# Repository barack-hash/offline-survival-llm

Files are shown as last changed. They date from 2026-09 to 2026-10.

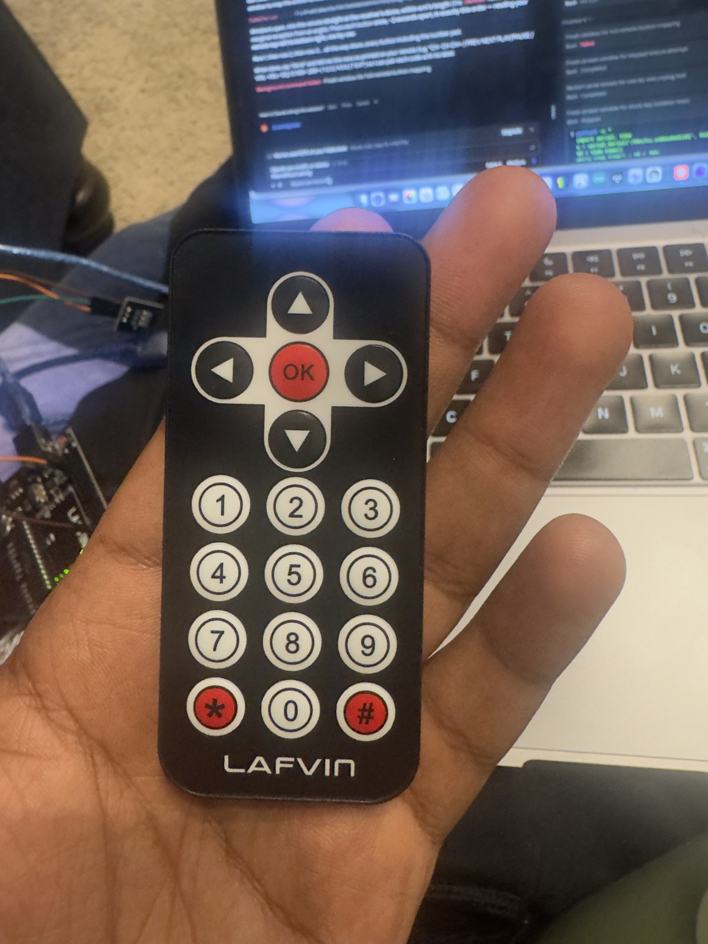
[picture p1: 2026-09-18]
docs/wiring/2026-09-18-ir-remote.jpg

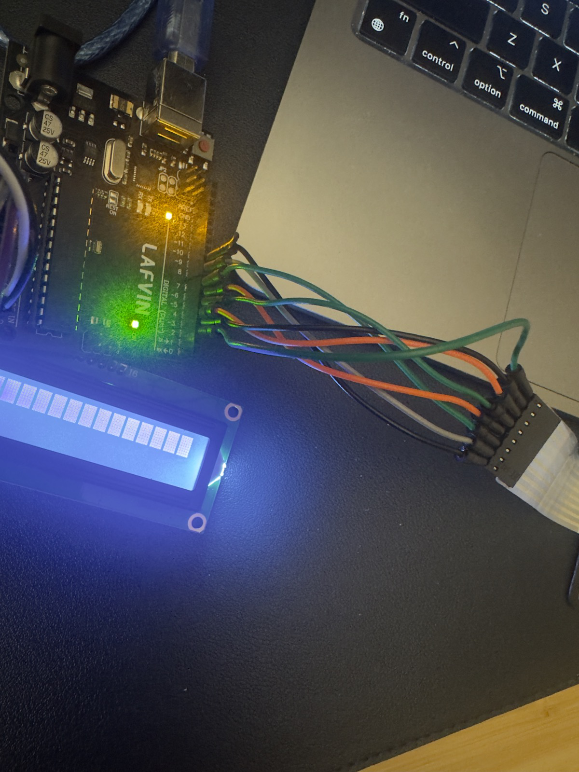
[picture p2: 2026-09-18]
docs/wiring/2026-09-18-uno-lcd-keypad-wiring.jpg

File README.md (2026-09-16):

# Offline Survival LLM Device

A portable, fully offline reference device: Raspberry Pi 5 running a
local LLM (Qwen2.5-3B-Instruct via llama.cpp) grounded in a curated library of
public-domain survival and rebuilding manuals via RAG. Physical keypad
input (Arduino), e-ink display, battery + solar power. Built for use
during outages and disasters — no internet required after setup.

**This device is a reference aid, not a sole authority.** For anything
safety-critical (medical dosing, structural loads, electrical work), it
shows verbatim source text and warns when only one source backs a claim —
and you should still cross-check against a second source before acting.

## Project documents
- `IMPLEMENTATION_PLAN.md` — phase-by-phase build plan with acceptance criteria
- `CLAUDE.md` — operating + logging rules for Claude Code
- `BUILD_PLAN.md` — original architecture and design decisions
- `CORPUS_CHECKLIST.md` — the knowledge library gathering checklist
- `docs/BUILD_LOG.md` — dated journal of every session: mistakes, fixes, decisions
- `docs/HARDWARE.md` — every tool and component used
- `docs/CORPUS_SOURCES.md` — provenance of every reference text

## Status
Phases 0-5a in progress (software brain + keypad input). Awaiting
hardware for: e-ink display (5b), UPS battery (6), enclosure (7).

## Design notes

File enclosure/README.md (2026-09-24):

# Enclosure (Phase 7) — DRAFT v0.6, not print-ready

Parametric OpenSCAD model of a handheld enclosure: 4.2" e-ink screen on top,
CardKB keyboard below, Pi 5 + Geekworm X1202 UPS + 4× 18650 stacked behind
the screen only. Outer size ≈ 109 × 170 mm; **61 mm deep behind the screen,
11.4 mm at the keyboard** (+4 mm standoff feet), joined by a sloped step.

**Airflow:** the Pi faces the back wall so its cooler fan breathes through a
porthole grille; the battery pack sits between the Pi and the e-paper panel
as a heat shield. Cool air in: porthole + low side vents. Hot air out: upper
side louvers + top-edge vents. Feet keep the porthole clear when lying flat.
Toggle **Airflow** in the viewer to see the paths.

**Plumbing is functional:** the copper pipes are cable conduits (3/8" tube).
Left = data line (USB port, AUX I2C accessory port, status-light gauge);
right = power line (6-18 V solar/car input, valve-wheel power button). Both
end at the junction box under the step. The top loops double as corner roll
bars. Wiring plan: `docs/wiring/plumbing-conduits.md`.
Overall with plumbing ≈ 135 × 189 × 67 mm (incl. lanyard tab and feet).

Confirmed from manufacturer specs: e-ink board 103.0 × 78.5, display area
84.8 × 63.6, panel 90.1 × 77.0 × 1.18 (Waveshare manual); CardKB v1.1
88.0 × 54.0 × 5.0 (M5Stack store); X1202 PCB 97.4 × 85 (Geekworm wiki).

**Do not send these STLs to a print service yet.** Several component sizes
come from datasheets and listings rather than the actual parts; each one is
marked `VERIFY` in `enclosure.scad`. When the parts arrive, measure them
with calipers, update the numbers, and re-render.

## Files
- `enclosure.scad` — the model; every dimension is a named parameter
- `render.sh` — re-renders every part and the viewer's `stl/layout.json`
- `stl/` — rendered parts: `tub`, `bezel`, `retainer`, `trim`, `pipes`, `fittings`,
  `manifold`, `manifold_lid`, `gauge_face`, `valve_cap` (printed) and
  `ghost_*` (stand-ins for the electronics, for the viewer only)
- `viewer.html` — 3D viewer (orbit, explode, show/hide parts)

## Re-render
```bash
./render.sh
```
View: `python3 -m http.server 8765` in this folder, then open
http://localhost:8765/viewer.html (the STLs can't load from `file://`).

## Hardware for assembly
- 4× M3 heat-set inserts + 4× M3 button-head screws (bezel to tub)
- 6× M2 self-tapping screws (retainer to bezel posts)
- Optional: rubber caps on the four printed feet
- `trim` (porthole gear ring) and `pipes` (both side pipe runs) print best in brass / copper filament, flat back down; glue on

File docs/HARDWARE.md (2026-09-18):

# Hardware & Tools Register

| Item | Model/Details | Source | Cost | Used for | First used |
|---|---|---|---|---|---|
| Raspberry Pi 5 | Model B Rev 1.1, 8GB RAM, 128GB microSD (117G usable), Debian 13 trixie, kernel 6.18.50+rpt-rpi-2712 | (fill in) | (fill in) | Main compute | 2026-09-15 |
| Active cooler (fan+heatsink) | 4-pin FAN header, ~1150 RPM idle / ~3600 RPM load | (fill in) | (fill in) | Pi 5 cooling — required to avoid thermal throttling during inference | 2026-09-15 |
| Arduino starter kit | LAFVIN Super Starter Kit for UNO R3 | (fill in) | (fill in) | Physical input + interim display | 2026-09-16 (identified from kit box photo) |
| Arduino UNO R3 (from kit) | LAFVIN clone, ATmega328P | kit | — | Input controller: IR decode, multi-tap, LCD driving, serial link to Pi | 2026-09-18 |
| LCD1602 w/ I2C backpack (from kit) | 16x2 chars, I2C addr 0x27, contrast trim on backpack | kit | — | Interim answer display until e-ink (5b) | 2026-09-18 |
| IR remote + receiver (from kit) | NEC protocol, 17 buttons (arrows/OK/0-9/*/#); receiver module pins G/R/Y | kit | — | Text input via multi-tap — replaced the defective keypad | 2026-09-18 |
| 4x4 membrane keypad (from kit) | **DEFECTIVE** — internal shorts, ribbon lines 1-8 and 4-6 permanently closed (stuck 'A'/'0') | kit | — | Unusable; kept as spare parts. Replacement optional (issue #6) | 2026-09-18 |

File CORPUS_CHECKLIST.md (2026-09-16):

# Offline Knowledge Library — Document Checklist

How to use this: for each item, mark it gathered once the actual text file
(.txt or .pdf) is sitting in your `corpus/` folder. "PD" = public domain,
safe to download directly. "OWN" = copyrighted; buy a physical/legal digital
copy and OCR/scan it yourself for personal use — don't download pirated
copies. "FREE" = freely distributed by the publisher for personal/humanitarian
use, but not public domain (check the license before wide redistribution).

---

## 1. Fire & Energy
- [x] U.S. Army Survival Manual, FM 21-76 — fire-starting methods (PD) — in corpus since Phase 3
- [x] Basic solar/wind power primer (any out-of-copyright physics/engineering text, PD) — Powell, Windmills and Wind Motors 1910
- [ ] Notes on your own generator/dynamo build once you've tested it (your own writing)

## 2. Water & Sanitation
- [x] FM 21-76 — water procurement and purification sections (PD) — in corpus since Phase 3
- [x] Where There Is No Doctor (Hesperian) — sanitation chapters (FREE) — full book in corpus (owner-supplied PDF)
- [ ] Basic water filtration / distillation reference (PD engineering text)

## 3. Food & Agriculture
- [x] FM 21-76 — edible/poisonous plants, trapping, fishing (PD) — in corpus since Phase 3
- [x] Old public-domain farming/gardening manuals (pre-1929, archive.org) (PD) — Goodrich, First Book of Farming 1905
- [x] Basic food preservation reference — canning, smoking, drying (PD or FREE) — Gray, Every Step in Canning 1920

## 4. Shelter & Construction
- [x] FM 21-76 — shelter building section (PD) — in corpus since Phase 3
- [x] Basic carpentry/masonry primer, public domain edition (PD) — Fairham, Woodwork Joints 1921 (carpentry; masonry still open)
- [ ] Your own notes once you test any shelter/heating builds (your own writing)

## 5. Medicine & First Aid
- [x] Where There Is No Doctor (Hesperian) (FREE) — owner-supplied PDF, 2026-09-15
- [x] Where There Is No Dentist (Hesperian) (FREE) — owner-supplied PDF, 2026-09-15
- [x] U.S. military first-aid field manual (PD) — FM 21-11 First Aid for Soldiers 1943
- [ ] Basic public-domain herbal medicine reference — flag clearly as unverified/folk knowledge, not medical advice

## 6. Tools & Metalworking
- [x] Public-domain blacksmithing/metalworking texts (pre-1929, archive.org) (PD) — Practical Blacksmithing 1889 + Woodworth 1903
- [ ] Basic mechanics/machining primer (PD)
- [ ] *The Knowledge* by Lewis Dartnell — metallurgy chapters (OWN)

## 7. Chemistry & Materials
- [x] Public-domain basic chemistry textbook (soap-making, basic acids/bases, PD) — McPherson & Henderson 1906
- [ ] *The Knowledge* — chemistry/materials chapters (OWN)

## 8. Electronics & Communication
- [x] Basic electricity/electronics primer, public-domain edition (PD) — Morgan, The Boy Electrician 1913
- [ ] Your own build notes on the generator/battery-charging project (your own writing)
- [x] Basic radio theory reference, if you want this covered eventually (PD) — Collins, Radio Amateur's Hand Book 1922

## 9. Navigation & Orientation
- [x] FM 21-76 — land navigation section (PD) — in corpus since Phase 3
- [x] Basic celestial navigation primer, public domain (PD) — Draper, *Lectures in Navigation* 1917

## 10. Knots, Cordage & Textiles
- [x] Public-domain knot-tying reference (PD) — Verrill, *Knots, Splices and Rope Work* 1912
- [ ] Basic fiber/rope-making and weaving primer (PD)

## 11. Foundational / Cross-Cutting References
- [ ] *The Knowledge: How to Rebuild Civilization in the Aftermath of a Cataclysm* — Lewis Dartnell (OWN) — the single broadest reference; worth prioritizing
- [x] Full FM 21-76 U.S. Army Survival Manual, in case you only grab it in pieces above (PD) — full manual in corpus

---

## Non-corpus documents worth keeping alongside the project
These aren't for the device's library, but you'll want them as you build:

- [ ] **Bill of Materials (BOM)** — running list of every part bought, cost, and source link
- [ ] **Wiring diagrams** — keypad pinout, display connections, power HAT connections (hand-drawn is fine)
- [ ] **Build log** — dated notes on what you tried, what worked, what didn't (this becomes genuinely valuable once you're troubleshooting months from now)
- [ ] **verify.py test question list** — growing over time, as discussed earlier
- [ ] **Corpus source log** — which document came from where, what edition/date, so you can judge reliability later

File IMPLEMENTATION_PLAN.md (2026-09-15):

# IMPLEMENTATION PLAN — Offline Survival LLM Device
Target: Raspberry Pi 5 (8GB / 128GB), currently connected to internet + monitor.
GitHub: github.com/barack-hash/offline-survival-llm
Executor: Claude Code (see CLAUDE.md for logging rules that apply to EVERY phase).

Scope of this plan: everything achievable with hardware on hand today
(Pi 5 + Arduino starter kit). Phases blocked on unpurchased hardware
(e-ink module, UPS HAT, enclosure) are included as stubs at the end so
the repo structure anticipates them.

---

## PHASE 0 — Repository + logging scaffolding
Goal: a clean git repo with logging infrastructure BEFORE any build work,
so nothing goes unlogged from the first command onward.

Steps:
1. Create project directory `~/offline-survival-llm` and `git init`.
2. Create this structure:
   ```
   offline-survival-llm/
   ├── README.md
   ├── CLAUDE.md
   ├── IMPLEMENTATION_PLAN.md   (this file)
   ├── BUILD_PLAN.md
   ├── CORPUS_CHECKLIST.md
   ├── docs/
   │   ├── BUILD_LOG.md         (dated session log — template provided)
   │   ├── HARDWARE.md          (every tool & part used — template provided)
   │   └── wiring/              (photos + diagrams, added as hardware phases run)
   ├── corpus/                  (reference texts; see .gitignore rules)
   ├── models/                  (GGUF files; gitignored, too large)
   ├── scripts/
   │   ├── setup.sh
   │   ├── rag_build.py
   │   ├── main.py
   │   ├── verify.py
   │   └── keypad_serial.ino
   └── .gitignore
   ```
3. Write .gitignore (provided) — CRITICAL rules:
   - `models/` — multi-GB files, never committed.
   - `index.faiss`, `chunks.pkl` — regenerated artifacts.
   - `corpus/own/` — any scanned COPYRIGHTED material (e.g. The Knowledge)
     lives only in this subfolder and is NEVER pushed to a public repo.
     Public-domain texts go in `corpus/pd/` and MAY be committed.
   - `venv/`, `__pycache__/`
4. First commit: scaffolding only. Then create the GitHub repo under
   barack-hash and push. (If `gh` CLI is available: `gh repo create
   barack-hash/offline-survival-llm --public --source=. --push`.
   Otherwise create on github.com and add the remote manually.)
5. Log Phase 0 completion in docs/BUILD_LOG.md per CLAUDE.md rules.

Acceptance criteria:
- [ ] Repo exists on GitHub with scaffolding pushed.
- [ ] BUILD_LOG.md has its first dated entry.
- [ ] .gitignore verified by `git status` showing models/ and corpus/own/ untracked.

---

## PHASE 1 — System verification & prep
Goal: confirm the Pi is healthy and configured before heavy installs.

Steps:
1. Record in docs/HARDWARE.md: Pi model, RAM, storage, OS version
   (`cat /etc/os-release`, `uname -a`, `free -h`, `df -h`, `vcgencmd measure_temp`).
2. `sudo apt update && sudo apt full-upgrade -y`.
3. Enable SPI via `sudo raspi-config nonint do_spi 0` (needed for e-ink later).
4. Confirm active cooling works: run `stress` or a build for 2 minutes,
   log idle vs load temperature in BUILD_LOG.md.
5. Commit any config notes; log the session.

Acceptance criteria:
- [ ] OS fully updated; reboot clean.
- [ ] SPI enabled.
- [ ] Idle + load temperatures logged (expect roughly 45-55°C idle, under
      75°C load with the official cooler; log whatever is observed).

---

## PHASE 2 — LLM engine
Goal: llama.cpp built from source, model downloaded, benchmarked, working.

Steps:
1. Run `scripts/setup.sh` (builds llama.cpp, downloads Phi-3 Mini Q4 GGUF
   ~2.3GB, creates Python venv with dependencies).
2. If the model URL 404s (Hugging Face paths change): search Hugging Face
   for "Phi-3-mini-4k-instruct-gguf" Q4 quantization, update the URL in
   setup.sh, and LOG THE CHANGE as a challenge+fix in BUILD_LOG.md.
3. Benchmark: run llama-cli with a fixed test prompt, record tokens/sec
   for prompt processing and generation. Log exact numbers.
4. Log RAM usage during inference (`free -h` in a second terminal).
5. Commit setup.sh if modified; log the session including benchmark table.

Acceptance criteria:
- [ ] Model answers a test question from the command line.
- [ ] Benchmark logged (expect roughly 5-10 tok/s generation; log actuals).
- [ ] RAM headroom confirmed (expect >3GB free during inference).

---

## PHASE 3 — Knowledge corpus + RAG index
Goal: real public-domain reference texts indexed and searchable.

Steps:
1. Create `corpus/pd/` and `corpus/own/` folders.
2. Download public-domain sources per CORPUS_CHECKLIST.md, starting with:
   - U.S. Army Survival Manual FM 21-76 (public domain; archive.org hosts it)
   - At least one more PD text (old farming/blacksmithing manual from archive.org)
   Log EVERY source in docs/BUILD_LOG.md AND a new docs/CORPUS_SOURCES.md:
   filename, origin URL, edition/date, license status (PD/FREE/OWN).
3. Run `scripts/rag_build.py`. Log chunk counts per source and total
   index build time.
4. Spot-check retrieval: query 3 known topics (fire, water purification,
   shelter) and confirm relevant chunks return. Log results.
5. Commit corpus/pd files + CORPUS_SOURCES.md; log the session.

Acceptance criteria:
- [ ] At least 2 PD sources indexed.
- [ ] index.faiss + chunks.pkl generated (untracked by git).
- [ ] 3 spot-check retrievals logged with pass/fail judgment.

---

## PHASE 4 — Main application + verification loop
Goal: full ask→retrieve→answer pipeline working in the terminal, with a
growing test suite.

Steps:
1. Run `scripts/main.py` in keyboard mode. Ask 10 varied questions
   spanning: normal survival topics, a safety-critical topic (to confirm
   strict mode triggers + shows verbatim sources), and a topic NOT in the
   corpus (to confirm it says "not in sources" rather than hallucinating).
2. Log every question + answer + verdict (good / vague / wrong / hallucinated)
   in BUILD_LOG.md. This is the single most valuable log content in the
   whole project.
3. For each failure found, make ONE tuning change at a time (prompt wording,
   TOP_K, chunk size, keyword list), re-test, and log change→effect.
4. Add the best test questions into scripts/verify.py's test_cases list.
5. Commit tuning changes with descriptive messages; log the session.

Acceptance criteria:
- [ ] 10-question evaluation logged with verdicts.
- [ ] Critical mode confirmed triggering and showing raw sources.
- [ ] Out-of-corpus question correctly declined, not hallucinated.
- [ ] verify.py contains at least 5 real test cases and runs clean.

---

## PHASE 5a — Physical input (Arduino keypad)
Goal: questions typed on real hardware buttons instead of a keyboard.

Steps:
1. Wire the starter-kit 4x4 matrix keypad to the Arduino per the pin map
   in scripts/keypad_serial.ino. PHOTOGRAPH the wiring; save to docs/wiring/.
2. Flash keypad_serial.ino via Arduino IDE. Log IDE version, board type,
   any library installs (Keypad library), and any upload problems + fixes.
3. Connect Arduino→Pi via USB. Identify the port (`ls /dev/ttyACM*`).
4. Set INPUT_MODE = "serial" in main.py, run, and type a question on the
   keypad. Log the first successful hardware-typed question verbatim —
   that's a milestone worth recording.
5. Known limitation to log honestly: digits + A-D only until multi-tap
   letter entry is implemented. Create a GitHub issue for multi-tap as
   the next input improvement.
6. Update docs/HARDWARE.md (Arduino board, keypad, cables). Commit; log.

Acceptance criteria:
- [ ] Wiring photo in docs/wiring/.
- [ ] A question asked entirely via keypad receives an answer.
- [ ] Multi-tap letter entry filed as a tracked issue.

---

## PHASE 5b — E-ink display integration  [STUB — awaiting hardware]
When the ELECROW ESP32-S3 2.13" e-paper module arrives:
- Firmware sketch for the ESP32-S3 (serial listener → render text).
- main.py output routed to second serial port.
- Wiring/pairing notes + photos to docs/wiring/.

## PHASE 6 — Power system  [STUB — awaiting hardware]
When the Pi 5 UPS HAT + 18650 cells arrive:
- Runtime measurement vs the theoretical ~5hr estimate; log actuals.
- Wi-Fi/BT disable script + CPU governor for battery mode.
- Safe-shutdown-on-low-battery configuration.

## PHASE 7 — Enclosure  [STUB — awaiting materials]
- Dimension sketch once display size is physically confirmed.
- Steampunk build log with photos at every assembly step.

---

## Definition of "done" for the current hardware scope
Phases 0-5a complete, every acceptance criterion checked, every session
logged, repo pushed, and stub issues created on GitHub for 5b/6/7 so the
project board reflects reality.

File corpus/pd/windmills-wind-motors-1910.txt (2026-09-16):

Google 

This is a digital copy of a book that was preserved for generations on library shelves before it was carefully scanned by Google as part of a project 

to make the world's books discoverable online. 

It has survived long enough for the copyright to expire and the book to enter the public domain. A public domain book is one that was never subject 

to copyright or whose legal copyright term has expired. Whether a book is in the public domain may vary country to country. Public domain books 

are our gateways to the past, representing a wealth of history, culture and knowledge that's often difficult to discover. 

Marks, notations and other maiginalia present in the original volume will appear in this file - a reminder of this book's long journey from the 

publisher to a library and finally to you. 

Usage guidelines 

Google is proud to partner with libraries to digitize public domain materials and make them widely accessible. Public domain books belong to the 
public and we are merely their custodians. Nevertheless, this work is expensive, so in order to keep providing tliis resource, we liave taken steps to 
prevent abuse by commercial parties, including placing technical restrictions on automated querying. 
We also ask that you: 

+ Make non-commercial use of the files We designed Google Book Search for use by individuals, and we request that you use these files for 
personal, non-commercial purposes. 

+ Refrain fivm automated querying Do not send automated queries of any sort to Google's system: If you are conducting research on machine 
translation, optical character recognition or other areas where access to a large amount of text is helpful, please contact us. We encourage the 
use of public domain materials for these purposes and may be able to help. 

+ Maintain attributionTht GoogXt "watermark" you see on each file is essential for in forming people about this project and helping them find 
additional materials through Google Book Search. Please do not remove it. 

+ Keep it legal Whatever your use, remember that you are responsible for ensuring that what you are doing is legal. Do not assume that just 
because we believe a book is in the public domain for users in the United States, that the work is also in the public domain for users in other 
countries. Whether a book is still in copyright varies from country to country, and we can't offer guidance on whether any specific use of 
any specific book is allowed. Please do not assume that a book's appearance in Google Book Search means it can be used in any manner 
anywhere in the world. Copyright infringement liabili^ can be quite severe. 

About Google Book Search 

Google's mission is to organize the world's information and to make it universally accessible and useful. Google Book Search helps readers 
discover the world's books while helping authors and publishers reach new audiences. You can search through the full text of this book on the web 

at |http: //books .google .com/I 

> 

WINDMILLS 

AND 

WIND MOTORS 

HOW TO 

BUILD AND RUN THEM 

BY 

F. E. POWELL 

Folly Illustrated with Detail Drawimo* 

NEW YORK 

SPON & CHAMBERLAIN 

123-125 LIBERTY STREET 

1910 

(N<x 36.) 

• Copyright, 1910 

By SPON & CHAMBERLAIN 

GAMELOT PRESS. 444-46 Pearl Street, New York 

PREFACE 

I have endeavoured in the following pages not 
only to interest the practical amateur in a branch 
of mechanics unfortunately much neglected, but 
also to present a series of practical original de- 
signs that should prove useful to every reader 
from the youngest to the most advanced. This 
is admittedly a large undertaking, and would be 
of doubtful wisdom, but for the sparseness of the 
literature of the subject. There is, however, 
no other book in the language, large or small, 
dealing with the matter in the way here pre- 
sented, and indeed only one other, as far as I 
know, having the subject of windmills for its 
sole topic. I venture to hope therefore that this 
little book will help to arouse something of the 
interest the subject deserves but has not hitherto 
received. 

That I am right in claiming for the wind 
motor a more serious recognition I am con- 
vinced, and particularly is this the case in re- 
"•^rd to the model engineer. At present there 
every prejudice against wind-power on ac- 
count of its uncertainty, against which even its 

inexpensiveness has not been able to contend. 

... 
Ill 

IV PREFACE 

If it can once be realised, however, that the un- 
certainty can be reduced to little or no import- 
ance, so much that even a petrol-engine might 
seem unreliable and troublesome beside it, the 
claim put forward for the windmill is fully sub- 
stantiated. Not less than this is one of the aims 
of this little book, and it is one which I confi- 
dently expect will be upheld. 

In a book like this, trenching upon new ground, 
where every design has been the outcome of 
careful consideration unaided by the experience 
of others, it is not unlikely that errors or am- 
biguities may have crept in. The reader who 
finds any such, or who meets with difficulties of 
any sort, will confer a kindness by communicat- 
ing them to the author through the publishers. 

R E. POWELL. 

CONTENTS 

PAGE 

Preface iii 

CHAPTER I 

WINDMILL EVOLUTION 

Ancient post-mill. Tower mill. Tower mill 
with regulating or wind-wheel. Modern 
type of windmill. Anemometer. Jumbo or 
horizontal windmill. Wind-motor with ver- 
tical axle. The pantanemone i 

CHAPTER H 

A MODEL WORKING WINDMILL 

Tower mill type. Fixed sails without tail 
regulator. Diameter across sails, two feet. 
Full detailed drawings 1 1 

CHAPTER HI 

A SMALL AMERICAN TYPE WINDMILL 

This type has fixed metal sails three feet in 
diameter, with tail regulator. Develops 
about Yso H.P. Full detailed drawings 22 

VI CONTENTS 

CHAPTER IV 

A SMALL WORKING WINDMILL 

PAGE 

Automatically reversing sail type. Diameter 
across sails, six feet. Develops about Ko 
H.P. Suitable for pumping water or for 
running a lathe. Full detailed drawings. . . 37 

CHAPTER V 

A PRACTICAL WORKING WINDMILL 

A simple and compact wind-power motor with 
adjustable sails and tail regulator. Diam- 
eter across sails ten feet. Will develop 
from one-quarter to one-half horse-power, 
according to the velocity of the wind. Suit- 
able for pumping water, driving a dynamo 
or light farm machinery. Full detailed 
drawings 48 

CHAPTER VI 

PRODUCTION OF ELECTRICITY BY WIND-POWER 

Diagram of connections for a wind-driven 
electrical installation. Driving belt ar- 
rangement for wind electrical plant. Table 
of wind pressures and velocities 65 

CHAPTER I 
Windmill Evolution 

It is not a little strange that amateur engi- 
neers should have so neglected the windmill, 
either as a subject for model-making and experi- 
ment, or even for the more practical purpose 
of power production. Wind-power is free, and 
while it is admittedly erratic it must surely ap- 
peal to the mechanical, mind as a labour saver 
of some value. The probability is that the lack 
of simple published designs is the main reason 
for this state of things, and the aim of this little 
book is to remedy it. 

Few mechanical appliances have a simpler his- 
torical record than the windmill. Until com- 
paratively recent years only two main types of 
mill were ^9mmonly in use, known respectively 
^|nd the Tower mills, vhe former, 
is the earlier machine, was distinguished 
by the fact that the whole building, carrying 
sails, house, cap, and all machinery, was pivoted 
on a huge timber post, so that the whole struc- 
ture had to be removed when it was necessary 
to adjust the mill to face the windJ The Tower 
mill, called also the " Smock " and sometimes 
the " Frock " mill, was an improvement on the 

2 WISDMILLS- AXD WISD MOTORS 

Other in having the cap only to revolve, carrjing 
with it the sails and (later) the automatic regu- 
lating mechanism for bringing the sails round 

" into the wind." Illustrations of these two 
types of mills are given in figs, i and. 2. 
/ As hinted above, the automatic method of con- 
I trolling the mill so that the sails should face the 
1 wind was a fairly recent innovation. It dates 
I back to the middle of the eighteenth century, 

WINDMILL EVOLUTION 

when Andre w Meikle introduced the now well- 
ktlown auxiliary 'regulating wheel, which may 
be seen in fig. 3 

Fig. 2.— Tower Milt: at Hillerod, Denmark. 

Another advance in windmill construction was 
made in 1807, when Sir W, Cubitt introduced an 
automatic reefing arrangement for the sails. Be- 

4 WINDMILLS AND WIND MOTORS 

fore that date speed was more or less outside 
the control of the operator, who could only throw 
in or out his machinery as the speed ranged too 

Fig. 3.— Towi 

with Regulating or Wind Wheel. 

high or too low, or by the application of brakes 
could keep it partly within bounds. 

The later history of the development of wind- 
mills must be looked for abroad. The inventor 
of the "American" mill is said to have been 
John Burnham, whose location is sufficiently in- 

WINDMILL EVOLUTION 5 

dicated in the name by which this type is known. 
The date was about the middle of the nineteenth 
century. Everyone knows that the distinction 
between the older types and the modem trans- 
atlantic machines lies in the number and dis- 
position of the sails, which in the latter are nu- 
merous and form a comparatively narrow ring of 
vanes. A modem example of such a mill Is 
illustrated in fig. 4. Since Bumham's day in- 
ventors have not been asleep, and the multitude 
of so-called American mills now on the market 
is evidence of their skill. These machines vary, 
however, only in details of design, regulation, 
and control, not in any essential character. 

The American mill, though not much more 
efficient than its older competitor, has the ad- 
vantages^of. cheapness, a more even turning move- 
inent, and easier starting. The defects, espe- 
cially^ in the matter of economy, of all types of 
windmills led to a very remarkable series of ex- 
periments which were carried out by the Danish 
Government from 1891 until the death of the 
chief investigator, Prof. Poul la Cour, in 1908, 
brought them to an end. The work done by 
this enthusiastic engineer included not only the 
improvement of windmill details,,.but also a prac- 
tiQal inquiry into the possibility of utilising 
W4nd-power in the production of electrical en- 
ergy. Much of the collected data is naturally 
negative in its results, but students of the sub- 
ject must always look with warm admiration on 

e WIin>HILLS AND WIND MOTORS 

the patient work of La Cour and the good sense 
of the State that assisted him 

As far as this book is concerned, the Danish 

Fig 4— Modern Tjpe of W mdmill 

experiments have one special bearing. They 
proved that for maximum f^wcr and speed the 
modern multi-sailed machines could not com- 

WlsnMlLL EVOLUTION 7 

pete with a four- 01 six-armed mill of modified 
design. This type is comparatively easy to con- 
struct in a modified form, and has so many ad- 
vantages that one or two designs in the follow- 
ing pages have been based upon it. 

Besides the standard types of windmills pre- 
iriously mentioned, many other wind motors 

Fig. S- 
Diagram of Anemometer. 

Fig. 6. 
Alternative Cups. 

have been suggested and used at times, and de- 
serve at least brief notice. One of the simplest 
of these is the ordinary anemometer used for 
measurement of wind velocities (see fig. 5). It 
consists of four hemispherical cups carried on 
cross-arms, which are pivoted at their junction 
and moved by the superior resistance offered by 
the concavity of any one of the cups facing the 
wind. It will of course start in a wind of any 
direction whatever in the plane of its revolution, 
but has no pretension to power production. The 

8 WINDMILLS AND WIND MOTORS 

hemispheres may be replaced by small (tin) 
cones (fig. 6), which are more easily made. 

Another windmill of extreme simplicity, which 
has sometimes been made of a large size, illus- 
trated in fig. 7, is called a " Jumbo." The small 
illustration in the corner of fig. 7 is a diagram- 

Fie 7. — "Jumbo," or Horizontal Windmill. 

matic end view of this type of motor. Arrows 
show the direction of wind and of rotation. The 
action is sufficiently indicated in the sketch, and 
it need only be pointed out that the great dis- 
advantage is that it will only work with certain 
winds. It is also necessary to have a large open 
space free from trees or buildings if the best 
results are looked for. 

WINDMILL EVOLUTION 9 

A modified form of the last machine is that 
shown in fig. 8, which has four or more sails 
mounted on a vertical shaft and arranged with a 
semicircular shield which runs on a circular path 
so that the vanes can be acted upon by the wind 
on one side only. Obviously the advantage in 

Fta. 8,— Wind Motor with Vertical Axle. 

this case is that winds of any direction can be 
made to perform work, but the type has never 
been developed to any extent. 

Another wind motor worth illustrating is, 
however, rather more curious than useful. This 
is thcpaiitanemone, shown in fig, 9, It consists 
simply of two semicircular discs whose diam- 
eters are placed at right angles to one another, 
the shaft bejng between them, in the same plane 
as the diameters, but at 45° to each of them. 

to 

WINDMILLS AND WIND MOTORS 

The amater may be interested to make a model 
on these lines, which, while without practical 
value, is interesting for the fact that the machine 
will start in wind of any direction. 

Other wind motors there are, of varying inter- 

Fic 9, — The Pantanenlone. 

est and usefulness, including a quite modern 
development on the lines of a turbine, which has 
not yet seen the light of a manufacturer's work- 
shop. Space, however, is too valuable to be 
given to any but well-tried designs, although 
much interesting experimental work remains to 
be done in this connection on systematic lines. 

CHAPTER II 

A Small Working Model Windmill. Tower 

Mill Type 

Considering the simplicity of a windmill model 
and the fact that it will not easily get out of 
order, it is surprising that more amateurs do 
not turn their hands to its construction. A 
windmill with sails of only 2 feet diameter, such 
as will now be described, will develop in even a 
moderate breeze fully as much power as an aver- 
age steam-engine with cylinder say i inch stroke 
by |-inch diameter, and will therefore be quite 
powerf ul e nough to drive a model workshop, 
work. a_ model crane, or do other similar light 
WQrk±_.An interesting combination suitable for 
outdoors, where of course the windmill must 
work, would be a model railway arranged on an 
incline so that by means of a long cord the mill 
might be made to draw up a train to the top of 
the slope, the descent being made by gravity. 
This is not the place to enter into details, which 
nevertheless would not be very abstruse and 
would form an interesting problem to be carried 
out by the young mechanic. 
• Too much importance should not be attached 
to the idea that wind is unreliable as a motive V 

II 

12 WINDMILLS AND WIND MOTORS 

force^ _ It will be found more reliable than is 
usually supposed, and apart from that the sim- 
plicity of construction, in which no lathe and 
very few tools are required, as well as the ab- 
sence of cost in working, should all go to make 
the model windmill a popular object. 

The design shown in fig. lo is for a model of 
the size already mentioned, namely, with sails 
24 inches across the tips. It will be of course 
quite easy for the reader to make his model 
either larger or smaller, if he so desires, by tak- 
ing care to increase or decrease the dimensions 
of all parts in proportion. In a model like this 
it would only be introducing unnecessary com- 
plication if any attempt were made to provide 
the adjustments usual in large mills, and indeed 
it is quite possible that such regulating gear 
would take all the available power of the machine 
to work it. The design therefore dispenses with 
any such elaborations, but the maker can, if so 
disposed, and without any great difficulty, ar- 
range for the top of the mill to turn automati- 
cally, so that the sails always face the wind. A 
study of the later chapters of this book will show 
how this can be done. <_ 

* Almost all the materials used in the construc- 
tion are cardboard and wood, so that the model 
is not intended to be left permanently out in all 
weathers. If this should be desired, a larger 
use of wood must be made, and tin or sheet-iron 
well painted should also enter into the construe- 

14 WINDMILLS AND WIND MOTORS 

tion. The baseboard in any case should be a 
substantial bit of timber, weighted if necessary, 
or otherwise, well secured to avoid overturning 
in a strong breeze. 

The main part of tower is formed of stout 
cardboard, which should be well varnished after 
erection. It is cut out as shown in fig. 12, and 
slight cuts along the division lines will enable 
the eight sides to be formed up. A strip of 
stout paper glued inside and outside will com- 
plete the joint. Note that the outside strips 
should be cut very neatly and all the same 
widths. They will then take the appearance of 
the finishing boards usually fitted at the corners 
of a wooden building. While still in the flat, 
the various windows, doors, etc., should be pen- 
cilled firmly on the diflferent sides, and particular 
care taken to fix any fitments for crane or other 
details. The whole model can be made very 
realistic if some little time is spent in lining out 
the tower and cap to represent weather-board- 
ing, or, if preferred, in the case of the tower, 
stone or brick. Pencil lines will be best, and 
colour may be put on to enhance the eflfect. 
Some idea of the eflfect to be aimed at is indi- 
cated in the lower part of fig. 11. 

The top and base of tower will be octagonal 
in plan, as shown in sketches, fig. 13. 

Details of the head or cap are given in fig. 14, 
which, together with fig. 11, will give a good idea 
of the manner of construction. Fig. 15 shows 

BACK END 

DETAILS OF HEAD OR CAP 

SCALE a/4"=1 FT. 

Fig. 14 

a ^ 

PLAN 

\.s?./ 

SLrCINO BEARING 

Fig. 12- Diagram for Setting-out Tower. < "o^ to sc*te > 
Fig. 13- Top and Base of Tower. 
Fig 14 - Views of Head or Cap. 
Fig 15 -Shape of Card for Roof of Cap. 
Fig 16 "Sliding Bearing. 

A SMALL WORKING MODEL WINDMILL I^ 

the shape of the two pieces of card to form the 
roof of cap before bending to shape. 

Pieces of cigar-box wood or thin pine form the 
base and ends of cap, and should be joined by 
very thin nails or stout pins, some deal sticks 
about ^-inch square being used as spreaders or 
stiffeners. The ends must be carefully set out 
from centre lines, and holes nicely drilled and 

T" 

«r» 

J, 

1 

(1 
1 

1 

t 

- 

<r Cf^^i" 

.t. 

-V. J/ 1 

4 OFF 

SCALE 3" — 1 

Fig. 17. — Shape of Sail for Model WindmilL 

cut to the dimensions given. Their uses will be 
apparent presently. One side of the roof should 
be made to open with a hinge of calico to enable 
the working parts to be got at. 

Details of the arms and sails are given in figs. 
17, 18, and 19, and readers unfamiliar with the 
" setting " of windmill sails should carefully 
study the drawings before shaping the arms. 
As shown in fig. 18, the sails are not placed cen- 
trally on the arm, which is much nearer one edge 
than the other. This is shown in the sectional 
view of arm and sail in fig. 18. Then also the 
two sails on one arm point opposite ways, which 
is perhaps best seen in the perspective sketch, 

l8 WINDMILLS AND WIND MOTORS 

fig. ID. The amount by which the sail lies out of 
the plane of revolution is called its "angle of 
weather." To obtain this setting, each arm is 
bevelled away, the two ends being bevelled in 
opposite ways. Fig. 19 shows this, and the 
reader has only to imagine each arm brought 
successively into the same position, say the top, 
to realise how the bevel must always be the 
same way with the arm in that position. Fig. 
20 will also be helpful in making this clear. A 
portion of the arm at its middle is left the full 
square section (see figs. 18 and 20, which show 
this). Every care must be taken to make the 
bevelling correctly, or one pair of sails would 
be found bevelled one way and the other in the 
opposite way. This would of course result in 
nullifying the effect of both. The axle, shown 
in various figures, especially 18, 21, and 22, is 
made of a piece of hard wood like oak or hick- 
ory, and is shaped specially to take the two arms 
as indicated in fig. 22. Care must be used not 
only to cut this out true and a good fit, but also 
not to break the thin prongs. The shaft must 
be nicely rounded and sand-papered smooth. At 
the collar portion, which will form the forward 
bearing, a little paraffin wax should be melted 
into the grain to reduce running friction, or, 
better still, a thin brass ferrule fitted, as shown 
in fig. 18. 

The arms, in addition to being glued in place, 
must be further secured by wooden pins, and 

20 WINDMILLS AND WIND MOTORS 

every care must be taken not only to fit them 
correctly according to the bevels, but also to 
get them dead square with the shaft and with 
each other. The use of an ordinary set-square 
will accomplish this. Both arms, as shown in 
fig. 22, are slightly " checked " or " halved " into 
each other, both to lock them more securely and 
to reduce the overhang of shaft. Notice should 
be taken that the cutaway is in the back of front 
arm and front of rear arm. 

The sails should be both glued and pinned to 
the arms for security and a pencil line at the 
t' right place on back of each sail will ensure get- 

ting them correctly placed. Each sail, previous 
to being mounted, should have parallel lines, 
about half an inch apart, drawn across both faces 
to imitate the slats generally used in large' mills 
of this type. After mounting, and when glue is 
firm, the sails and outer ends of shaft should 
have a couple of coats of good thin varnish to 
enable them to stand some weather. 

It may here be remarked that when pins are 
used instead of nails they will be found much 
easier to drive if a quarter of an inch of the sharp 
point is nipped off. If this is not done, they are 
almost sure to bend. 

It will be seen that the tail end of shaft is pro- 
vided with a metal bearing or journal in the form 
of a small headless nail. This must be let in bv 
first very carefully boring an axial hole in shaft, 
preferably with a twist drill, the end of shaft 

A SMALL WORKING MODEL WINDMILL 21 

being bound round to avoid splitting. This jour- 
nal runs in a tin bearing (fig. i6), which is made 
to slide stiffly up and down in the slot in back 
of cap. This allows the owner to put in or out 
of gear the winding shaft by means of which 
the mill is caused to perform useful work. This 
is accomplished through the disc A, fig. ii, fixed 
on the winding shaft, a rubber band in circum- 
ference of disc and thin rubber sleeve on main 
axle being provided to ensure sufficient adhe- 
sion. The winding shaft runs in two metal or 
wood bearings, and has the end of a strong 
thread secured to it for a rope. The other de- 
tails for the working of this part of the apparatus 
are perhaps shown clearly enough in the draw- 
ings. 

If carefully and neatly made, it is wonderful 
how interesting such a model will prove. In a 
stiff breeze the sails will revolve at a great rate, 
and the crane will lift say half a pound at a good 
speed. Weights will of course be in the form of 
small sacks of material, boxes, barrels, etc., and 
the crane should be made capable of slewing so 
that the loads can be deposited where required. 
Even in the light winds it is of interest to see 
the sails moving gently round, and indeed at 
such a time the appearance is rather more real- 
istic, which may partly compensate for the 
lessened utility. 

CHAPTER III 
A Small American Type Windmill 

The design given in this chapter is intended to 
form a link between the model pure and simple 
and the "small power" mill able to perform 
solid work. It has been thought desirable to 
admit a certain amount of pattern-making and 
machining in this case, as a windmill of this size 
ought to be made on " practical " lines, although 
it is as simple as possible in construction, and 
quite within the range of the amateur with a 
small back-geared lathe. The outside diameter 
of the sails is 3 feet. 

As in all the other cases, the present design 
may be modified here and there to suit individ- 
ual fancies, and it may also be reduced to form a 
very pretty model or enlarged to any reasonable 
size. Of course, any such change will involve 
certain alterations in sizes of parts — not neces- 
sarily to scale, as, for example, in the case of a 
mill three times the size, the thicknesses of metal 
would not in all cases need to be three times as 
great. 

A small machine like this may be recom- 
mended particularly for experimental work. The 
horse-power available in the usual 16-mile breeze 

22 

A SMALL AMERICAN TYPE WINDMILL 23 

may be estimated at %o H.P., but this may easily 
be doubled in any stiffish wind, so that for many 
small matters the power is not to be despised. 
With an efficient pump quite a respectable 
amount of water can be lifted, or an old boiler 
may be pumped up with air pressure, which will 
thus be available for running model steam-en- 
gines, or for testing purposes, or even a small 
blow-lamp, etc. There is no reason why a model 
dynamo and accumulator plant should not be 
designed to utilise the power. On an average, a 
breeze of i6 miles per hour or over is available 
for quite six hours a day throughout the year. 
Now a mill of the size here described would run 
a 6-watt dynamo easily, if of good, efficient con- 
struction ; so that the normal output for a week's 
work would be 6 watts X 6 hours X 7 days= 
252 watt-hours, provided the accumulator were 
able to store all it received. Such a result would 
be quite attainable during the majority of weeks 
in a year. 

To get the above result some simple apparatus 
in the way of automatic cut-in and cut-out gear 
would be required, and the cells would probably 
have to be so connected that they could be 
charged in parallel and discharged in series. 
Thus, the stored energy might be utilised at the 
rate of 24 volts, in which case the owner would 
be able to get a return of say 2.5 amperes for 
four hours (24 V. X 2.5 amp. X 4 hours = 240 
watt-hours). Undoubtedly there are many cases 

24 WINDMILLS AND WIND MOTORS 

where such a result would be regarded as of 
great utility in the amateur's workshop. Some 
attention will be paid in the later pages of this 

" American." Windmill : Front View of 
Wheel. 

book to the detailed apparatus necessary to this 
end. 

The American type of mill has been adopted 
in the present instance as much for variety as 
for other reasons. It is not noticeably more 

26 WINDMILLS AND WIND MOTORS 

efficient than some other fonns, but lends itself 
to simplicity of construction. No attempt has 
been made to have the sails self- regulating, but 
a tail has been adopted in order to keep the mill 
automatically head to wind, and this makes it 

easy to regulate the speed by hand or to throw 
the mill out of work entirely when desired. This 
refinement can, however, be dispensed with if 
desired. The size of the wheel is 3 feet in diam- 
eter, and its normal speed in a 16-mile breeze 
should be from 200 to 250 revolutions per minute. 
Front and side views of the complete mill are 
shown in figs. 23 and 24 respectively. The whole 

A SMALL AMERICAN TYPE WINDMILL 27 

of the mill has been designed in metal, as it is 
intended for constant outdoor work in all 
weathers. 

Commencing witli the " tower," this has been 
reduced to the simplest form by making use of 

Fig. 28.— Plan of ihe above- 

a piece of old 2-inch gas-, water-, or steam-pipe 
about 3 feet long.. It is desirable that this should 
have been galvanised, and it must of course be 
quite straight. The tube is carried in a strong 
wooden framework of 11 X i boards and some 
2X2 scantlings, so that it can revolve therein 
without shake or " give," since it will form the 
movable part of the mill and will carry the whole 
of the gearing. This wooden framing appears 
in fig, 24, and is further illustrated in perspective 
and in plan in figs. 27 and 28 respectively. 

The construction of the wheel is indicated in 

so WINDMILLS AND WIND MOTORS 

the vertical section through it in fig. 25 (which 
is twice the scale of the general arrangement, 
fig. 24), and also in the perspective drawing, fig. 

Fig. 29.— Perspective Sketch of Wheel and Sails of Model 
" American " Windmill. 

29. A hub, formed from three pieces of board, 
and turned 6 inches diameter, is secured to the 
shaft by means of an iron strip laid in the saw- 
cuts in end of shaft, as shown in fig, 30. Nails 
or screws make the three pieces of wood practi- 
cally one solid whole. 

A SMALL AMERICAN TYPE WINDMILL 

29 

Referring to fig. 29, it will be seen that the 

Fig. 30. — Method of Securing Hub on End of Shaft. 

wheel is carried by arms or spokes of f-inch X 
346-i"ch galvanised hoop-iron. Six of these 
spokes start from each side of hub, those on the 

Fig. 31.— Wire Rings for Wheel: Upper Diagram, Outer 
Rings; Lower Diagram, Inner Rings. 

front side being made of three full-length strips, 
as seen in figs. 23 and 26. Turning to fig. 25, it 
will be seen how these spokes cross from front 

30 WINDMILLS AND WIND MOTORS 

to back, and vice versa. They are also soldered 
to four rings, clearly shown in fig. 29, wherever 
they cross these latter, and these rings are so 
designed as to carry the sails between them. 
The rings are of No. 6 B. & S. galvanised fenc- 
ing wire, carefully curved to accurate diameters 
— the outer 36 inches, and the inner 18 inches — 
and ends overlapped 2 or 3 inches, bound with 
fine wire and soldered together. The proper 
distances apart of the two sets of rings are ij 
inches and J inch respectively, as shown in fig. 
31, which shows also the angle at which the sails 
will lie between them, namely about 25**. The 
shape of the sails themselves is shown in fig. 
32: they should be of thin sheet-zinc, the four 
corners slightly bent to lie flat against the wire 
rings to give rather more surface for soldering. 

If the mill is to be used for " power " produc- 
tion in the ordinary way, it is very difficult to 
find a better means of transmitting the energy 
than by the usual method of bevel-wheels, as 
shown in fig. 24. The exact ratio of one wheel 
to the other is only determined by the require- 
ments of the case, and as shown in the drawings 
the vertical shaft would make three revolutions 
to two of the axle. The wind-wheel and its axle 
are carried in a light iron-casting, given in de- 
tail in fig. 33, the lower end of which is bored 
out to fit tight on the main 2-inch upright tube. 
The manner of this fitting, and the arrangement 
of bevel-wheels and brass bearings for upper and 

-1^^ 

^- 

■H*r"?^^?rf^-^" 

Fig. 33. Head Casting (Iron). 

Fig. 32 Shape of Sails for Model ■American" 

A SMALL AMERICAN TYPE WINDMILL 

33 

lower ends of vertical spindle, are shown in fig. 
34. There is nothing special in any of these 
parts, which are all simple turned work. 

The machine may be also used to pump water, 

FlC. 36. — Side View of Eccentric for Pumping Gear, 
in which case probably the simplest plan is to 
fit a small eccentric on wind-axle working a con- 
necting-rod with a small pump in lower end of 
2-inch tube. To save the reader trouble in de- 
signing, a simple eccentric, strap, and rod are 
shown in figs. 35 and 36, giving a lift of i^ 
inches, which of course can be varied to suit the 
needs of the maker. Too great a lift must be 
avoided, owing to the speed at which the pump 

34 

WINDMILLS AND WIND MOTORS 

will work. Care must be taken to make the 
casting (fig. 33) higher than shown, if neces- 
sary to enable the eccentric to clear (see fig. 35). 

NO. 28 B. A 8. QAUOE 
OALV. IRON SHEET 

SCREW 
V4"l.0«0 
»/,"OIAM. 

■" CEN8. 

1—1- 

H-^-J 7^ 

SCALE 1V2"- 1 ft. 

z: 

HOLE .,f/ 

FULL Vb" / /" ^^^"^ ^O*-"*" 

TWO 1/4" RIVETS 

quadrant cut from 
Vi6"galv. plate 

GALV'D ANGLE IRON 
Vie" THICK 

r SECTION 

Fig. 37. — Elevation and Plan of Tail Regulator. 

Details are given in the drawings, and are prob- 
ably clearer than written explanations. 

The tail-gear, by which the mill is made to 
face the wind, is detailed in fig. 37, where the 
upper view is a side elevation and the lower a 
plan. The tail, formed of thin galvanised sheet- 
iron, is riveted to a piece of very light galvan- 

A SMALL AMERICAN TYPE WINDMILL 35 

ised angle of the section shown. This is not the 
usual rolled angle, but bent sheet, much lighter 
and more suitable for this work. It can be ob- 
tained from tank-makers or workers in galvan- 
ised sheet-iron. The tail is pivoted where shown 
by a bolt which allows sufficient movement and 
is locked in position by the screw shown, a 
tapped hole being provided in the casting (fig. 
33). To get the full effect of wind, the tail must 
lie square with the wheel, or in line with axle. 
Should the wind be too high, its effect on the 
wheel can be diminished by letting the tail turn 
to an angle of 45 ^^ or less with the wheel, insert- 
ing the screw in one of the radial holes in quad- 
rant, according to the strength of the breeze. 
The last hole (at right angles to tail) is the 
" off " position, as when the screw is in that 
place the tail will He parallel with wheel and the 
effect of wind on same will be nil. The wire stay 
shown in the drawings supporting back end of 
tail, may be found unnecessary, but is easily 
fixed. 

It will be very desirable to fit a brake to the 
mill. This need be only a very simple affair — a 
wooden pulley fitted at any convenient position 
on the driven shaft, with a rod or lever to press 
on rim either by weights or spring when desired. 
This may often be useful when it is required to 
stop the mill or to alter the setting of tail, or 
even in the workshop to regulate speed when 
experimenting. 

36 WINDMILLS AND WIND MOTORS 

All parts of the mill subject to the weather 
should either be galvanised or very well painted 
if of iron, and a cap of galvanised sheet fitted 
over the bevel-wheels and casting will not only 
avoid unsightly rusting, but will save oil and re- 
duce friction. 

CHAPTER IV 
A Small Working Windmill 

The windmill next to claim attention is one 
that should appeal to a large circle of readers. 
It has purposely been designed in a very simple 
form, yet of a size sufficient to develop reason- 
able power, namely, %o horse-power in a moder- 
ately stiff breeze of say i6 miles an hour. Such 
a mill will do real work, such as pumping water, 
running a small grindstone, or even driving a 
30-watt dynamo. The total diameter of the 
wheel is 6 feet. 

In order to simplify the machine as far as 
possible, the mill has been designed with fixed 
head, so that the wind must be in one of two 
opposite directions to give a maximum effect. 
It should therefore be set up with the front 
wheel facing in the direction of the prevailing 
wind. Where the two principal prevailing winds 
are, say, S.W. and N.W., the best direction for 
the axis of the mill would probably be north and 
south. Local conditions should be studied, and 
detailed records of the prevailing winds of the 
locality can generally be obtained without diffi- 
culty. A fixed mill like this is also suitable for 
a town dweller, where long rows of houses con- 

37 

38 WINDMILLS AND WIND MOTORS 

fine the wind to definite directions up and down 
the line of " back gardens." 

The vanes (see figs. 38 and 44) can be either 
fixed or allowed to revolve partially upon the 
arms. If fixed, the mill will run in opposite direc- 
tions with opposite winds, and while this need 
not matter for such operations as pumping, it 
would not be satisfactory in other work. A 
simple device has therefore been adopted, so 
that when the wind blows from what may be 
called the back of the mill the sails will auto- 
matically reverse and so cause the direction of 
rotation to be always one way. The maker who 
prefers to have the sails fixed may ignore this 
arrangement and screw the vanes firmly to the 
arms, which need only to be tapered oflf, and not 
rounded in section. The alternative arms re- 
quired in this case are sketched in fig. 46 (two 
views), and of course require less work on their 
construction. 

The mill, as shown in figs. 38 to 47, has six 
whips or arms mounted upon a triangular hub 
to which they are all bolted. The six whips are 
formed from three hardwood sticks, each mak- 
ing a pair of arms. The sticks will be i^ inches 
square in section, 6 feet long, the central portion 
for a length of 22 inches left square while the 
ends should be turned down taper, from ij 
inches diameter at the root to i inch diameter at 
the tips. Good, sound, straight wood should be 
selected. 

A SMALL WORKING WINDMILL 39 

The hub, shown in detail in fig. 39, should be 
very carefully made, to an equilateral triangle to 
the sizes given, of a piece of very sound hard- 
wood of some non-splitting timber. Beech would 
be suitable. The hole for axle must be truly 
bored and fit well so that the sails will all run 
in true plane and square to the axle. The three 
sticks must be bolted to hub, each with two 
f-inch galvanised bolts, with good-sized washers, 
every care being taken to fix each stick at right 
angles to shaft. For further security, another 
J-inch or f-inch bolt will join each pair of sticks 
at their crossing, it being noticed that in one 
case (see fig. 43) a piece of packing of same 
thickness as the sticks will be required. The 
bolt in this case must also be so much longer. 

The axle, or windshaft, as it was called in older 
days, will consist in this case of a short length 
of stout mild steel tubing. The size is not im- 
portant — it is shown i inch diameter outside, 
and should not be less. This is not so much for 
strength as for better attachment to the hub 
with its far-spreading sails. A piece of f-inch 
gas tubing will make a satisfactory axle if centred 
in lathe and a light skimming taken oflf to obtain 
roundness and to make good, clean journals. 

The hardwood hub should be fixed to axle by 
a couple of J-inch split pins going right through, 
as seen in fig. 39. These can easily be got in 
parallel with two of the sticks, and should fit 
well so as to allow no backlash. 

4^ WINDMILLS AND WIND MOTORS 

The bearings should certainly be of brass, and 
the most simple form they can very well take is 
that shown in fig. 47. This provides, of course, 
no adjustment — a refinement that can be adopted 
with advantage if desired, but which hardly 
needs illustration. These bearings are carried 
in hardwood " pedestals," and secured by hard- 
wood caps bolted down over them. A recess is 
made in cap and blocks are provided on base to 
prevent side movement of brasses. If possible, 
oil cups or other similar lubricators should be 
fitted, but they may be dispensed with if the oil 
can is kept going. A cover of thin sheet-iron, 
galvanised, may be fitted with advantage to the 
working parts. The details of forward bearing 
are sufficiently indicated in the three views, fig. 
47 ; the back end bearing being exactly the same. 
Every c^re should be taken to make all tight 
and avoid any rocking. 

The power of the mill may best be transmitted 
by means of a pair of bevel-wheels, as shown in 
fig. 41. This is the usual method, and of course 
various ratios of speed can be got according to 
the wheels used. As here shown, the wheels 
have a speed ratio of two to one; and a light, 
true-running shaft, say f inch or even ^ inch 
diameter, carries the lower wheel. If this shaft 
must be of any great length, or if much of it 
must be unsupported, a greater diameter is de- 
sirable; here again tubing can be substituted for 
solid rod. For pumping purposes a crank may 

1 

i 

f^ \ 

■ p«iirin^ 

■> '""'"'™ ^ 

i 

\\a o |! 

: O O 1 / 

■,' (^''" """" *'^-"-i-. 

• 

1' ^<.^.woaRin-^ 

i 

1 ^ 

\ h 

i 1 

I 

1 ' -'. 

/ ^ 

'1 

5 

^1 

/ 

M 

S 

;: / Fig 15 III 

> 

i 

y °i, 

•°^L 

- 

\^_^ 

y ^sfx 

lVi"DIA", sl 

' Fig. 44 33^^ 

iJi"Dui«. >.'; 

' :>--rv^'^\ \ 1 

K 

%x^ v3 \k 

w 

1 

ig-46 

Fig. 44 Sail Mounted on Whip, with Stops for 

AHomatic 

Reversing, Fig. 45 End View of one Sail and 

H.nge. 

Fig. 46 Two Views of Arm for Fined Sails. 

44 WINDMILLS AND WIND MOTORS 

be arranged either as an overhung crank on tail 
end of shaft, by an eccentric as described in the 
last chapter, or by cranking the shaft itself, the 
throw being made suitable for the pump to be 
used. A light wooden connecting-rod should be 
used if this plan is adopted. 

The method of carr>'ing the vanes and also 
the device for automatically s\i'inging them to 
suit the wind are shown in figs. 40, 44, and 45. 
The vanes are each formed of one (or, if neces- 
sary, of two) f-inch boards, the edges being 
tapered off as shown in fig. 45. Any timber not 
liable to warp in sun and weather will be suit- 
able, one of the best being Califomian redwood, 
usuallv obtainable in wide sizes. 

The supports or hinges, clearly seen in fig. 44, 
are of }-inch X l-inch gal\*anised hoop-iron 
neatly bent to fit round the arms at the places 
assigned to them. They are attached to the 
vanes by J-inch flat-headed rivets or bolts, gal- 
vanised by preference, with large washers next 
the wood, as shown. A good screw projecting 
from the arm just beyond each bearing prevents 
the vane from slipping ofiF. It should be seen 
that each vane s^vin^rs easilv but without shake. 

Owing to the unbalanced shape of the sails, 
thev will swins: accordins: to the direction of 
the wind, and means are provided to allow them 
to take up a position either way at the best angle 
for general work. This is specially shown in fig. 
40> in which the black lines show how the sails 

Fig.l? -Three Views of Front End BesHng for 6.footWin( 

46 WINDMILLS AND WIND MOTORS 

would set with the wind in the direction given, 
and the direction of rotation for same. The 
dotted lines indicate the condition when the wind 
blows from the opposite quarter. The device 
consists of pairs of short cross-bars screwed to 
backs of arms and bolted, with packing between, 
at their crossing. As the angle each way is im- 
portant, care must be taken, by cutting away the 
cross-bars or providing packing, if either is 
necessary, to secure an angle of about 25°. A 
template cut to the correct angle should be used 
to adjust the vanes in each case. 

The timber framing on which the mill is 
erected needs no description beyond that af- 
forded by the sketches, but it should be remem- 
bered that stiffness is essential not only for 
safety but also to avoid strain on the vertical 
shaft and loss of power. Cross-bars can be 
bolted in at intervals if this shaft is long, and 
bearings fitted upon them. 

A final word is necessary as to painting. For 
such an " outside job " as a windmill careful 
painting is essential, and in particular each piece 
of finished timber in the mill itself must be very 
carefully painted over before being built up. 
Three coats of the best paint will not be too 
much, and the last coat may be advantageously 
mixed with some thoroughly good " outside " 
varnish. The next season after erection, another 
two coats of paint should be applied, but prob- 
ably longer intervals may then elapse between 

A SMALL WORKING WINDMILL 47 

the applications. Attention should always be 
paid to regular oiling, and it will be wise to 
avoid working the mill unnecessarily by fitting 
a brake or locking mechanism in some convenient 
position indoors. Indeed, a brake may be very 
desirable as a means of preventing accident either 
to work or person if the windmill is used for 
driving a lathe or other machine. 

CHAPTER V 
A Practical Working Windmill 

To complete the series of small windmills suit- 
able for amateur workmanship, a really practical 
machine, capable of "power" production on a 
moderate scale, remains to be described. It is 
thought that a mill of lo-feet diameter, while 
probably taxing to the fullest the constructive 
ability of any average reader, might well be at- 
tempted by a serious worker with happy results. 
In this instance, while preserving the general 
principle of simplicity, completeness has been 
aimed at, and castings and forgings are adopted 
throughout without hesitation. This certainly 
involves some pattern-making, which, however, 
should be within the scope of any one able to 
carry out the necessary machining of the cast- 
ings. Some readers may be willing — ^and able — 
to reduce this part of the labour by adopting 
makeshift details, but it should be remembered 
that such a method is hardly more advisable 
than it would be in the case of building any 
other motor — say a steam-engine — for power 
production. 

The rating for a lo-foot windmill would be 
about i H.P., which probably appears small for 

48 

Fig. 4B.-Front Elevation of 10-foot Windi 

50 WINDMILLS AND WIND MOTORS 

the amount of work involved and the material 
employed. It is, however, a conservative esti- 
mate, and is based on the standard i6-mile 
breeze, which holds good for something like 8 
hours per day on two-thirds of the days in the 
-year. Manufacturers probably rate a mill of 
this size much higher, and as long as no wind- 
velocity is stated, they may fairly claim to be 
correct. All practical modern windmills, how- 
ever, are constructed with automatic gear so 
that with any given velocity of wind a maxi- 
mum output is obtained, and any increase in the 
wind is more or less counteracted by the action 
of the automatic gear. It follows therefore that 
if our lo-foot mill is set to produce say ^ H.P., 
it can only do this with a wind of much higher 
velocity than i6 miles per hour, which is also 
much more rare. Nevertheless, it will be quite 
within the maker's power to get as much as this 
and more out of his machine, if he so desires 
and the wind is there. It will be merely a ques- 
tion of altering the controlling weight, but will 
also involve very much heavier stresses on the 
machine. This point must be borne in mind. 

A general elevation is given in fig. 48, to a scale 
of J inch to the foot. The tower is built up of 
four 3 inches X 3 inches vertical members, 12 
feet high, each placed at the corners of a square, 
with 4-inch space between each pair of uprights. 
These uprights are well braced by struts, also 
of 3 X 3 timber, starting below the circle of 

A PRACTICAL WORKING WINDMILL 53 

vanes, one strut on each side, and each bolted 
to two uprights, as shown. The lower ends of 
struts are lodged into two horizontal diagonals, 
which are halved over each other at their cross- 
ing so as to lie level. The lower ends of uprights 
with a little shaping will also fit alongside these 
diagonals and must be securely bolted to them 
with ^-inch bolts. Bolts or straps must also se- 
cure the diagonals to the feet of struts. Four 
J-inch bolts not less than 3 feet long miust be 
carried down at the four ends of the horizontal 
members, into pockets of rough concrete of 2 or 
3 cubic feet each. The holes above the concrete 
must be then very firmly filled in and rammed, 
and if the ground is soft or yielding, a greater 
depth and more concrete must be employed. It 
is perhaps needless to insist on the importance 
of having all this timber, but especially that in 
contact with the ground, thoroughly well tarred, 
or better still, properly creosoted, and all bolts 
should be galvanised. Large thick washers 
under the nuts of the f-inch bolts are required. 
A more detailed side elevation of the head, 
tail, and part of the arms is given in fig. 49, to 
a scale of f inch to the foot. This shows the 
movable head casting A carried on the bearing 
casting B. Both these are detailed still further, 
to a scale of ij inches to the foot in figs. 50 to 
54, and require little explanation. The stem of 
A is of course turned to ride easily in the bored 
hole in B, and is fitted with brass bushes for 

54 WINDMILLS AND WIND MOTORS 

axle and for vertical shaft. The casting B is 
securely bolted to the tops of the 3X3 uprights 
with ^-inch bolts, care being taken to get it 
truly upright and central with the timbers. 
Packing pieces, C, in figs. 49 and 54, are used to 
ensure correct spacing. Note should be taken 
of the sheet of zinc or lead, D, figs. 49 and 50, 
which is first laid on tops of uprights, with suit- 
able hole in middle to allow stem of B to pass, 
and is then dressed down, as shown, to throw 
all water from the timbers. It should hang clear 
of the latter to avoid capillary action. 

The tail, employed to keep the mill up to the 
wind, is also shown in fig. 49 at E. It is car- 
ried by two light angles, ij inches X H inches 
X i inch, F and G, which are bolted respectively 
to the top and bottom of head casting A with 
f-inch bolts. The position of these angles is in- 
dicated (in dotted lines) in figs. 50 and 51 at F. 
A sheet of zinc forms the tail surface and is 
riveted to angles with J-inch rivets about 4J 
inches' pitch. Four stiflfeners of ij inch X i- 
inch hoop-iron run vertically across the surface, 
dividing it into three equal spaces. Both angles 
and stiffening strips should be galvanised. 

The shaping of one of the eight arms for the 
vanes is shown in fig. 55, and the outline of sail 
in fig. 56. The assembling of these parts is in- 
dicated in fig. 49, but it is necessary to turn to 
fig^- 57 to see in greater detail not only the 
method of fixing but also the formidable-looking 

A PRACTICAL WORKING WINDMILL 

55 

array of levers and rods constituting the auto- 
matic gear. Every one of the eight sails has its 
independent set of levers to actuate the central 

»« «/i 

^"x2 

r- 

— 2'3i'- 

■*i^ 

NOT TO SCALE 

Fig. 55. — Shaping of Arm or Whip. 

sliding rod, but while it must be admitted this 
means a rather long list of troublesome details, 
the complication is much more apparent than 
real, and is largely due to the difficulty of ren- 

CN 

ol 

HINGES 

'«// 

B'O 

«A08. 

HINQE 

Fig. 56. — Outline of Sail for lo-foot Windmill. 

dering in a drawing the working of levers that 
do not lie in the same plane. The reader is 
therefore asked to study with some care these 
drawings, which the author for his part believes 
to be presented as simply as possible. All that 
has really to be remembered is that the wind 

56 WINDMILLS AND WIND MOTORS 

impinging on an unbalanced sail attempts to 
turn it on its hinges, as shown in plan in fig. 58. 
Regarding now the short side of sail (the so- 
called "leading sail"), it of course describes an 
arc of rather less than a right angle, until it 
lies flat in the plane of the wind's direction. The 
chord of this arc, or rather of that described by 
a projecting pin J (a piece of %6-inch rod bent 
as shown), forms the path of the lower arm of 
lever K, fully drawn in fig. 64, the other arm of 
which, being at right angles, must move verti- 
cally up and down as compared with the sail 
movement. This actuates the f-inch rod L (de- 
tailed in figs. 59 and 60), which in its turn works 
lever M. As before indicated, the planes of 
movement of the levers K and M are not coinci- 
dent, but while this makes their representation 
on paper less easy, it in no way affects the ob- 
ject, which is to produce on the sliding rod N 
an in-and-out movement according to the amount 
of the wind's pressure. The lever K is supported 
at the special angle required (seen in plan in fig. 
58) by a bracket O (fig. 64) bolted to arm. The 
top arm of lever is made with a return end in 
order to give a long bearing, and bottom end 
slotted to allow the necessary play for the pin 
J, due to the path of the latter being an arc. 

Returning now to the sliding rod N, it will be 
seen that the motion of the eight levers M is 
transmitted to it through the special turned nut 
P, figs. 62 and 63. The various possible posi- 

A PRACTICAL WORKING WINDMILL 57 

tions of the forked end of lever require that the 
section of this " nut " be turned to the curves 
shown. A lock-nut on the outer side enables P 
to be screwed up to the most suitable position, 
and there secured in place by the lock-nut. 

Examination will show that the tendency of 
any wind action on the sail is to force rod L 
nearer the centre of mill, and so to drive rod N 
to the right as looked at in figs. 49 and 57. This 
has to be met at the other end of N by the coun- 
teraction of a weight, R, carried by a cranked 
lever, S, indicated in a diagram in fig. 49, and 
more fully in figs. 67 and 69. The lever, the 
short end of which is doubled or looped (see left- 
hand view in fig. (>y^ in order to pass on both 
sides of the loose pin bearing T, is hung from 
the upper tail-angle F by a ^-inch screw, a se- 
curer bearing being obtained for this by tapping 
into the block U, which is riveted to angle, see 
section, fig. 68. The arrangement of end of rod 
N and pin block T is more clearly shown in fig. 
69. Fig. 65 gives an end view of pin bearing, T. 

The weight, R, should be cast double, one 
piece having a slot or recess cast on one side as 
shown in fig. 66. It is difficult to fix on the exact 
weight that may be required, as this depends 
not only on the views of the maker as to the 
power which he desires the mill to exert at its 
maximum, but also on the friction of the numer- 
ous joints in levers. It is, however, recom- 
mended that a trial be made with a weight of 

6o WINDMILLS AND WIND MOTORS 

about ID lbs., corresponding with the full lines 
in the drawings given. If the mill sails are 
found to open too easily with this weight — which 
is, however, doubtful — it can be shifted further 
along the lever arm, or if even this is found 
insufficient, another disc can be added as shown 
dotted on the left in fig. 66. A light galvanisci 
chain, running over a pulley in top angle 'oC 
tail and hanging with a loop to within 6 fe«l of 
the ground level, is used to lift weight wheik tlie 
owner desires to stop the mill, this actioa, of 
course, opening all the sails so as to present ooij 
their edges to the wind. The other end of chain 
is looped back to a point near outer end of tail 
to avoid entanglement with uprights or running 
shaft. A hook attached to chain in proper posi- 
tion, W, can be hitched under lower angle of 
tail by taking chain sideways a little and so hang 
the weight up for any length of time. 

The automatic action and its details should 
now be fairly clear, and the remaining parts of 
the mill are simple. The large central casting, 
X, appears in several figures, notably in section 
in fig. 57 and in front elevation in fig. 70. It is 
undoubtedly the most serious undertaking in the 
whole construction and must probably be " put 
out" into the hands of professionals. It should 
not, however, be a costly item, and if made as 
indicated will go far to making the mill a prac- 
tical job. This casting carries the eight arms 
and makes secure connection to the axle. It is 

62 WINDMILLS AND WIND MOTORS 

backed up in its support of the arms by the 
smaller annular casting Y, fig. 71, which is bored 
to fit well over turned part of X. Three very 
well-fitted ^-inch screws at 120** secure the boss 
to shaft, a good tight fit between shaft and casting 
being essential. These screws must not project 
inside the shaft far enough to touch the sliding 
rodN. 

The casting X carries also the eight little 
brackets Z for the levers M. These brackets are 
of cast iron and may be " American " in char- 
acter in so far that the pins form part of the 
casting, a file probably being a good enough tool 
to finish them. 

A little further stiffening of the sail-arms is 
obtained by the use of the tension-rods TR, de- 
tailed in fig. J2, These ar^ only J-inch galvan- 
ised rods one end turned over for an inch at 
right angles and the other screwed and lock- 
nutted. The tension put on these must be even 
and not too great; but they, as well as other 
screws and bolts in the machine, will probably 
require tightening up once or twice when the 
weather has had its effect on the timber. 

A word is required in reference to this latter 
item. The arms should certainly be wrought 
from good sound seasoned ash. The sails can 
hardly be formed of better timber than Califor- 
nian redwood (Sequoia semper znrens), which 
can be obtained in wide boards. They will be 
4 inch thick with the edges chamfered oflf both 

A PRACTICAL WORKING WINDMILL 63 

Sides. Three battens, 2 inches X li of sound 
hardwood (ash, bluegum, etc.) must be well 
screwed across, and the hinges, three in number, 
will come opposite these, on the other side of 
sail. These hinges should be of the strongest 
make of T shape, galvanised. They are shown 
in the plan, fig. 58. 

So far the axle has hardly been mentioned. 
It is, however, a very simple matter, being 
nothing but a piece of 2-inch (outside diameter) 
steel steam-pipe, preferably solid drawn, and 
quite J inch thick. It should be true to begin 
with, so that the very lightest skimming in the 
lathe will make it a good journal. It carries the 
usual bevel-wheel, indicated in figs. 49 and 57, 
and gearing with another of the same size on 
the vertical shaft. Both wheels are 4 inches on 
inner diameters, but may be more or less if re- 
quired, the casting A being altered if necessary. 
The vertical spindle would be a piece of f-inch 
cold rolled steel shafting, and should have bear- 
ings also at bottom end and half-way down the 
tower, presuming the spindle is carried down to 
the ground as shown in fig. 48. A pair of bevel- 
wheels is also required to transmit power to a 
horizontal shaft. 

One or two points in conclusion deserve re- 
mark. First, that all possible metal parts should 
be either galvanised or of sheet zinc. The cast- 
ings will most probably be only painted. They 
should be "pickled," freed from rust and espe- 

04 WINDMILLS AND WIND MOTORS 

cially from dirt and grease, and painted with 
good red lead paint well rubbed in. It is better 
still to warm the castings to about loo** Fahr. 
when putting the first coat on. Three coats of 
the red lead paint, thinly put on, and a finishing 
coat of grey or black paint are required to make 
a good job. The woodwork, it has already been 
remarked, should be tarred or creosoted. This 
does not apply to the arms and vanes, all of 
which require the usual painting in most thor- 
ough fashion. The most suitable paint is pure 
white lead with a dash of ochre. 

Steps, formed from any suitable timber, say 
3X2 inches, should be nailed up at least two 
sides of the verticals to enable the owner to 
reach the head of mill for oiling, etc. 

A mill of this power, especially if used to 
drive a lathe or other workshop tools, should 
have a simple cut-out device — such as a sliding 
coupling actuated by a handy cord or chain, so 
as to throw the mill out of gear in case of an 
accident. A brake is not so necessary, as the 
automatic gear is designed as much as possible 
to keep the machine at uniform speed. Under 
normal output this speed should be from 80 to 
100 revs, per minute, varying slightly according 
to the setting of the sails. These, in their flat- 
test position — that is, with a light wind — should 
lie at an angle of about 20° to the plane of 
revolution of the wheel. 

CHAPTER VI 

Production of Electricity by Wind-Pov/er 

To most readers the possibility of applying 
the power from a windmill to the production 
of electrical energy will be an interesting fea- 
ture, and it is fortunate that recent experimental 
work has proved that not only is this feasible 
but even simple, inexpensive, and reliable. By 
" reliability " it is not, of course, meant that the 
fickleness of the wind is completely overcome, 
but only ^that Jhe 3£garatuSj^ whigtu iacludes 
some automatic gear, can be relied upon not to"^ 
go wrong, rt is certainly possible — within rea- 
sonable limits — by employing a large enough 
mill and accumulator, to tide over even exten- 
sive calms, but probably any amateur engineer 
who decides to adopt the method to be de- 
scribed will be willing to accept a few inevitable 
" off-days " in each year, when no current will 
be available, balancing this trouble against the 
very definite advantage of the inexpensiveness 
of the powen ' 

Many experiments have been made at differ- 
ent times and in different places to utilise wind- 
power in the way now under discussion. There 
is, however, no need to deal with more than one, 

65 

65 WINDMILLS AND WIND MOTORS 

which, having proved satisfactory' in practice, is 
in use in a fairly large number of instances in 
North Germany and in Denmark, not only for 
the supply of isolated farm-houses but even for 
village lighting and power production. In prac- 
tically all these cases an oil-engine is jised as a 
standby, yet it*is found that the number of days 
in the year on which this engine is called into 
use are so few that the reader who proposes to 
light a house or provide himself with power on 
a small scale may reasonably consider the extra 
expense unnecessary in his case. 

The following suggestions are based entirely 
on the excellent work recently done and pub- 
lished by Prof. P. la Cour in Denmark on behalf 
of that Government, which has in that partic- 
ular placed itself ahead of other countries — 
considerably to the advantage of many of its 
villages and isolated dwellings. The reader 
must be prepared to experiment a little — not 
indeed in principles but in details of apparatus 
to suit his own case — ^but may rest absolutely 
assured that the method is quite practical and 
satisfactory. 

There are two main difficulties in applying a 
power so variable and intermittent as wind to 
the production and supply of electricity. There 
must, first, be a means of automatically switch- 
ing on the dynamo to a set of accumulat6?s 
whenever the former is in a position to deliver 
current, the same apparatus cutting it out when 

PRODUCTION OF ELECTRICITY BY WIND-POWER 6y 

the power falls away, gecondly, means must be 
adopted whereby an increase of wind-power be- 
yond the normal amount required to just work 
the dynamo shall not affect the output by in- 
ctieasing either voltage or current. Both these 
ends have been attained by La Cour with the 
simplest apparatus imaginable. 

A consideration of the second question raised 
will show why it is necessary to decide on a 
definite wind-velocity as being that at which 
any given windmill shall supply its " normal " 
output. By rating it low, say a wind of 9 miles 
per hour, it is possible to keep a dynamo work- 
ing nearly every day in the year and for twelve 
hours out of the twenty-four. But the power of 
the wind at 9 miles an hour is only a quarter 
of that at 15 miles an hour, and although the 
latter only blows about half the total number 
of days in a year, and then for only about nine 
or ten hours a day, its total output is greater 
than the other. Another point to be considered 
IS that a very small dynamo is much less effi- 
cient, so that a double loss is experienced if too 
much constancy of work is aimed at. Of course, 
in a large installation these points have less 
emphasis, and it becomes desirable to run the 
plant at a lower wind-rating (in other words, 
use a comparatively large mill), the only limit- 
ing factor being the initial cost of the plant. 

In a wind-driven generating plant the follow- 
ing points should be noted. The windmill itself 

68 WINDMILLS AND WIND MOTORS 

should be self-regulating (as, for example, that 
described in Chap. V.), and fitted with tail so as 
to turn to face all possible winds. The dynamo 
should be shunt-wound, so that an increase in 
the external resistance tends to raise the ter- 
minal voltage. If necessary, this tendency may 
be increased by having one or two resistance 
coils in series with the shunt-winding, these 
coils being automatically cut out as the external 
resistance rises and current falls. A low-speed 
machine is certainly preferable, the speed of a 
windmill being rather low itself. The accumu- 
lator is a vital point: it should have a large 
capacity, as on this depends its ability to main- 
tain a supply over a longer period of calm; yet, 
as it is undesirable for anv accumulator to re- 
main long at a low state of charging, care must 
be taken to avoid draining it — especially if a 
spell of calm weather seems likely. 

The whole of the electrical apparatus is 
shown diagrammatically in fig. 73, the only part 
needing much description being the automatic 
switch, further illustrated in three views in fig. 
74. This consists of two electro-magnets, EM, 
each like an ordinary bell-iiiaq:nct, and wound 
with fine wire, but w^ith an extra winding of a 
few turns of thick wire, exactly like a compound- 
wound dynamo field magnet. A horse-shoe per- 
manent magnet, PM, is suspended so that its 
poles lie opposite and near to the poles of the 
electro-magnets, and swings by means of the 

70 WINDMILLS AND WIND MOTORS 

pivot screws which work in a brass (or non- 
magnetic) block, B. This block also carries the 
copper rod CR, each end of which turns down- 
ward into the wooden cups i and 2, containing 
mercury, matters being so arranged, however, 
that the end i is always in the mercury which- 
ever way PM is swung, while 2 only touches 
the mercury when that end of CR is drawn 
downwards. 

The switchboards present no special features. 
By following out the connections it will be seen 
that any agreed number of cells can be switched 
on to the dynamo, while any independent num- 
ber can be caused to supply the lamps. This 
latter arrangement is desirable to allow for drop 
of voltage during discharge, also to provide for 
losses in mains and for an extra cell or two in 
case of accident to others. 

The action of the automatic switch is as fol- 
lows: Assuming the dynamo to be still, or 
running at too low a speed to furnish current, 
it will be seen that the battery is energising the 
electro-magnets EM through the fine wire-coils, 
the current passing also through the armature 
of the dynamo. The winding of EM is such 
that the current in this direction attracts the 
poles of PM to the right and so raises the end, 
2, of CR out of the mercury. Only a very 
small current is required, or allowed, to be thus 
wasted. Supposing now the wind to increase 
sufficiently to raise the speed of dynamo so 

72 WIXDMILLS AXO ^IXO MOTORS 

much as to be able to supply cnrrent. the first 
effect will be to reduce the current in EM to 
nil and then to reverse it, altering the polarity 
of the electro-magnets and throwing the lower 
end of magnet PM over to the right. This, by 
dipping the end 2 of CR into the mercury, 
makes connection between the d>Tiamo and ac- 
cumulator, the charging of which at once begins. 
The eflFect of the thick-wire coils on EM is to 
hold the magnet switch more securely during 
charging. The opposite action — that of throw- 
ing out the d>Tiamo when the speed fails — ^is 
obvious on inspection. 

The apparatus required to maintain the dy- 
namo at the right speed when that of the mill 
itself ranges too high is a system of belts and 
pulleys, shown in fig. 75. Here A is an ordinary 
pulley with the usual cur\'ed face; B, a rather 
wide, flat-surfaced pulley; C and D, again, ordi- 
nary pulleys; C and B being fast on one shaft. 
This shaft is carried on the light timber frame 
EF, hinged at E, and canying a weight G at 
the other end. 

It will be seen that this arrangement provides 
for a constant pull on the belt between A and B. 
It may be found that this pull is too great even 
without the weight G, in which case a cord 
(shown dotted) takes its place, and, by means 
of a pulley overhead and another weight, takes 
off some of the load. 

The belt CD has no special feature beyond 

PRODUCTION OF ELECTRICITY BY WIND-POWER 73 

being thin, supple, and even. That between A and 
B, however, must be specially smooth on its run- 
ning surface, and must in addition be thoroughly 
well oiled. On this depends the peculiar result to 
be obtained. It is found that when the weight G 
has been properly adjusted, and other details of 
current supply, etc., decided upon by experiment, no 
matter how much faster than normal A is compelled 
to run by the wind, the speed of B remains con- 
stant or with just sufficient variation to meet 
the slightly varying conditions required by the 
dynamo, the belt slipping on B at the higher 
speeds. The principle, of course, is not new; 
but its application in the present instance, to- 
gether with the automatic switch, is an excellent 
example of mechanical adaptation. 

The details of the whole of the apparatus 
must necessarily be worked out by individual 
requirements: the following suggestions, how- 
ever, are added as an example, the instance 
chosen being the lo-foot windmill described in 
the last chapter. This windmill, working in a 
15- or 16-mile breeze, should have an output of 
about i H.P. Allowing for losses in dynamo, 
gearing, and belts, it may be assumed that a 
dynamo of lOO-watts output would be the right 
machine for the available power. The voltage 
chosen might well be 25, this being its lowest 
rate at normal speed, which may be assumed at 
1500 revs, per minute. 

Under these circumstances, and assuming 

■»i« 

74 

WINDMILLS AND WIND MOTORS 

pulley A (fig. 7s) to run at 200 revs, per min- 
ute (by whatever gearing used), A might be 12 
inches diameter X 2 inches width ; B, 6 inches X 

Fig. 75. — Driving Belt Arrangement for Wind Electrical 

Plant. 

• 

3 ; C, 8 inches X 2 ; and D, the dynamo pulley, 
2 inches X 2 inches. This gives a rather higher 
ratio than is required — an error on the right 
side. The belt between A and B should be i% 
inches X %o inch, the pulleys being about 6 feet 
centres, and belt CD i inch wide X Vh i^^ch thick, 
also with about 6 feet drive. 

PRODUCTION OF ELECTRICITY BY WIND-POWER 75 

There would be twelve accumulator cells, 
each of from 150 to 200 ampere-hour capacity, 
which would be easily capable of dealing with 
the full current for twenty-four hours' continu- 
ous charging. The capacity mentioned is the 
maximum suitable for the given plant, but the 
minimum may be anything down to twelve 
pocket-batteries, if so desired. Within the 
limits given, the greater the capacity the more 
the independence of conditions of wind. 

With regard to the automatic switch, a little 
experimenting and adjusting will be needed to 
ensure its correct working. The electro-magnets 
may be two ordinary bell-magnets, wound with 
No. 36 wire, the bobbins being about ij inches 
long and i inch diameter outside. A resistance 
may be needed in series with this winding, or 
the effect may be tried of connecting up only 
six of the cells to these coils, the six on the left- 
hand side in fig. 73 being, of course, selected. 
All four bobbins will be joined in series. Over 
the fine wire on each bobbin will be wound from 
six to twelve turns (to be determined by experi- 
ment) of No. 16 or 14 gauge cotton-covered 
wire, the winding being in same direction as 
the fine wire in each case, so that the current 
is a reinforcing one when being supplied from 
the dynamo. The balance of the permanent 
magnet can be adjusted by moving the copper 
rod CR either to right or left. 

The output from such an installation may of 

76 WINDMILLS AND WIND MOTORS 

course be anything up to the safe discharge rate 
of the battery employed. Assuming the normal 
conditions of charging to be, say, lOO watts for 
ten hours (equal to looo watt-hours), and that 
this charge is to be used in two evenings, there 
would be available 500 watt-hours per evening, 
less the losses in transforming, or, say, 80 watts 
for five hours. Fortunately at the time of year 
— winter — when longer lighting is necessary 
more wind-power is also available. Of course, 
only metallic-filament lamps should be used, 
when it will be seen that with proper propor- 
tioning of the plant quite a respectable output 
in light is to be obtained. The lamps for the 
above installation would be 16 volt. 

If the loan of an anemometer cannot be ob- 
tained, a simple form of wind-pressure meter 
should be used to determine the right weight 
(R, fig. 49) required to just hold the windmill 
sails at the velocity decided upon. Such an 
apparatus is sketched in fig. 76. It is merely a 
sheet of stout cardboard, 2 feet X i foot, hung 
on one of the narrow edges by a hinge of linen, 
the middle of the lower edge being connected 
as shown to a small spring letter balance capa- 
ble of reading up to at least one pound. A table 
of wind-pressures and velocities is given below, 
by which any pressure registered can be con- 
verted into velocity. The pressure-board must, 
of course, squarely face the wind blowing at the 
time of the experiment. Note that the spring 

PRODUCTION OF ELECTRiaTY BY WIND-POWER yj 

balance is just at zero when no wind is im- 
pressed on the board, or a false reading may 
be obtained. If made to the given sizes, the 

<r--t2-- 

O 
CI 

-LINEN HINQE 

DIRECTION 

■< 

OF WIND 

SPRING BALANCE 

Fig. 'jd. — A Simple Wind-pressure Gauge. 

readings will be direct measurements of the 
pressure per square foot. 

The brake horse-power of a windmill can be 
taken in exactly the same way as that of a 
steam-engine, the only difficulty being the usual 
unsteadiness of the wind. At a time when the 
wind is fairly steady and about right in velocity, 

78 

WINDMILLS AND WIND MOTORS 

such a test should be made, one observer watch- 
ing the pressure-meter and noting the pressure, 
say, every half-minute, another reading the 
spring balance of the brake at similar intervals, 
the test lasting for a quarter of an hour. Aver- 
age results may then be obtained, which may 
be extremely useful for determining the size of 
dynamo required, it being remembered that the 
power of the wind varies (theoretically) directly 
as the cube of its velocity. In practice the vari- 
ation rate lies between this and the square of the 
velocity. 

Table of Wind Pressure and Velocities. 

Miles per 

Feet per 

Feet per 

Force in 

lbs. per 

sq. foot. 

hour. 

minute. 

second. 

1 

88 

1.47 

.005 

2 

176 

2.93 

.020\ 
.044/ 

3 

264 

4.4 

4 

352 

5.87 

.079\ 
.123/ 

5 

440 

7.33 

10 

880 

14.67 

.4921 
1.107/ 

15 

1320 

2? 

20 

1760 

29.3 

1.9681 
3.075/ 

25 

2200 

36.6 

30 

2640 

44 

4.4281 
6.027/ 

35 

3080 

51.3 

40 

3520 

58.6 

7.8721 
9.963/ 

45 

3960 

66 

50 

4400 

73.3 

12.300 

oO 

5280 

88 

17.712\ 
24.108/ 

70 

6160 

102.7 

80 

7040 

117.3 

31.4881 
49.200/ 

100 

8800 

146.6 

Description. 

Hardly perceptible. 
Just perceptible. 

Gentle breeze. 

Pleasant breeze. 

Brisk gale. 

High wind. 

Very high wind. 
Storm. 
Great storm. 

Hurricane. 

5It 

■^ 

LEARN TO DO THINGS 

Model Library Series 

OF COPYRIGHTED BOOKS 

1 . The Study of Electricity for Beginners. 

2. Dry Batteries, How to Make them. 

3. Electrical Circuits and Diagrams, Part 1 . 

4. Electric Bells, Annunciators and Alarms. 

5. Modern Primary Batteries. 

6. Experimenting w^ith Induction Coils. 

7. Electric Gas Igniting Apparatus. 

8. Small Accumulators, How to Make and Use 

9. Model Steam Engine Design. 

10. Practical Electrics. 

1 1 . Inventions, How to Protect and Sell Them. 

12. Woodwork Joints, How to Make and Use. 

1 3. The Fireman's Guide to the Care of Boilers. 

14. The Slide Valve Simply Explained. 

15. The Magneto Telephone. 

16. The Corliss Engine and Its Management. 

17. Making Wireless Outfits. 

18. Wireless Telephone Construction. 

19. The Wimshurst Machine, How to Make It. 

20. Simple Experiments in Static Electricity. 

21. Small Electrical Measuring Instruments. 

22. Electrical Circuits and Diagrams, Part 2. 

23. Induction Coils, How to Make Them. 

24. Model Vaudeville Theatres. 

25. Alternating Currents, Simply Explained. 

26. How to Build a Bi-plane Glider. 

27. A B C of the Steam Engine. 

28. Simple Soldering, Hard and Soft. 

29. Telegraphy for Beginners. 

30 . Low V oitage Lighting with Storage Batteries. 

33. House Wiring for Electric Light. 

34. Magnets and Magnetism.
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

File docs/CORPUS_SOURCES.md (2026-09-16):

# Corpus Source Log

| Filename | Origin URL | Edition/Date | License | Added |
|---|---|---|---|---|
| corpus/pd/fm21-76-survival-manual.txt | https://archive.org/download/Fm21-76SurvivalManual/FM21-76_SurvivalManual_djvu.txt | FM 21-76, June 1992 reprint (233 pp, OCR text) | PD (U.S. Army work) | 2026-09-15 |
| corpus/pd/first-book-of-farming-1905.txt | https://www.gutenberg.org/cache/epub/16900/pg16900.txt | Goodrich, *The First Book of Farming*, 1905 (PG #16900) | PD (pre-1929) | 2026-09-15 |
| corpus/pd/practical-blacksmithing-1889.txt | https://archive.org/download/gri_33125007986850/gri_33125007986850_djvu.txt | Richardson (ed.), *Practical Blacksmithing*, 1889 (OCR text) | PD (pre-1929) | 2026-09-15 |
| corpus/free/where-there-is-no-doctor.pdf | hesperian.org (owner-downloaded, uploaded to project) | Werner, *Where There Is No Doctor* | FREE (Hesperian open license — device use OK, NOT committed to public repo) | 2026-09-15 |
| corpus/free/where-there-is-no-dentist.pdf | hesperian.org (owner-downloaded, uploaded to project) | Dickson, *Where There Is No Dentist* | FREE (Hesperian open license — device use OK, NOT committed to public repo) | 2026-09-15 |
| corpus/pd/hardening-tempering-steel-1903.txt | https://archive.org/download/hardeningtemper00woodgoog/hardeningtemper00woodgoog_djvu.txt | Woodworth, *Hardening, Tempering, Annealing and Forging of Steel*, 1903 (OCR text) | PD (pre-1929) | 2026-09-16 |
| corpus/pd/knots-splices-ropework-1912.txt | https://www.gutenberg.org/cache/epub/13510/pg13510.txt | Verrill, *Knots, Splices and Rope Work*, 1912 (PG #13510) | PD (pre-1929) | 2026-09-16 |
| corpus/pd/lectures-in-navigation-1917.txt | https://www.gutenberg.org/cache/epub/27642/pg27642.txt | Draper, *Lectures in Navigation* (US Navy course), 1917 (PG #27642) | PD (pre-1929) | 2026-09-16 |
| corpus/pd/elementary-chemistry-1906.txt | https://www.gutenberg.org/cache/epub/20848/pg20848.txt | McPherson & Henderson, *An Elementary Study of Chemistry*, 1906 (PG #20848) | PD (pre-1929) | 2026-09-16 |
| corpus/pd/first-aid-fm21-11-1943.txt | https://archive.org/download/Fm21-11/Fm21-11_djvu.txt | War Dept., *FM 21-11 First Aid for Soldiers*, 1943 (OCR text) | PD (U.S. gov work) | 2026-09-16 |
| corpus/pd/every-step-in-canning-1920.txt | https://www.gutenberg.org/cache/epub/13775/pg13775.txt | Gray, *Every Step in Canning: The Cold-Pack Method*, 1920 (PG #13775) | PD (pre-1929) | 2026-09-16 |
| corpus/pd/windmills-wind-motors-1910.txt | https://archive.org/download/windmillsandwin00powegoog/windmillsandwin00powegoog_djvu.txt | Powell, *Windmills and Wind Motors*, 1910 (OCR text) | PD (pre-1929) | 2026-09-16 |
| corpus/pd/woodwork-joints-1921.txt | https://www.gutenberg.org/cache/epub/21531/pg21531.txt | Fairham, *Woodwork Joints*, 1921 (PG #21531) | PD (pre-1929) | 2026-09-16 |
| corpus/pd/boy-electrician-1913.txt | https://archive.org/download/TheBoyElectricianMorgan/The-Boy-Electrician-Morgan_djvu.txt | Morgan, *The Boy Electrician*, © 1913 / pub. 1914 (OCR text, 3rd ed.) | PD (pre-1929) | 2026-09-16 |
| corpus/pd/radio-amateurs-handbook-1922.txt | https://www.gutenberg.org/cache/epub/6934/pg6934.txt | Collins, *The Radio Amateur's Hand Book*, 1922 (PG #6934) | PD (pre-1929) | 2026-09-16 |

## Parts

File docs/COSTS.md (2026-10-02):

# Cost analysis — hardware tiers, models, and enclosure printing

Researched 2026-10-02. Prices move monthly (RAM shortage) — re-check before
any order. **(U)** = seen only in search snippets / listings, not confirmed
on the seller's page. **(E)** = my estimate, not researched.

## 1. Why the build is expensive
Raspberry Pi prices were raised three times (Dec 2025, Feb 2026, Apr 2026)
because of memory costs. The Pi 5 8GB is $175 at PiShop (fetched; launch
price was $80) — about half of the whole bill of materials. Alternatives
(Orange Pi 5, Radxa Rock 5C) are either as expensive, sold out, or can't
ship to the US right now. **The cost lever is a smaller-RAM Pi with a
smaller model, not a different brand of board.**

## 2. Which models fit which board (llama.cpp, Q4, CPU)

| Board (price) | Model | Gen tok/s | RAM | Notes |
|---|---|---|---|---|
| Pi 5 8GB ($175) | Qwen2.5-3B (current) | 5.4 measured | 4.4 GB measured* | what we run today |
| Pi 5 | Gemma 4 E2B | 7.0 | 3.2 GiB peak | [pi5-llm-arena](https://github.com/leemailto2008/pi5-llm-arena) |
| Pi 5 | Gemma 3 4B QAT | ~5 | 2.8 GB | [benchmark](https://www.kunalganglani.com/blog/gemma-3-raspberry-pi-5-benchmark) |
| Pi 5 | Gemma 3n E2B | ~6 | 2.5 GB | same |
| Pi 5 | Qwen2.5-1.5B / Qwen2 1.5B | 11–12 | ~1.8 GB | [Geerling](https://www.jeffgeerling.com/blog/2026/raspberry-pi-ai-hat-2/) |
| Pi 5 | Gemma 3 1B QAT | ~11 | ~0.9 GB | benchmark above |
| Pi 4 4GB ($100) | 1B–3B | ~1–3.4 (U) | — | slower **and** barely cheaper than Pi 5 4GB — skip |
| Pi Zero 2 W ($15) | any | — | 512 MB | doesn't fit — not viable |

\* 4.4 GB is the whole process (LLM + embedding model + FAISS index + OS
share). **TODO:** measure the LLM alone on the device — that decides
whether a 4GB board can keep the 3B model.

**Gemma 4** (released 2026-04-02, Apache 2.0): E2B/E4B accept audio
(≤30 s clips). Audio works in llama.cpp only via `llama-mtmd-cli`, with
open bugs (transcription loops/hallucination; llama-server rejects audio).
**Not yet a dependable speech-to-text replacement.**

**Voice interface (optional):** Moonshine STT (Pi 5 latency ~237 ms for
Tiny Streaming vs ~5.9 s Whisper Tiny, vendor figure) + Piper TTS (~5×
faster than real time on Pi 5). Hardware: INMP441 I2S mic ($1.59–4.95 U),
MAX98357A amp ($5.95), small speaker (~$2) ≈ **$10–13**. Realistically
needs a 4GB board alongside the LLM.

**NPU add-ons:** Hailo-10H / AI HAT+ 2 ($130) is *slower* than the Pi 5 CPU
for LLMs (Geerling: 5.9 vs 11.3 tok/s) — not a cost saver.

## 3. Hardware tiers (single-unit retail, per device)

| Part | Tier 1 — current | Tier 2 — Pi 5 4GB | Tier 3 — lean |
|---|---|---|---|
| Board | Pi 5 8GB **$175** | Pi 5 4GB **$110** | Pi 5 2GB **$65–78** |
| Model | Qwen2.5-3B | 3B if RAM allows, else Gemma 4 E2B / 1.5B | Qwen2.5-1.5B / Gemma 3 1B (faster, weaker) |
| Cooling | Active Cooler $10.95 | $10.95 | passive $5.95 (U) — only if thermal test passes |
| microSD | 64GB endurance ~$22 (U) | ~$22 | 32GB ~$10–15 (E) |
| UPS board | X1202 4-cell $51 | $51 | X1200 2-cell $45 (half the runtime) |
| 18650 cells | 4× Samsung 35E $24 (U) | $24 | 2× $12 (U) |
| Display | Waveshare 4.2" e-paper $28.99 | $28.99 | $28.99 |
| Keyboard | CardKB $7.95 | $7.95 | $7.95 |
| Enclosure (PLA) | ~$10 (library) | ~$10 | ~$10 |
| **Core subtotal** | **≈ $330** | **≈ $265** | **≈ $200–215** |
| Plumbing (real copper + brass fittings, ports, LED, switch, wire) | +$40–50 (E) | +$40–50 (E) | printed pipes +$15–20 (E) |

NCR18650B (the model Geekworm recommends) is sold out at
18650batterystore; Samsung 35E / Molicel P28A are the in-stock
equivalents — check they meet the X1202's "unprotected flat-top,
≤18.5 × 65.3 mm" rule.

**Volume (100 units):** no published Pi bulk price (quote-only via
Farnell/RS/DigiKey/Mouser). Published tiers: Waveshare e-paper $27.63 at
50–99, Adafruit ~−20% at 100+. Expect only modest savings at 100 units.

## 4. Printing the enclosure

Measured from the v0.6 STLs: **155 cm³ total ≈ 190 g PLA** (rear shell
101 cm³ / 126 g, bezel 23 cm³ / 28 g, all small parts ~30 cm³). Without
printed pipes (real copper): 146 cm³ ≈ 181 g.

| Option | Cost for one full set | Shipping | Notes |
|---|---|---|---|
| **Arlington Public Library "The Shop"** | PLA $0.05/g → **≈ $10** | local pickup | staff print; one job at a time; confirm bed fits the 177 mm shell ([APL](https://library.arlingtonva.libguides.com/theshop/3DPrinting)) |
| Home Bambu A1 ($299–399) | filament ≈ **$4–5** (PLA ~$20/kg; silk copper ~$17–20/kg) | — | pays for itself after ~6–10 sets; A1 mini's 180 mm bed is too tight for the 177 mm shell |
| Slant 3D (US print farm) | instant per-part quote, no minimum | domestic, no tariff | best for 10–100+ units without owning printers |
| Makelab (Brooklyn) | median for 150–250 mm parts **$71** — set likely ≈ $90–120 (E) | ships US | finished-quality FDM/SLA |
| Craftcloud | compares many vendors | free over $50 | watch import duty from overseas vendors |
| JLC3DP (resin / MJF) | instant quote, from $0.30/part | DHL/UPS at checkout | **+40% US duty prepaid since 2026-03-17**; budget +$25–40 |
| PCBWay | quote, **$25 minimum** + $5–20 setup | DHL/FedEx | — |

**Injection molding** only pays off past ~500–1,000 units: aluminium
tooling ≈ $6k–12k for a 2-part shell; ~$4.20/part at 1,000/yr.

## 5. Recommendations
1. **Don't print the real enclosure yet** — stack height, connector and
   port positions are still unmeasured. First print only the **bezel**
   as a fit test (28 g ≈ $1.40 at the library).
2. Measure the LLM's own RAM on the device; if Qwen2.5-3B + RAG fits
   under ~3.5 GB, **Tier 2 (Pi 5 4GB) saves $65/unit with no quality
   loss.**
3. Tier 3 (≈ $200–215) is viable for a cheaper model line, but the 1.5B
   models are noticeably weaker — re-run the Phase 4 eval battery and
   eval_retrieval before committing to it. Critical mode's verbatim
   sources still protect safety-critical answers.
4. Voice (Gemma 4 audio) — wait; Moonshine + Piper is the dependable
   route today if voice becomes a requirement.

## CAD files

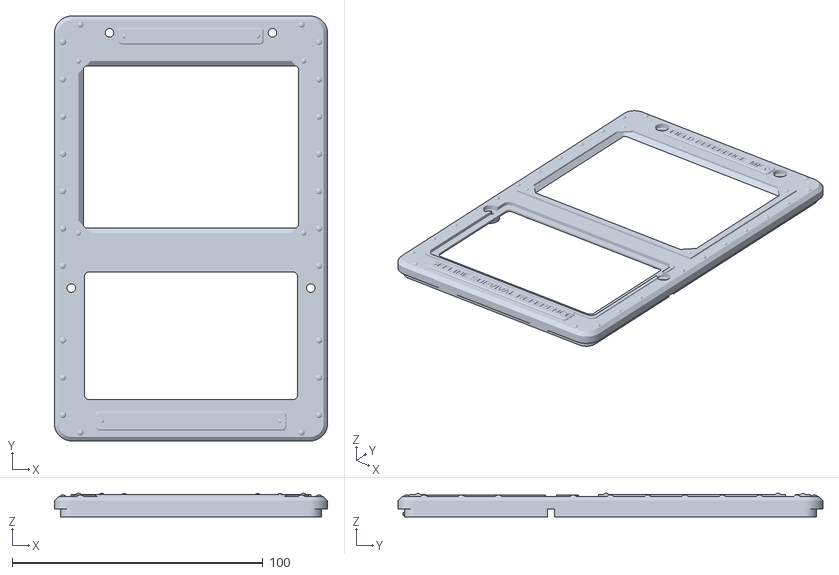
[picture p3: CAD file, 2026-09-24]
enclosure/stl/bezel.stl
109.0 x 169.5 x 9.39

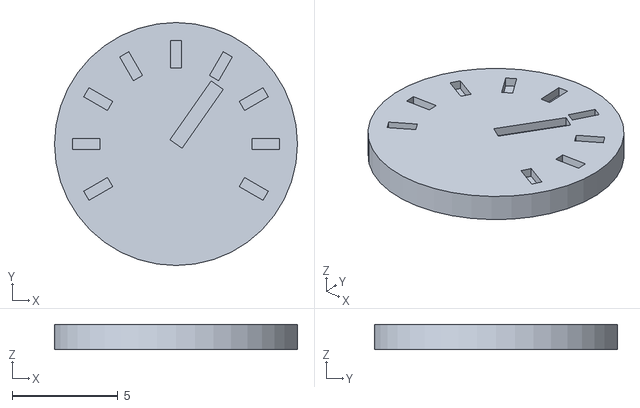
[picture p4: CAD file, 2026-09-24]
enclosure/stl/gauge_face.stl
11.5 x 11.5 x 1.20

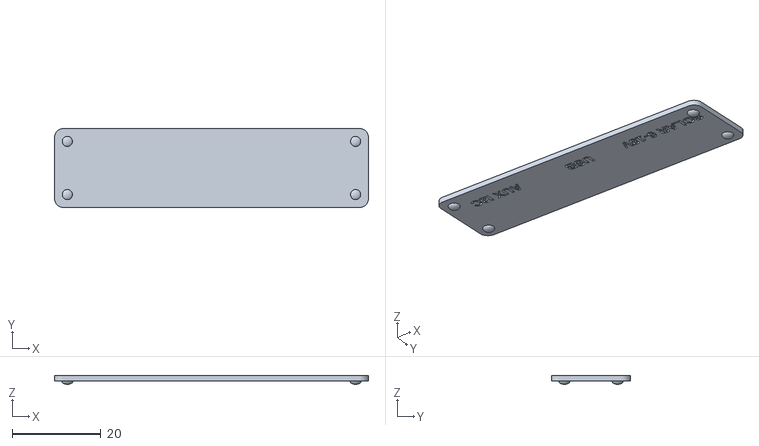
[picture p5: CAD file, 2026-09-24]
enclosure/stl/manifold_lid.stl
70.8 x 17.8 x 1.98

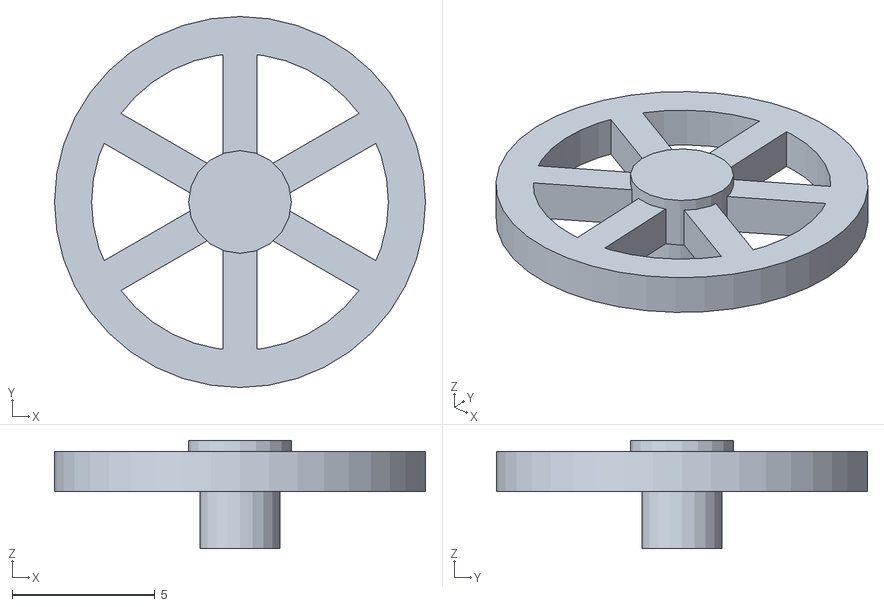
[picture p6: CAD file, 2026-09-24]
enclosure/stl/valve_cap.stl
13.0 x 13.0 x 3.80

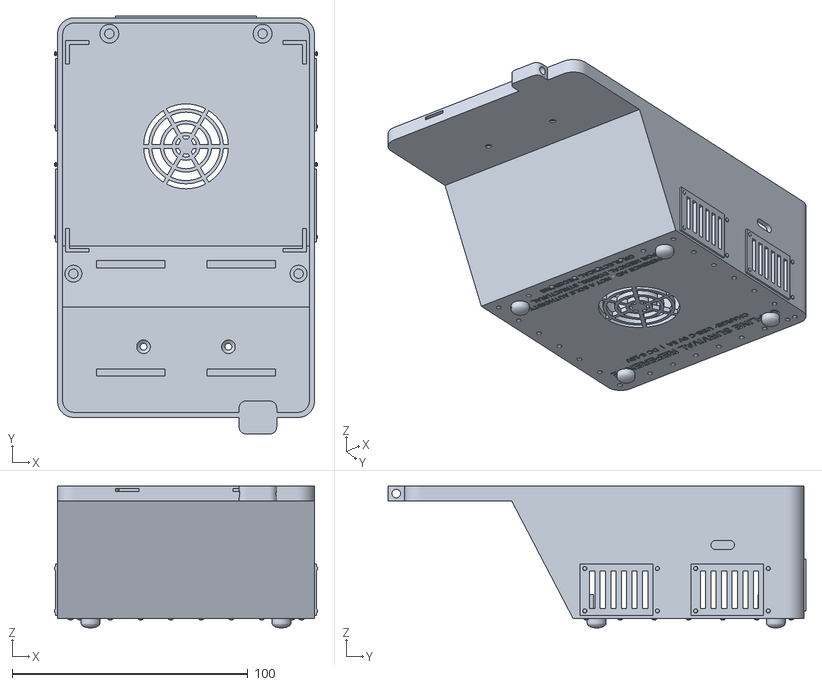
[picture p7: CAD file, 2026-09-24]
enclosure/stl/tub.stl
111.7 x 177.3 x 60.2

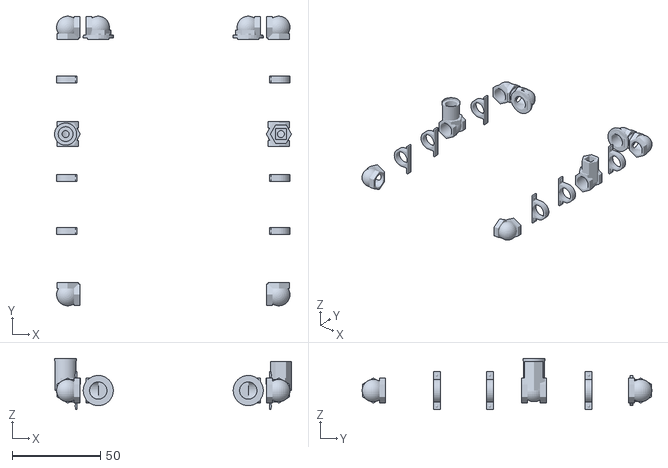
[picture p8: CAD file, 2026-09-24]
enclosure/stl/fittings.stl
134.3 x 164.2 x 29.0

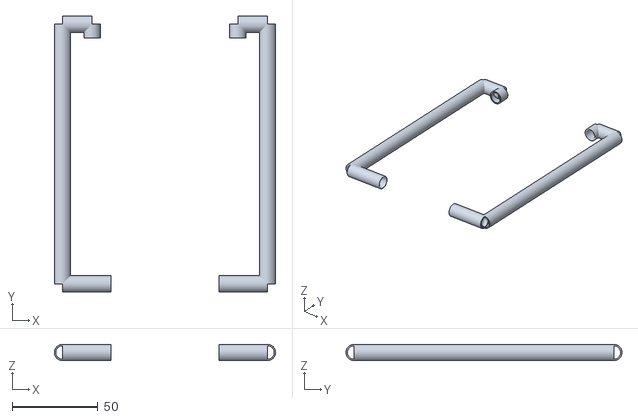
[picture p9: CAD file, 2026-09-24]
enclosure/stl/pipes.stl
129.1 x 161.0 x 9.53

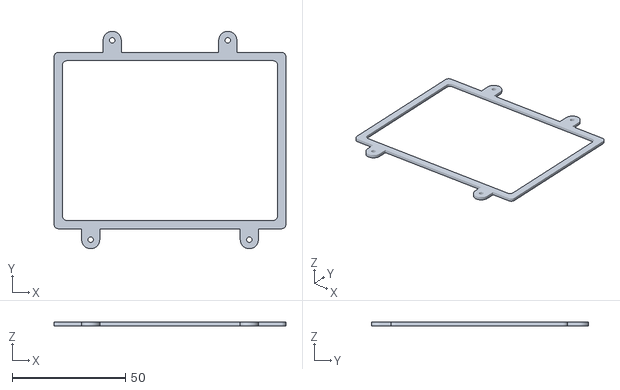
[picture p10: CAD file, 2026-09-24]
enclosure/stl/retainer.stl
102.4 x 96.0 x 1.60

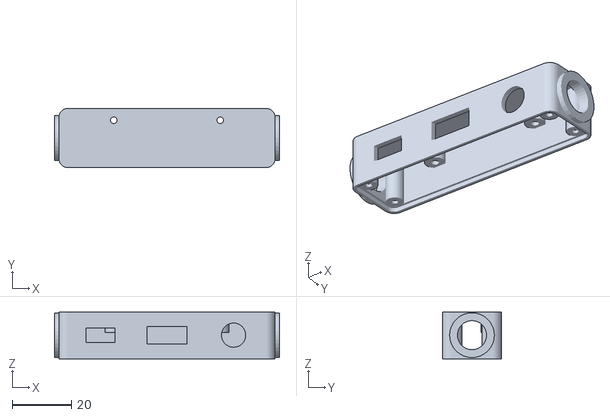
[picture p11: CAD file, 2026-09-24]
enclosure/stl/manifold.stl
76.0 x 20.0 x 15.8

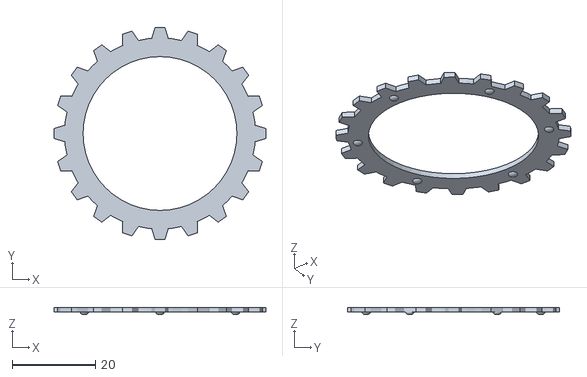
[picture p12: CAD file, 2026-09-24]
enclosure/stl/trim.stl
51.0 x 51.0 x 1.80

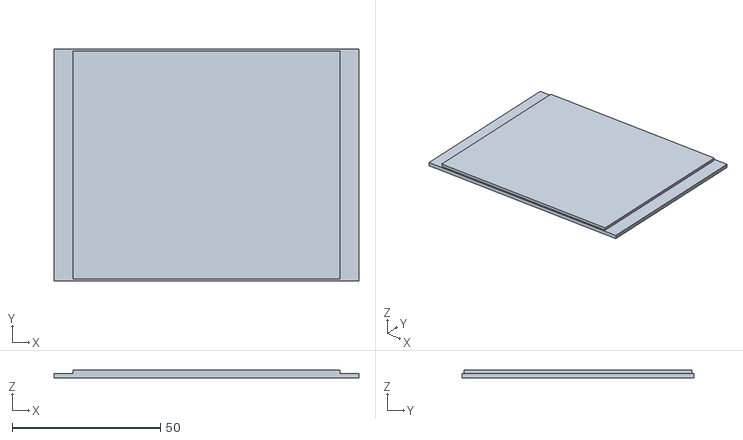
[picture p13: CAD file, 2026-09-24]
enclosure/stl/ghost_eink.stl
103.0 x 78.5 x 2.78

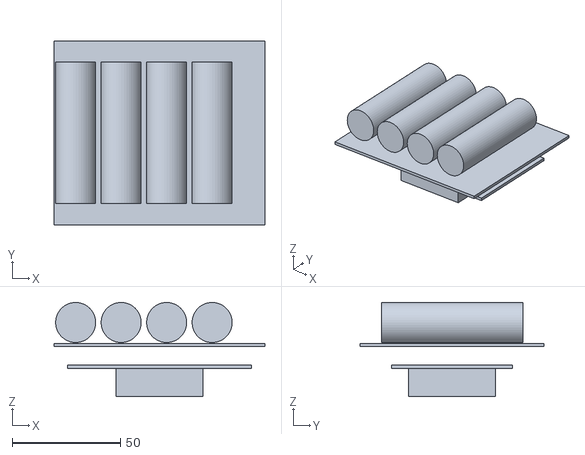
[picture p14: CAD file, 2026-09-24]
enclosure/stl/ghost_stack.stl
97.4 x 85.0 x 43.5

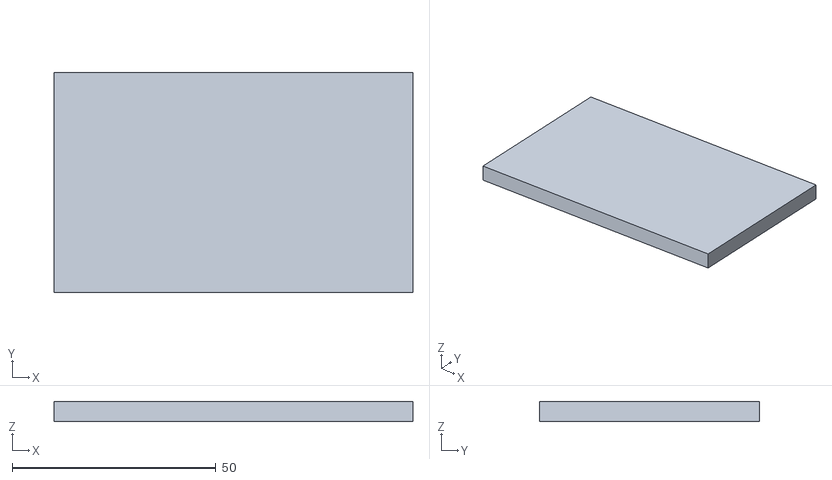
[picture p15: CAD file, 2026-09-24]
enclosure/stl/ghost_kb.stl
88.0 x 54.0 x 5.00

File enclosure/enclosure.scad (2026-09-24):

// enclosure.scad — handheld enclosure for the offline survival reference device
//
// Layout (device held upright, front face toward you):
//   top:    Waveshare 4.2" e-Paper Module V2 (400x300)
//   bottom: M5Stack CardKB v1.1 keyboard
//   behind the screen only: Geekworm X1202 UPS + 4x 18650 (toward the
//           screen) with the Raspberry Pi 5 + active cooler on top of it,
//           facing the BACK wall
//
// v0.4 airflow: the Pi faces the back so its cooler fan (which draws air in
// through its top) breathes through a porthole grille in the back wall.
// The battery pack sits between the Pi and the e-paper panel as a heat
// shield. Cool air enters the porthole and the low side vents; hot air
// rises out of the upper side louvers and the top-edge vents. Standoff feet
// keep the porthole clear when the device lies on its back.
//
// Printed parts:
//   tub      — rear shell: stack guides, porthole intake, vents, charge ports
//   bezel    — front cap: screen window, keyboard opening, nameplates
//   retainer — ring that clamps the screen against the bezel
//   trim     — brass gear ring for the porthole (print in brass-colour, glue on)
//   plumbing — functional: the pipes are cable conduits (3/8" copper tube,
//              7.9 mm bore). Left "data line": USB + accessory I2C + gauge
//              LED. Right "power line": 6-18 V solar/car input + power
//              button. The gauge is a real RGB status light; the valve wheel
//              is the real power button. All lines end at a junction box
//              under the step, where the external ports are.
//   fittings / manifold / manifold_lid / gauge_face / valve_cap — printed
//              parts for the plumbing (pipes can be real copper + real brass
//              3/8" compression elbows/tees, or printed)
//
// Render one part:  openscad -D 'part="tub"' -o tub.stl enclosure.scad
//
// Sizes marked VERIFY are not in any datasheet — measure the real parts with
// calipers before sending anything to a print service.

part = "assembly"; // tub | bezel | retainer | trim | pipes | fittings | manifold | manifold_lid | gauge_face | valve_cap | ghost_stack | ghost_eink | ghost_kb | assembly

$fn = 48;

// ---------------- components ----------------
// Waveshare 4.2inch e-Paper Module manual: driver board 103.0 x 78.5 mm,
// display area 84.8 x 63.6 mm, panel 90.1 x 77.0 x 1.18 mm.
eink_pcb   = [103.0, 78.5, 1.6];
eink_glass = [90.1, 77.0, 1.18];
eink_view  = [84.8, 63.6];
eink_view_off  = [0, 0];   // active-area centre relative to board centre — VERIFY
eink_back_clear = 3.2;     // connector + cable behind the board — VERIFY

// M5Stack store: CardKB v1.1 product size 88.0 x 54.0 x 5.0 mm.
kb     = [88.0, 54.0, 5.0];
kb_lip = 1.5;
kb_foam = 1.0;

// Geekworm X1202: PCB 97.4 x 85 mm. Stack height (cells + X1202 + Pi 5 +
// active cooler) is not published; Geekworm's own case is 62.8 mm tall
// outside, so this is an estimate below that — VERIFY.
stack = [97.4, 85.0, 48.0];
fan_gap    = 2.0;          // air gap between the cooler's fan and the back wall
cooler_off = [0, 0];       // fan centre relative to stack centre (seen from behind) — VERIFY
grille_d   = 36;           // porthole intake diameter (Pi 5 active cooler fan ≈ 30 mm)

// X1202 USB-C charge port on the right-hand wall (the X1202 is the front
// board of the stack, so its edge ports sit ~27-31 mm above the floor) — VERIFY.
// Its DC jack is extended through the power line to the junction box.
usbc_y_off = 20;
port_z     = 29;

// ---------------- shell ----------------
wall      = 2.2;
floor_t   = 2.2;
bezel_t   = 2.0;
skirt     = 3.0;
gap       = 0.8;
corner_r  = 7;
edge_ch   = 1.6;
margin_top = 10;
margin_bot = 12;
divider   = 9;
taper_len = 26;
kb_rail_h = 1.0;
retainer_t = 1.6;
boss_r    = 4.0;
mid_boss_r = 3.6;
insert_d  = 4.0;   // M3 heat-set insert (short, 4 mm)
screw_d   = 3.4;
head_d    = 6.2;
post_r    = 2.5;
post_hole = 1.8;   // M2 self-tapping
feet_h    = 4.0;   // standoff feet on the back keep the porthole breathing
deco_h    = 0.8;   // height of raised bead frames / nameplates
pipe_od   = 9.53;  // 3/8" soft copper tube
pipe_id   = 7.9;
fit_r     = pipe_od/2 + 1.6;   // fitting body radius (≈ 3/8" compression elbow/tee)
pz        = 42;    // depth of every pipe run: clear of vents (≤23) and the USB-C port (≤33)
px_off    = 5.3;   // pipe centre outside each side wall
gland_x   = 12;    // pipes enter the case through the top face, this far in from each side
top_rise  = 6;     // top loop height above the top face (doubles as a corner roll bar)
tee_y     = 115;   // gauge (left) / power valve (right)
clamp_ys  = [146, 90, 60];
rivets    = true;
label     = "OFFLINE SURVIVAL REFERENCE";
top_label = "FIELD REFERENCE  MK I";
back_top  = [["OFFLINE SURVIVAL REFERENCE", 4.2],
             ["CHARGE: USB-C 5V 5A  |  DC 6-18V", 2.9]];
back_bot  = [["REFERENCE AID - NOT A SOLE AUTHORITY", 2.7],
             ["FOR MEDICAL DOSING, STRUCTURAL", 2.7],
             ["OR ELECTRICAL DECISIONS", 2.7]];

// ---------------- derived ----------------
screen_layer = eink_glass[2] + eink_pcb[2] + eink_back_clear;
D_top = floor_t + fan_gap + stack[2] + 1 + screen_layer + bezel_t;
D_bot = floor_t + kb_rail_h + kb_foam + kb[2] + bezel_t + 0.2;
bezel_depth = bezel_t + skirt;
split_z = D_top - bezel_depth;
face_z  = D_top - bezel_t;

inner_w = max(eink_pcb[0], stack[0], kb[0]) + 2*gap;
inner_h = margin_bot + kb[1] + divider + eink_pcb[1] + margin_top + 2*gap;
W = inner_w + 2*wall;
H = inner_h + 2*wall;

kb_cy   = wall + gap + margin_bot + kb[1]/2;
kb_top  = wall + gap + margin_bot + kb[1];
div_cy  = kb_top + divider/2;
ek_cy   = kb_top + divider + eink_pcb[1]/2;
top_cy  = H - wall - gap - margin_top/2;
label_cy = wall + margin_bot/2 - 0.2;

st_y1 = H - wall - gap - margin_top + 1 - stack[1];
st_cy = st_y1 + stack[1]/2;
ys = st_y1 - 1;
ye = ys - taper_len;
fan_c = [W/2 - cooler_off[0], st_cy + cooler_off[1]];   // seen from behind, X is mirrored

bosses     = [[22, H-wall-4.5], [W-22, H-wall-4.5]];   // inboard of the top pipe glands
side_free  = (inner_w - kb[0]) / 2;
mid_bosses = [[wall+side_free/2+0.4, kb_top - 8], [W-wall-side_free/2-0.4, kb_top - 8]];
all_bosses = concat(bosses, mid_bosses);
posts = [[W/2-25.5, top_cy], [W/2+25.5, top_cy], [W/2-35, div_cy], [W/2+35, div_cy]];

win_outer = [eink_view[0] + 1 + 2*bezel_t, eink_view[1] + 1 + 2*bezel_t];
plate     = [76, 7.6];     // bottom nameplate
top_plate = [58, 6.6];

// junction box under the step (behind the thin keyboard section)
man = [18, W - 18, 14, 34, 34, D_top - D_bot];   // x0, x1, y0, y1, z0, z1
man_wall = 1.8;
pipe_bot_y = (man[2] + man[3]) / 2;
// left-side pipe centreline (right side is mirrored)
P_A = [gland_x, H - 2, pz];            // inside the top gland
P_B = [gland_x, H + top_rise, pz];     // elbow
P_C = [-px_off, H + top_rise, pz];     // elbow
P_T = [-px_off, tee_y, pz];            // tee: gauge / valve
P_D = [-px_off, pipe_bot_y, pz];       // elbow
P_E = [man[0] + 5, pipe_bot_y, pz];    // into the junction box
gauge_c = [-px_off - 1.2, tee_y];

vent_z   = floor_t + fan_gap + 8;              // vents level with the cooler
vent_low  = st_y1 + 6;                          // intake band
vent_high = st_y1 + stack[1] - 32;              // exhaust band

echo(str("Outer W x H = ", W, " x ", H, " mm; depth ", D_top, " mm behind screen, ",
         D_bot, " mm at keyboard (+", feet_h, " mm feet)"));

// ---------------- helpers ----------------
module rbox(s, r) {
    r2 = max(min(r, s[0]/2 - 0.01, s[1]/2 - 0.01), 0.01);
    hull() for (x = [r2, s[0]-r2], y = [r2, s[1]-r2])
        translate([x, y, 0]) cylinder(r = r2, h = s[2]);
}
module crbox(s, r, ct = 0, cb = 0) {
    hull() {
        translate([cb, cb, 0]) rbox([s[0] - 2*cb, s[1] - 2*cb, 0.01], r - cb);
        translate([0, 0, cb]) rbox([s[0], s[1], s[2] - cb - ct], r);
        translate([ct, ct, s[2] - 0.01]) rbox([s[0] - 2*ct, s[1] - 2*ct, 0.01], r - ct);
    }
}
module crect(c, s, h, r = 1) {
    translate([c[0]-s[0]/2, c[1]-s[1]/2, 0]) rbox([s[0], s[1], h], r);
}
module ring_rect(c, outer, inner, h, r = 1.5) {
    difference() {
        crect(c, outer, h, r);
        translate([0, 0, -1]) crect(c, inner, h + 2, r);
    }
}
module rivet(r = 1.2) { scale([1, 1, 0.6]) sphere(r = r); }
module slot(len, w, h) {
    hull() for (y = [-len/2 + w/2, len/2 - w/2]) translate([0, y, 0]) cylinder(d = w, h = h);
}
module gear2d(r_root, r_tip, teeth) {
    union() {
        circle(r = r_root);
        for (i = [0 : teeth - 1]) rotate(i * 360 / teeth)
            polygon([[r_root - 0.5, -2.1], [r_tip, -1.2], [r_tip, 1.2], [r_root - 0.5, 2.1]]);
    }
}
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

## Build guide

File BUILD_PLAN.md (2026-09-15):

# Offline "Civilization Restart" Device — Build Plan
Raspberry Pi 5 (8GB RAM / 128GB storage) + local LLM + e-ink text screen

## What you already have
- Raspberry Pi 5, 8GB RAM, 128GB storage, official heatsink+fan case
- Arduino starter kit (Uno-class board + basic sensors/buttons/breadboard)

This is enough to start on software today, before any parts arrive.

---

## Phase 0 — What to buy
| Item | Why | Notes |
|---|---|---|
| E-ink display (Waveshare 2.13"–4.2" e-Paper HAT, SPI) | "Calculator screen" text reader; holds text with zero power once drawn | 2.13" is cheap/small, 4.2" is much more readable for paragraphs |
| Small USB or matrix keypad | Input without a full keyboard | Your Arduino kit can drive a matrix keypad and send keystrokes to the Pi over serial/USB |
| USB power bank or LiFePO4 pack + solar panel (10-20W) | Runs the device through an outage | Pi 5 draws ~5-8W under load; a 20,000mAh bank gives many hours |
| Solar charge controller / UPS HAT (e.g. PiJuice, Waveshare UPS HAT) | Handles charging + safe shutdown on power loss | Optional but strongly recommended for a "disaster" device |
| MicroSD or USB drive backup of everything | Redundancy | Your 128GB is plenty for OS + model + full text corpus |

You can build and test 100% of the software (Phases 1–4) on the Pi right now using just a monitor/keyboard over SSH, then add the e-ink screen and power system once parts arrive.

---

## Phase 1 — Base OS setup
1. Flash **Raspberry Pi OS Lite (64-bit)** — no desktop, saves RAM for the model.
2. Enable SSH + set a static hostname during imaging (Raspberry Pi Imager lets you do this headlessly).
3. `sudo apt update && sudo apt full-upgrade -y`
4. Enable SPI (needed for the e-ink screen later): `sudo raspi-config` → Interface Options → SPI → Enable.

---

## Phase 2 — Local LLM engine
On an 8GB Pi 5, the sweet spot is a **3–4B parameter model, Q4 quantized**, which gives usable speed (5–10 tokens/sec) and decent reasoning. Recommended: **Phi-3 Mini 3.8B (Q4_K_M GGUF)**. Gemma 2 2B is a faster/lighter fallback; Llama 3 8B Q4 works but will feel noticeably slower.

Run `setup.sh` (included) — it installs `llama.cpp` compiled for ARM, and downloads a starting model. You can swap models later; nothing else in the stack changes.

**Important design decision:** don't rely on the raw model's memory for technical "how to build X" instructions — small quantized models hallucinate on step-by-step technical detail (measurements, ratios, sequences). Instead, use it as a **reading/explaining engine on top of a real text library** (Phase 3). This is far more trustworthy for something you might actually depend on.

---

## Phase 3 — The offline knowledge library (RAG)
This is the actual "kickstart civilization" content. Two tiers:

**Tier 1 — public domain, safe to download directly, no copyright issue:**
- U.S. Army Survival Manual, FM 21-76 (fire, water, shelter, edible plants, first aid)
- U.S. Army Field Manuals on basic engineering, knots, land navigation
- Where There Is No Doctor / Where There Is No Dentist (Hesperian Health Guides — free for humanitarian/personal use)
- Old public-domain chemistry, blacksmithing, and mechanics textbooks (archive.org has many pre-1929 texts that are fully public domain)

**Tier 2 — the best single resource for this exact goal, but copyrighted:**
- *"The Knowledge: How to Rebuild Civilization in the Aftermath of a Cataclysm"* by Lewis Dartnell. It's essentially a written version of what you're describing — fire, metallurgy, chemistry, agriculture, medicine, from scratch. **Buy a copy**; if you own it, you can scan/OCR your personal copy for your own offline device. I can't provide a download of the copyrighted text itself, but the RAG pipeline below will index whatever text files you legally add to the `corpus/` folder — that includes your own scanned copy once you own it.

Run `rag_build.py` (included) to turn a folder of `.txt`/`.pdf` files into a searchable local vector index using a small embedding model (`all-MiniLM-L6-v2`, ~90MB, runs fine on the Pi). This gives you fast, accurate, grounded lookups instead of hallucinated answers.

---

## Phase 4 — Main application loop
`main.py` (included) does:
1. Take a typed question (from keyboard now, keypad later).
2. Retrieve the most relevant passages from your indexed library.
3. Feed those passages + the question to the local LLM, asking it to answer *using only the retrieved text*.
4. Print the answer to the terminal (Phase 4) or the e-ink screen (Phase 5).

This keeps responses grounded in real reference material while still letting you ask natural-language follow-up questions.

---

## Phase 5 — Screen + input (Arduino's role)
Two good options, both use your existing Arduino kit:

**Option A — Arduino as input controller only (simplest):**
- Wire a matrix keypad to the Arduino.
- Arduino sketch reads keypresses and sends them over USB-serial to the Pi as plain text.
- Pi's `main.py` reads from the serial port instead of a keyboard.
- E-ink display connects directly to the Pi's SPI/GPIO pins (Waveshare provides a Python library for this — no Arduino needed for the display side).

**Option B — Arduino as full front-end controller:**
- Arduino drives the keypad AND a small character LCD (like a 16x2 or Nokia 5110) directly, if you want the e-ink display reserved for longer "read mode" pages later.
- Pi does all the thinking, sends short text back to Arduino over serial, Arduino displays it.

Start with Option A — it's less wiring and uses the e-ink screen's real strength (long, readable, power-free text).

---

## Phase 6 — Power system
- Pi 5 pulls roughly 3-5W idle, up to 8-12W during LLM inference (CPU maxed on all 4 cores).
- A 20-30W solar panel + a LiFePO4 power bank (10,000-20,000mAh) rated for at least 3A output will keep it running through daylight outages and store enough for overnight use.
- Add a UPS HAT if you want safe automatic shutdown when the battery gets low, to avoid SD card corruption.
- e-ink displays draw power only when refreshing the screen, not while showing static text — this is the biggest power win in the whole design, so lean on it (update the screen only when there's a new answer, not continuously).

---

## Phase 7 — Enclosure & assembly
- Keep the official heatsink/fan case; LLM inference will run the CPU hot for sustained periods.
- 3D print or hand-build a simple two-layer enclosure: Pi + battery on the bottom, e-ink screen + keypad on top, similar to a chunky calculator or a Game Boy.
- Route the fan intake/exhaust so it's not blocked by the enclosure.

---

## Suggested build order (what to actually do first)
1. Today: flash the Pi, SSH in, run `setup.sh`, confirm the model answers questions in the terminal.
2. This week: gather Tier 1 public-domain texts, run `rag_build.py`, confirm grounded answers work better than raw model answers.
3. When display arrives: wire up e-ink, get `main.py` printing to it instead of the terminal.
4. When keypad/Arduino wiring is ready: swap keyboard input for serial input from the Arduino.
5. Last: add solar + battery, test a full day unplugged.

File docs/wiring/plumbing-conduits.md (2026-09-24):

# Plumbing = conduits: what runs through each pipe

The copper pipes on the enclosure are cable conduits (3/8" OD soft copper,
7.9 mm bore). Each line enters the case through a gland in the top face,
runs down the side, and ends at the junction box under the step, where the
external ports are. Model: `enclosure/enclosure.scad` (`plumbing` section).

## Left pipe — data line

| Wires | From (inside the case) | To | Purpose |
|---|---|---|---|
| USB 2.0 (4× 26 AWG: 5V, D−, D+, GND, twisted D± pair) | Pi 5 USB-A port via a solderable USB-A **plug** breakout | USB-A **socket** breakout in the junction box | Load new books/manuals from a USB stick; back up the corpus and logs |
| I2C accessory (4× 28 AWG: 3V3, GND, SDA, SCL) | Pi GPIO pins 1/6/3/5 (same bus as CardKB 0x5F and the X1202 fuel gauge) | Grove socket, "AUX I2C" | Plug-in modules without opening the case (e.g. BME280 barometer for weather, compass, GPS with I2C). Check each module's I2C address doesn't clash with 0x5F / the X1202 gauge. |
| Status LED (4× 28 AWG: R, G, B, common GND) | 3 Pi GPIOs through 3× 220 Ω resistors | 5 mm common-cathode RGB LED in the gauge housing (tee branch) | Battery level (green / amber / red from the X1202 fuel gauge) and a "thinking" pulse while an answer generates |

## Right pipe — power line

| Wires | From | To | Purpose |
|---|---|---|---|
| DC in (2× 18 AWG silicone) | 5.5×2.1 mm **plug** pigtail into the X1202's DC jack | 5.5×2.1 mm panel-mount jack, "SOLAR 6-18V" | Solar panel (via a 12 V regulator — never a raw panel, its open-circuit voltage exceeds 18 V) or car 12 V |
| Power button (2× 28 AWG) | Pi 5 J2 power-button header | 6×6 mm tactile switch in the valve body; the valve wheel is its cap | Power on / clean shutdown from outside the case |

The X1202's USB-C charge port stays directly on the right wall (it carries
5 V 5 A — no extension).

## Parts for the plumbing (per device)

- 3/8" OD soft copper tube, ~420 mm total (per side centreline lengths from
  the model: riser 8, top run 17.3, upper side 60.5, lower side 91, into box
  28.3 mm — subtract your fittings' socket depth)
- 6× 3/8" brass compression elbows, 2× 3/8" brass compression tees
  (or print `fittings`)
- Printed: glands/clamps (`fittings`), `manifold` + `manifold_lid`,
  `gauge_face` (white or clear filament), `valve_cap`
- USB-A plug + socket solderable breakouts, Grove socket, 5.5×2.1 panel jack
  + 5.5×2.1 plug pigtail, 5 mm RGB LED (common cathode) + 3× 220 Ω,
  6×6 mm tactile switch, silicone wire (18/26/28 AWG), heat-shrink
- Rubber grommet or heat-shrink collar at every tube end — copper edges cut
  insulation. Deburr each cut.

## Notes
- Wire through each pipe before fitting it: connectors don't fit the 7.9 mm
  bore, so the breakouts are soldered after the wires are pulled through.
- The tubes are not electrically connected to anything; keep it that way
  (insulated wires only, no bare conductors touching copper).

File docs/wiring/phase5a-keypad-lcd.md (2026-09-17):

# Phase 5a wiring — 4x4 keypad + LCD1602 on Arduino UNO (LAFVIN kit)

Parts from the LAFVIN Super Starter Kit for UNO R3:
UNO R3, membrane 4x4 keypad, LCD1602 (16-pin parallel), 10K potentiometer,
breadboard, jumper wires, one 220Ω resistor (backlight).

Photograph the finished wiring and save the photo in this folder
(git rule: every hardware phase gets pictures).

## 1. Keypad (8-pin ribbon)

Hold the keypad with the keys facing you, ribbon at the bottom;
ribbon pins are numbered 1..8 left to right.

| Keypad ribbon pin | Meaning | Arduino pin |
|---|---|---|
| 1 | Row 1 (1 2 3 A) | D9 |
| 2 | Row 2 (4 5 6 B) | D8 |
| 3 | Row 3 (7 8 9 C) | D7 |
| 4 | Row 4 (* 0 # D) | D6 |
| 5 | Col 1 (1 4 7 *) | D5 |
| 6 | Col 2 (2 5 8 0) | D4 |
| 7 | Col 3 (3 6 9 #) | D3 |
| 8 | Col 4 (A B C D) | D2 |

(If rows/cols behave swapped or mirrored, don't rewire — tell the build
assistant which keys come out wrong; it's a keymap fix in the sketch.)

## 2. LCD1602 with I2C backpack — 4 wires, no breadboard

The kit's LCD turned out to have an I2C backpack (small board soldered on
the back with 4 pins: GND, VCC, SDA, SCL). That replaces the whole
16-pin parallel wiring, the contrast pot, and the backlight resistor
(contrast is the tiny blue trim screw on the backpack itself).

Use 4 female-to-male jumpers (female end on the backpack pin):

| Backpack pin | Arduino pin |
|---|---|
| GND | GND |
| VCC | 5V |
| SDA | A4 |
| SCL | A5 |

A4/A5 are the UNO's I2C bus — the LCD must be on exactly those two.
If the screen backlights but shows no text: (a) turn the blue trim screw
on the backpack with a small screwdriver until characters appear;
(b) if still blank, the backpack's address is 0x3F — change LCD_ADDR in
keypad_serial.ino.

## 3. Flash + connect

1. Arduino IDE → Library Manager → install "Keypad" (Mark Stanley /
   Alexander Brevig) AND "LiquidCrystal I2C" (Frank de Brabander).
2. Open scripts/keypad_serial.ino, board "Arduino Uno", flash.
3. LCD should say `Survival ref. / Type & press #`. Test typing standalone
   first (multi-tap: 2=abc, *=backspace, A=commit letter, #=send).
4. Plug the Arduino into the Pi via USB. On the Pi: `ls /dev/ttyACM*`.
5. In scripts/main.py set `INPUT_MODE = "serial"` (and SERIAL_PORT if not
   /dev/ttyACM0), run it, type a question on the keypad, press `#`.
   Answer pages appear on the LCD every ~3 s.

## Typing cheat sheet

| Key | Taps |
|---|---|
| 2..9 | letters then the digit (2=a b c 2) |
| 1 | 1 . , ? ! ' |
| 0 | space |
| * | backspace |
| A | commit current letter immediately |
| # | send question |
| B C D | reserved (menus later) |

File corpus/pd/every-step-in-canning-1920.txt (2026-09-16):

The Project Gutenberg eBook of Every Step in Canning: The Cold-Pack Method
    
This eBook is for the use of anyone anywhere in the United States and
most other parts of the world at no cost and with almost no restrictions
whatsoever. You may copy it, give it away or re-use it under the terms
of the Project Gutenberg License included with this eBook or online
at www.gutenberg.org. If you are not located in the United States,
you will have to check the laws of the country where you are located
before using this eBook.

Title: Every Step in Canning: The Cold-Pack Method

Author: Grace Viall Gray

Release date: October 17, 2004 [eBook #13775]
                Most recently updated: October 28, 2024

Language: English

Other information and formats: www.gutenberg.org/ebooks/13775

Credits: E-text prepared by John Hagerson, Kevin Handy, Stephen Schulze, and the Project Gutenberg Online Distributed Proofreading Team

*** START OF THE PROJECT GUTENBERG EBOOK EVERY STEP IN CANNING: THE COLD-PACK METHOD ***

EVERY STEP IN CANNING

The Cold-Pack Method

by

GRACE VIALL GRAY, PH.B., ED.B

Formerly Associate Professor of Home Economics,
Iowa State College

1920

PREFACE

It was six years ago that I first heard of the One Period, Cold-Pack
Method of canning. A little circular was put in my hand one day at a
federated club meeting announcing the fact that in a few weeks there
would be a cold-pack demonstration about fifty miles away. Immediately
I announced that I was going to the demonstrations. So leaving my
small daughter with my mother, I went to the Normal School at DeKalb,
Illinois, and heard and saw for the first time cold-pack canning.

It is sufficient to say that those three days were so crowded full of
interest and new messages on the gospel of canning that I felt amply
repaid for going fifty miles. As a result of that trip, the first
story ever published on cold-pack canning appeared in _The Country
Gentleman_ and I had the pleasure of writing it. So enthused was I
over this new, efficient and easy way to can not only fruits but hard
vegetables, such as peas, corn and beans, that I wanted to carry the
good news into the kitchen of other busy housewives and mothers.

My mother had insisted that I take with me my younger sister, just
from college, but with no domestic science tendencies. So, much
against her wishes, preferring rather to do some settlement work, my
sister went with me. The canning was so interesting that for the first
time in her life, my sister became enthusiastic over one phase of
cooking. My mother was so pleased at this zeal that when she received
my sister's letter written from DeKalb, saying, "Mother, I am
enthused about this canning and want to can everything in sight this
summer," she hastily washed all available glass jars and tops and had
everything in readiness for young daughter's return. And we canned. We
were not content to can alone but invited all the neighbors in and
taught them how to can. Our community canned more things and more
unusual things, including the hard vegetables, that year than they had
ever attempted before.

Do not think for one minute it was all easy sailing, for there were
doubting Thomases, but it only took time and _results_ to convert even
the most skeptical ones. And here I must make a confession. It was
much easier for my sister, unversed in any phase of canning, to master
this new method than it was for me with my four years' training course
and my five years of teaching canning behind me. And this is the
reason. She had nothing to "unlearn," she knew no other method whereas
I had to "unlearn" all my previous methods.

The one period, cold-pack method is so entirely different from the old
hot pack or open kettle method that to be successful you must forget
all you ever knew and be willing to be taught anew. And right here is
where many women "fall down"--they are not willing to admit that they
know nothing about it and so do not get accurate information about it.
They are so afraid of appearing ignorant. This false feeling is the
greatest obstacle in woman's way.

I still go into small towns on my lecture trips and women will say,
"Oh, that cold-pack canning isn't new to me. I have used it for thirty
years." And when I show my surprise, they further enlighten me with,
"and my mother used it before me, too." With a little tactful
questioning I usually get these answers: "Of course, I do not hot dip
and cold dip. I never heard of that before. I pack the products into
the cold jars and for all vegetables I use a preserving powder because
there is no way on earth to keep corn and peas and such things unless
you put something into them to keep them. Fruit will keep all right.
Then I cook them in my wash boiler until they are done." And when I
ask, "How do you know when they are done," I invariably get the
answer, "Oh, I take out a jar once in a while and try it." It seems
like such a hopeless task to change all these old-fashioned,
out-of-date methods of cooking but with a great amount of patience and
much actual canning it can usually be done. Not always, of course, for
there are some women who seem to delight in sticking to the old rather
than try the new.

The present book is therefore designed for all interested in greater
efficiency in the home, including not only students of home economics
but all persons who have charge of homes and are interested in
learning new, efficient, time and labor saving methods.

In the preparation of this book I have received much help from Mr.
O.H. Benson, Agriculturist in charge of the government Boys' and
Girls' Club Work, and my first instructor in Cold-Pack Canning. I also
wish to acknowledge my appreciation to those who have helped to make
this book possible by contributing information, advice and
encouragement.

GRACE VIALL GRAY.

October, 1919.

  CONTENTS

      I. GETTING READY TO CAN

     II. SOFT FRUITS AND BERRIES

    III. HARD FRUITS

     IV. VEGETABLES

      V. SOUPS

     VI. JELLIES, JAMS, PRESERVES, MARMALADES, FRUIT JUICES AND SIRUPS

    VII. MEAT

   VIII. FISH

     IX. EASY METHODS OF CANNING IN TIN

      X. INTERMITTENT CANNING OR FRACTIONAL STERILIZATION

     XI. WHY CANNED GOODS SPOIL

     XI. I GETTING READY TO DRY

   XIII. HOW TO DRY FRUITS

    XIV. HOW TO DRY VEGETABLES

     XV. EVERY STEP IN BRINING

    XVI. CURING, SMOKING AND PRESERVING MEAT

   XVII. PRESERVED OR "CANNED" EGGS

  XVIII. HOME STORAGE OF VEGETABLES

    XIX. HOW TO MARKET HOME CANNED PRODUCE

EVERY STEP IN CANNING

CHAPTER I

GETTING READY TO CAN

Before the World War, housewives had lost the good habit of canning,
preserving and pickling. It was easier to buy California fruits by the
case and canned vegetables by the dozen or half dozen cans, according
to the size of the family. There is no doubt it was cheaper and
decidedly easier to purchase canned fruits, vegetables, greens, soups
and meats than to take time and strength in the very hottest season of
the year to do our own canning.

But what was true then is not true now. The war taught us thrift. The
crime of wasting even a few tomatoes or berries has sunk into our
minds to stay forever; scientific canning methods have been adopted by
the modern woman. Women who had never canned in days before the war
had to can during war days. Food was so scarce and so high in price
that to buy fancy or even plain canned products was a severe strain on
the average housewife's purse. The American woman, as was to be
expected, came quickly and eagerly to the front with the solution and
the slogan: "More gardens and more canning and preserving at home."

A great garden and canning movement swept the whole country. As I have
just said, women who had never canned before became vitally interested
in putting up not merely a few jars of this and that, but jars upon
jars of canned fruits, vegetables and greens; and so great was their
delight in the finished products that again and again I heard them
say: "Never again shall we depend upon the grocery to supply us with
canned goods."

If these women had been obliged to use the same methods that their
grandmothers used before them, they would have canned just the same,
because it was their patriotic duty to do so; but they would have
canned without the enthusiasm and zeal that was so apparent during the
summers of 1917 and 1918. This enthusiasm was a result of new canning
methods, methods unknown to our grandmothers. The women of to-day were
forced into a new field and learned how satisfying and well worth
while the results were. It is safe to guarantee that every
home-canning recruit will become a home-canning veteran.

The fascination of doing one's own canning after one has learned how
simple and economical it is will be lasting. No one need fear that
home canning is going to suffer because the war ended the immediate
necessity for it. Home canning has come into its own because of the
war, and it has come to stay because of its many merits.

There are four methods of canning that are employed by women all over
the United States. They are the "open-kettle," the "intermittent," the
"cold-water" and the "cold-pack" methods.

DRAWBACKS OF THE OLD METHODS

The "open-kettle," or "hot-pack," method is the oldest. It was largely
used in the pre-war days. The food is completely cooked in the
preserving kettle, and is then packed into hot, sterilized jars, after
which the jars are sealed. As the packing into the jar is done after
the sterilization has been completed, there is always a possibility of
bacteria and spores entering the jar with the cooked food and the air.
Fruits can be handled successfully in this way, but this method cannot
be used for vegetables, greens and meats. It is a very laborious, hot
and hard way to can. Modern housewives are discarding it more and more
every year and are beginning to place their trust in the newer and far
more scientific methods of canning.

The "intermittent," or fractional sterilization, method is still
beloved by some people who cling to the sure and hate to venture into
the new. Vegetables can be handled by this method as can all fruits
and meats. It is used rather extensively in the South, where they say
the conditions do not favor "cold-pack." The great objection to this
method of canning is that it requires three periods of sterilization
on three different days and three liftings of jars in and out of the
sterilizer.

What is sometimes called the "cold-water" method of canning should not
be confused with the "cold-pack" method. The "cold-water" is often
used in connection with the canning of rhubarb, green gooseberries and
a comparatively few other sour berry fruits. If the "cold-water"
method is used we would suggest that the product be thoroughly washed,
placed in a strainer, scalding water poured over it, and the product
then packed at once, in practically a fresh state, in the jars, and
clean, cold water applied until the jars are filled. If these steps
are taken carefully and quickly the method in most cases will be
successful with such acid products as I mentioned. As the products
will have to be cooked before they can be used many housewives do not
consider it any saving of time or labor to follow this method.

THE COLD-PACK METHOD

The method of to-day that came into its own during the war is known as
the "cold-pack" method of canning. It fought a long fight to prove
that it was a very efficient, economical and satisfactory process for
busy housewives to can everything that grows.

This is the method that I shall mostly refer to in this book, and if I
should omit the phrase "cold-pack" you will know that I am referring
to it. "Cold-pack" simply means that the products are packed cold in
their fresh and natural state in the glass jars or containers. To the
fruits hot sirup is applied; to the vegetables hot water and a little
salt are added. The sterilization is done in the glass jars or tin
containers after they are partly or entirely sealed, making it
practically impossible for bacteria or spores to enter after the
product has once been carefully sterilized or cooked. In following
this method vegetables should first be blanched in boiling water or
live steam, then quickly plunged into cold water and the skins
removed. The products are then packed in containers and sterilized
according to the instructions and recipes given later.

When we use the term sterilizing we simply mean cooking the product
for a certain period of time after the jar has been filled with food.
It is sometimes called processing. Sterilizing, processing, boiling
and cooking are all interchangeable terms and mean one and the same
thing.

By this "cold-pack," or cold-fill, method of canning, all food
products, including fruits, vegetables and meats, can be successfully
sterilized in a single period with but one handling of the product in
and out of the canner.

All the flavor is retained, the product is not cooked to a mushy pulp,
and the labor and time needed for the canning are less than in any
other method. The housewife's canning enemy, mold, is eliminated and
all bacteria and bacterial spores which cause vegetables and meat to
spoil are destroyed.

EXPENSIVE OUTFITS NOT ESSENTIAL

For this "cold-pack" method you can use whatever equipment you have in
the kitchen. Complicated equipment is not essential. Many of us have
purchased commercial outfits, for we know we can turn out more at the
end of a day and have found it well worth while to invest a few
dollars in equipment that enabled us to be more efficient. But if you
are a beginner and do not care to put any money in an unknown venture
use the available things at hand, just to prove to yourself and others
that it can be done.

Every type of glass jar manufactured can be used except those which
are sealed with wax. So dig into your storerooms, attics and basements
and bring forth all your old jars. If a top is in good condition and
will make a perfect seal when adjusted with a good rubber you can use
that jar.

If the tops cannot be restored to good condition it is poor economy to
use them. Imperfectly sealed jars are probably responsible for more
spoiled canned goods than any other cause. Good tops and good rubbers
are requisites for good canning.

For your canner, or sterilizer, you may use a wash boiler or a
galvanized bucket, such as is used for a garbage pail--a new one, of
course. Either is excellent where the family is small and the canning
is accordingly light. Some use the reservoir of the cookstove while
others employ a large vat. If you should have to buy the wash boiler
or pail see that it has a tight-fitting cover and be sure the pail
does not leak. Then all you have to do is to secure what we call a
false bottom, something that will keep the jars of fruit from touching
the direct bottom of the boiler or pail. This false bottom, remember,
is absolutely necessary, for without it the jars will break during the
boiling.

For this false bottom use a wire netting of half-inch mesh and cut it
to fit the bottom of the sterilizer, whether boiler, pail or bucket.
If you haven't any netting and do not care to purchase it a wooden
bottom can be made to fit the sterilizer, or if that is not available
put thin pieces of wood in the bottom--anything to keep the jars from
coming in direct contact with the bottom of the sterilizer.

If you have only a small quantity of berries or fruit to can use a
deep saucepan with a tight-fitting cover and a few slats of wood. This
rack is absolutely necessary to keep the contents of the jars from
becoming overheated. Even if they should not break there is a tendency
for part of the contents to escape under the cover and be lost. Do not
use hay, old clothes, newspapers or excelsior for a false bottom; they
are unsatisfactory because they do not allow proper circulation of
water.

Individual jar holders are very convenient and are preferred by many
women to the racks. Inexpensive racks with handles are on the market
and are worth what they cost in saved nerves and unburned fingers.
Some hold eight jars, others hold twelve. So it just lies with you,
individual housekeeper, whether you want a rack that will hold all
your jars or a set of individual holders that handles them separately.

To return to the subject of the canner, let me add that no matter what
kind you use, it must be at least three inches deeper than the tallest
jar. This will give room for the rack and an extra inch or two so that
the water will not boil over.

Besides the canners, the jars, the rubber rings and the rack you will
need one kettle for boiling water, into which the product may be put
for scalding or blanching; another kettle for water--if you haven't
running water--for the "cold dip."

If you use a homemade rack without handles you should have a jar
lifter of some kind for placing in and removing jars from the canner.
If individual holders are used this is not necessary, as they contain
an upright bail. Some women use a wire potato masher for lifting the
jars out of the canners. Other kitchen equipment, such as scales,
knives, spoons, wire basket or a piece of cheesecloth or muslin for
blanching or scalding the product, and the kitchen clock play their
part in canning.

No canning powder or any preservative is needed. If the product is
cooked in closed jars in the hot-water bath as directed the food will
be sterilized so that it will keep indefinitely. If it is desired to
add salt, sugar, sirup, vinegar or other flavor this may be done when
the product is packed in the jar.

A great many people have been led to believe through advertising
matter that it is both safe and practical to use canning compounds for
the preserving of vegetables which have proved hard to keep under the
commonly known methods of canning. The first argument against the use
of a canning compound is that it is unnecessary. It is possible to
sterilize any fruit or vegetable which grows on tree, vine, shrub or
in the ground by this cold-pack, single-period method of canning,
without the use of a compound. The second argument against it is that
many of the canning compounds are positively harmful to health. Some
of them contain as high as ninety-five per cent of boric acid.
Directors of county and state fairs should exclude from entry all
fruits and vegetables that have been preserved in any canning
compound. Perfect fruit can be produced without any chemical
preservative. The third argument is that they are expensive.

There are many modifications of the original wash boiler and garbage
pail cookers. These are all known as the hot-water-bath outfits. In
these outfits the products are all cooked in boiling water.

There are condensed-steam cookers under various names, where the
product is cooked in condensed steam. These steamers are generally
used for everyday cookery.

The water-seal outfit, the steam-pressure outfit and the aluminum
pressure cooker follow in order of efficiency as regards the time
required to sterilize food.

Following the hot-water canner in simplicity of construction and
manipulation is the water-seal cooker. The temperature of the
hot-water-seal outfit is a little higher than the homemade or
hot-water-bath outfit; so time is saved in the sterilizing.

The steam-pressure and the pressure cookers are more complicated but
more efficient. Some prefer the aluminum pressure cooker because it
can be used for everyday cooking in the home.

Pressure cookers are expensive, but they are worth their price, as
they are used daily and not just during the canning season.

Here are examples of how they rank as to time required: In a
hot-water-bath outfit soft fruits must be sterilized sixteen minutes;
in a steamer, sixteen minutes; in a water-seal outfit, twelve minutes;
in a steam-pressure-outfit under five pounds of steam, ten minutes; in
an aluminum pressure cooker outfit with ten pounds of steam, five
minutes.

It takes longest to can with a homemade or hot-water-bath outfit; the
shortest and quickest method is with the pressure cooker that has a
pressure of ten pounds or more. Each housewife has different financial
problems, different hours of working and different ways of working.
Where quick work is desired and expense is no item the pressure cooker
is advisable; where money is scarce and time is no object the homemade
outfit answers. Each one must decide which outfit is best for her own
particular case. It matters not which outfit you have--they have all
been thoroughly tested and approved by experts. Each one does the
work.

This equipment for canning should be in all kitchens: four-quart
kettle for blanching; steamer for steaming greens; colander; quart
measure; funnel; good rubber rings; sharp paring knives; jar opener;
wire basket and a piece of cheesecloth one yard square for blanching;
pineapple scissors; one large preserving spoon; one tablespoon; one
teaspoon; one set of measuring spoons; measuring cup; jar lifter;
either a rack for several jars or individual jar holders; and a clock.

The manufacturers, realizing that boys and girls must be kept busy
during the vacation months, have made some wonderful devices for
outdoor canning. Would it not be a good plan to buy one for the young
people of your family and give them something definite and worth while
to do in summer? You know little brains and hands must be kept
busy--if not usefully employed they are often inclined to mischief.
This type of cooker furnishes its own heat; so it can be used in the
back yard, in the orchard or under the trees in the front yard.

Remember that the higher the altitude the lower the degree of heat
required to boil water. Time-tables given in instructions for canning
are usually based upon the requirements of an altitude of 500 feet
above sea level. Generally speaking, for every 4000-foot increase in
altitude it will be well to add twenty per cent to the time required
as given in recipes or time schedules for the canning of all kinds of
fruits, vegetables, greens and meats.

CHAPTER II

SOFT FRUITS AND BERRIES

Having decided on your canning outfit, whether you are going to can in
boiling water, in a condensed steam cooker, or in steam under
pressure; having gathered together the necessary tools, such as
spoons, knives and a funnel; having raided the storeroom and collected
some jars, you are now ready for the actual work of canning.

It is rather unfortunate that strawberries should be one of the very
hardest products to can with good results. The canning itself is
simple--all berries are quickly and easily canned--but strawberries
always shrink, are apt to turn a little brown, and, what distresses us
most of all, they float to the top of the jar.

The berry's tendency to shrink is responsible for loss of color as
well as its floating qualities. However, if you will be exceedingly
careful to remove the berries from the canner the minute the clock
says the sterilizing period is over, you will have a fairly good
product. Two minutes too long will produce a very dark, shrunken
berry. So be careful of the cooking time. Another thing that makes a
good-looking jar is to pack a quart of berries--all kinds of berries,
not merely strawberries--into a pint jar. If you will get that many in
you will have a much better-looking jar, with very little liquid at
the bottom. It does not hurt the berries at all to gently press down
on them with a silver spoon while you are packing them into the jar.

We know we are going to get a quart of berries into every pint jar,
so we know just how many quarts of berries we will need to fill the
necessary jars for the next winter's use.

The first thing to do is to test each jar to see that there are no
cracks, no rough edges to cut the rubber, and to see whether the cover
and clamp fit tightly, if a clamp type of jar is used. The bail that
clamps down the glass tops should go down with a good spring. If it
does not, remove the bail and bend it into shape by taking it in both
hands and pressing down in the middle with both thumbs. Do not bend it
too hard, for if it goes down with too much of a snap it will break
the jar. This testing of the bails should be done every year. The
bails on new jars are sometimes too tight, in which case remove the
bail and spread it out. After the bail has been readjusted, test it
again. The chances are it will be just right. Of course all this
testing takes time, but it pays.

If you are using some old Mason jars put a rubber on each jar, fill
the jar with hot water, and then put the cover on tight and invert.
This is a sure test for leakage. Never use a Mason cap twice unless
the cover and collar are separate so that both can be completely
sterilized. Fortunately the old-fashioned Mason jar metal cover to
which a porcelain cap is fastened is going out of style.

If you still have some of these old covers it will be economy to throw
them away. You will be money ahead in the end. After these tops have
been used once it is impossible to make a fastening between the
porcelain and the metal so tight that it is not possible for the
liquid to seep through and cause the contents to spoil. This accounts
for many failures when old tops are used. For this reason never use
the old-fashioned, zinc-topped covers.

The new and safe Mason jar covers consist of two parts, the metal
collar and the porcelain cap. They are for sale at all grocery or
hardware stores.

If you are using the vacuum-seal jars which have a composition
attached to the lacquered tops, carefully examine this rubber
composition to see that it is perfect. This composition should go
entirely round the top and should not be cut or broken in any place.
If it is the top must be discarded for a perfect one.

Of course with this type of jar no rubber rings are necessary, as the
rubber composition on the lacquered top does the sealing.

It is a wise plan to go round the tops and over the inside of all new
glass jars with a heavy and dull knife to scrape off any slivers of
glass or bursted blisters that may be still clinging to the jars.
Those on the tops cut through the rubber and cause leakage. Those in
the jars may get into the product. I often find these splinters,
particularly on new straight-sided jars.

It matters not what type of jar you use. Use what you have at hand,
but if you are buying new jars consider the following things before
making your selections: No metal, unless it is enameled or lacquered,
should come in contact with the food. The jars should be of smooth,
well-finished glass. The color of the jar does not affect the keeping
qualities of the food. The top or part of the top that comes in
contact with the contents should be all in one piece, so as not to
offer a place for the accumulation of organisms and dirt. The jars
which have nearly straight sides and a wide mouth or opening are
easier to wash and facilitate better, quicker and easier packing of
the product.

Wash the jars in soap and water. Rinse in boiling water. Some people
temper new jars so they will stand the shock of hot water or hot sirup
without breaking. If you wish to take this extra precaution put the
jars in a dishpan or kettle of cold water after they have been washed
in soapy water; bring the water slowly to a boil and let it boil
fifteen minutes. After the jars are ready test the rubber rings. This
may seem a useless precaution, but it is a necessary one, for there is
no one detail in the business of canning that is more important. Even
in the best boxes of rubbers there is occasionally a black sheep, and
one black sheep may cause the loss of a jar.

Test each rubber before you use it by pressing it firmly between the
thumbs and forefingers, stretching it very slightly. If it seems soft
and spongy discard it. All rubbers fit for canning should be firm,
elastic, and should endure a stretching pull without breaking. A good
rubber ring will return promptly to place without changing the inside
diameter.

A great many women are laboring under the wrong impression that color
affects the quality of a ring. Some women insist on red, and others on
white. Color is given to rings by adding coloring matter during the
manufacturing process. The color of the ring is no index to its
usefulness in home canning.

Use only fresh, sound strawberries or other berries. There is a little
knack about preparing the strawberries that few housewives know. Hull
the berries by _twisting the berries off the hull_, instead of pulling
the hull from the berry as most women do. You will have a
better-looking berry if you will be careful about this. Place the
berries in a strainer and pour cold water over them to cleanse them.

HOW TO ADJUST THE COVERS

Never allow the berries or any fruit to stand in water, as the flavor
and color are destroyed by water-soaking. Pack in glass jars, pressing
the berries down tightly, but without crushing them. Put the rubber on
the jar if you are using a jar requiring a rubber. Pour hot sirup over
the berries. Put the top of the jar in place, but only partially
tighten it.

If using the screw-top jars, such as the Mason, screw down with the
thumb and little finger, not using force but stopping when the cover
catches.

If using vacuum-seal jars put the cover on and the spring in place.
The spring will give enough to allow the steam to escape.

In using glass-top jars with the patent wire snap, put the cover in
place, the wire over the top and leave the clamp up.

The cover on a glass jar must not be tight while the product is
cooking, because the air will expand when heated, and if the cover is
not loose enough to allow the steam to escape the pressure may blow
the rubber out or break the jar.

The product is now ready for the canner.

STERILIZING

If you are using the homemade outfit, such as wash-boiler or garbage
pail, all berries and soft fruits are sterilized sixteen minutes; in
all commercial hot-water-bath outfits and in condensed steam, sixteen
minutes; in the water-seal, twelve minutes; in the steam pressure
under five pounds of steam, ten minutes; and in the pressure cooker
under ten pounds of steam, five minutes. Do not allow the pressure to
run above ten pounds for soft fruits; fifteen pounds makes them mushy.

If you use any type of hot-water-bath outfit be sure the water is
boiling when the fruit is lowered into the canner, and _keep it
boiling_ vigorously for the entire sixteen minutes. At the end of the
sterilizing time, _immediately_ remove the jars from the canner.

In taking canned goods from boiling water care is needed to see that
they are protected from drafts. If necessary close the windows and
doors while lifting the jars out, as a sudden draft might break them.

Examine rubbers to see that they are in place. Sometimes if a cover is
screwed down too tight the pressure of the steam from the inside
causes the rubber to bulge out. Simply loosen the cover a thread or
two, push the rubber back into place and then tighten.

In case the rubber does not seem to fit well or seems to be a poor
rubber it should be replaced by a new one, and the jar returned to the
cooker for five minutes.

The jars should be sealed tight--covers screwed down, clamps put in
place--immediately after they are removed from the cooker.

Invert the jar to test the joint, then let it cool. If the seal is not
perfect correct the fault and return the jar to the cooker for five
minutes if hot, ten minutes if the jar is cold.

Do not invert vacuum-seal jars. These should be allowed to cool, and
then be tested by removing the spring or clamp and lifting the jars by
the cover only. Lift the jar only half an inch, holding it over the
table, so that in case the lid does not hold the jar and contents will
not be damaged. Or, better still, tap round the edge of the cover with
a rule. An imperfect seal will give a hollow sound.

As light injures delicately colored fruits and vegetables, it is wise
to store them in dark places, such as cupboards, or basement or attic
shelves protected from the light. Black cambric tacked to the top
shelf and suspended over the other shelves is a sufficient protection
from light. A discarded window shade can be rolled down over the
shelves and easily pulled up when you desire to take a jar from the
shelves.

Canned goods are best kept at a temperature below seventy degrees
Fahrenheit, where that is at all possible.

STEPS IN CANNING SOFT FRUITS AND BERRIES

It might be well to enumerate the steps in berry and soft-fruit
canning, or do what we called in our schooldays "review it":

1. Get the canner and all its accessories ready.

2. Test and wash jars and tops and put in water to sterilize.

3. Test rubber rings.

4. Make sirup and put in double boiler to keep hot

5. Prepare the product--hull, seed, stem.

6. Place berries or fruit in strainer or colander.

7. Rinse by pouring cold water over product.

8. Pack from strainer into hot jar.

9. Use big spoon to get a firm pack.

10. Dip rubber in hot water to cleanse it and put it in place on the
jar.

11. Pour the hot sirup over the fruit at once.

12. Put top of jar on, but not tight.

13. Ready for canner.

14. Sterilize for the necessary length of time, according to the
outfit you are using:

                                    MINUTES

  Hot-water-bath outfit                16
  Condensed-steam outfit               16
  Water-seal outfit                    12
  Steam pressure, 5 pounds, outfit     10
  Pressure cooker, 10 pounds, outfit    5

15. Remove from canner.

16. Tighten cover, except vacuum-seal jar, which seals automatically.

17. Test joint.

18. Three or four days later, if perfectly air-tight, label and store
in a dark place.

These steps are followed for strawberries, blackberries, blueberries,
dewberries, huckleberries, gooseberries, raspberries, and for all soft
fruits, such as cherries, currants, grapes and figs.

The other soft fruits, such as peaches and apricots, which have a
skin, are scalded or "hot dipped" for one to two minutes in boiling
water or steam and are then plunged into cold water. These two steps
of hot-dipping and cold dipping make the removal of skins a very
simple operation. After the skins are removed the fruit is put into
the hot jars and the process continued from Step 8, as with
strawberries.

SIRUPS

Of course you are wondering about the sirups for the different fruits.
There is no set rule for making sirup. It is not necessary to use
sirup in canning fruits. The amount of sugar used in the sirup will
depend upon the individual taste. In a first-class product there
should be enough sirup to improve its flavor, but not enough to make
it take the place in the diet of a sweet preserve rather than a fresh
fruit.

The sirups are made either with varying proportions of sugar and water
or with the same proportions boiled different lengths of time. What is
known as the California sirup is made with three parts of sugar to two
parts of water, boiled gently to different concentrations.

Thin Sirup. For a thin sirup take three cups of sugar and two cups
of water. Mix sugar and heat until the sugar is dissolved. This is
used for all sweet fruits not too delicate in texture and color, as
apples, cherries, pears, or for fruits in which more sugar will be
added in preparation for the table.

Medium Thin Sirup. The sugar and water should be boiled about four
minutes, or until it begins to be sirupy. This is used for
raspberries, peaches, blackberries, currants, etc.

Medium Thick Sirup. Boil the sugar and water until it will pile up
over the edge of the spoon when it is tipped. This is used for sour or
acid fruits, as plums, gooseberries, apricots, sour apples, and some
of the delicately colored fruits, as strawberries.

Thick Sirup. The sugar and water are boiled until it will form a
ball in the spoon and cannot be poured from the spoon. This is used
for preserves.

It is possible to get more, sometimes almost twice as much, sirup
into a quart jar containing large fruits, as apples and pears, than
into a quart jar containing small fruits, as currants or blackberries.

There is a little knack worth knowing about combining the sugar and
water for the sirup. If the sugar is sifted into the boiling water
just as fine-grained cereals are sifted into water, there will be no
scum formed. This is a saving of sugar.

If you wish to can strawberries for the market or to win a prize at
the county or state fairs, can them as follows:

Canned by this recipe, strawberries will not rise to the top of the
sirup. Use only fresh, ripe, firm and sound berries. Prepare them, and
add eight ounces of sugar and two tablespoonfuls of water to each
quart of berries. Boil slowly for fifteen minutes in an enameled or
acid-proof kettle. Allow the berries to cool and remain several hours
or over-night in the covered kettle. Pack the cold berries in hot
glass jars. Put rubbers and caps of jars in position, not tight.
Sterilize for the length of time given below for the type of outfit
used:

                                       MINUTES
  Water bath, homemade or commercial      8
  Water seal, 214 degrees                 6
  5 pounds steam pressure                 5
  10 pounds steam pressure.          Do not use.

Remove the jars, tighten the covers, invert the jars to cool and test
the joints. Wrap the jars with paper to prevent bleaching.

CHAPTER III

HARD FRUITS

PINEAPPLES

The object of canning citrus fruits is, first, to save the surplus and
by-products; second, to furnish wholesome fruits at reasonable cost to
more of our people; third, to help the producer to transform
by-products into net profits.

Almost every one likes canned pineapple, but some housewives stopped
canning this fruit because they found that when cooked in sirup it
seemed to get tough and less palatable. Vegetable and fruit fibers are
toughened when cooked with sugar for any length of time, so in all
cases where you desire to keep the product as Nature grew it avoid
this form of cooking.

When the product is put into the jars with a sirup and cooked in the
jar you will have a product superior to the one that is cooked over
the direct fire in the kettle with the sirup.

But pineapple slices or pieces are so hard they cannot be put directly
into the jars as berries are. Pineapples must undergo a preliminary
process to make them palatable and soft. This preliminary process is
known in canning as "blanching."

After the pineapple has been prepared by paring and removing the eyes,
it can be left in slices or cut into cubes. In cutting hold the
pineapple at the top and use a sharp knife. It is then placed in a
wire basket or a piece of cheesecloth for the blanching. Blanching
means to immerse the product in boiling water for a certain length of
time to reduce its bulk and soften it.

Pineapples are blanched for five minutes. We scald peaches and
apricots, which are soft fruits; but we blanch pineapples, apples and
quinces, the hard fruits.

Scalding means to immerse the product in boiling water for a very
short time--just long enough to loosen the skins. Blanching is just a
longer period of scalding.

When you blanch pineapples use only enough water to cover them. This
same blanching water can be used for making the sirup. It contains
much of the pineapple flavor and there is no reason for discarding it.
But this is absolutely the only blanching water that is ever used. All
other blanching water, particularly that in which vegetables are
blanched, is full of objectionable acids that we want to get rid of,
so under no circumstances must it be used. But with pineapples the
object of blanching is primarily to soften the hard fiber, so there is
no objection to using the blanching water.

After the pineapple has been in the covered kettle of boiling water
for five minutes, it is held under cold water until cool enough to
handle. Never let it soak in cold water, as that will impair its
delicate flavor. After this it is packed into hot sterilized jars.
Rubber rings are put on the jars, the covers are put in place--not
tight--and the jars are put in the canner.

Pineapple is sterilized for thirty minutes in a hot-water-bath outfit;
thirty minutes in a condensed steam outfit; twenty-five minutes in the
water-seal; twenty-five minutes in the steam pressure under five
pounds of steam, and eighteen minutes in the pressure cooker under ten
pounds of pressure. At the end of the sterilizing period the jars are
removed, the covers completely tightened and the joints carefully
tested for leakage.

A thin or medium-thin sirup is best for pineapples. Measure the
blanching water and to every two cups of it add three cups of sugar.
If you wish the sirup thin heat until the sugar is dissolved. If
medium-thin sirup is desired, boil it about four minutes or until it
begins to be sirupy.

STEPS IN CANNING PINEAPPLE

1. Cut the pineapple into slices of desired thickness.

2. Pare the slices. It is easier to pare the slices than to pare the
whole pineapple.

3. Remove the eyes, using pineapple scissors to facilitate the work.

4. Blanch pineapple for five minutes in a small amount of boiling
water, using a wire basket or cheesecloth.

5. Cold-dip the pineapple.

6. Make a sirup, using the blanching water. Make a thin or medium-thin
sirup.

7. Pack the pineapple into hot sterilized jars, with good rubbers on
them.

8. Pour the sirup over the pineapple.

9. Put the tops of the jars on--not tight.

10. Sterilize for 30 minutes in hot-water-bath outfit, 30 minutes in
condensed-steam outfit, 25 minutes in water-seal outfit, 25 minutes in
steam pressure (5 pounds), 18 minutes in pressure cooker (10 pounds).

11. Remove from canner, tighten covers and inspect rubber and joints.

APPLES

Here are six ways in which canned apples may be used: as a breakfast
dish, with cream and sugar; baked like fresh apples; in apple salad,
often served for lunch or supper; as a relish with roast pork--the
apples may be fried in the pork fat or the cores may be cooked with
roast pork for flavoring; and for apple dumplings, deep apple pie and
other desserts in which whole apples are desirable. The sirup of
canned whole apples can be used for pudding sauces or fruit drinks.

Apples are another hard fruit which require blanching, as it greatly
improves their texture and appearance.

Apples and some other fruits, such as pears and quinces, have a
tendency to turn brown when allowed to stand after they are cut. To
prevent their discoloring the pieces may be dropped into mild salt
water as they are pared and sliced. Let them stand for five minutes,
then wash them in clear water and pack. Use a thin sirup for canning
apples.

Summer apples are not firm enough to keep well when canned. They cook
up and lose flavor. They may, however, be canned to be used in a short
time. Windfall apples may be pared, cored and sliced, using water, and
only a small quantity of that, instead of sirup, and canned for pies.

To be able to can windfall and cull apples and thus have them for home
use through the entire year is a great advantage to all farmers who
grow them. They can be sold on the market canned when they would not
bring a cent in the fresh state.

The windfall and cull apples may be divided into two grades. The
first grade would include the whole reasonably sound fruit; the second
grade the worm-eaten, partially decayed and injured fruit. Do not can
any injured or decayed part nor allow apples to become overripe before
canning.

Canning Whole Reasonably Firm Apples. Wash the apples. Remove cores
and blemishes. Place whole apples in blanching tray or blanching cloth
and blanch in boiling hot water for one or two minutes. Remove and
plunge quickly into cold water. Pack in large glass jars. Pour over
the product a hot thin sirup. Place rubber and top in position. Seal
partially--not tight.

Sterilize jars twenty minutes in hot-water-bath outfit and in
condensed steam, fifteen minutes in water-seal, ten minutes in
steam-pressure outfit with five pounds of steam pressure, five minutes
in aluminum pressure-cooker outfit, under ten pounds of steam
pressure. Remove jars, tighten covers, invert to cool and test joints.

Firm and tart apples may be cored and peeled first, then canned by the
above recipe.

Canning Apples for Pie Filling. Use second grade of windfalls or
culls. Wash, core, pare and remove all decayed spots. Slice apple
quickly into a basin containing slightly salted cold water--about one
tablespoon of salt per gallon--to prevent discoloring. Pack fresh cold
product in glass jars. Add one cupful of hot thin sirup to each quart
of fruit. Put on the rubbers and screw on tops, but do not seal
completely. Sterilize twelve minutes in hot-water bath or
condensed-steam outfit; ten minutes in water-seal outfit; six minutes
under five pounds of steam pressure; four minutes in aluminum
pressure cooker. Remove jars, tighten covers, invert to cool and test
joint. Store.

This filling can be used for making apple pies in the same way that
fresh apples would be used, with the exception that the sirup must be
poured off and less sugar should be used. Since the apples have
already been cooked, only enough heat is needed to cook the crust and
to warm the apples through. Pies may be baked in seven minutes. The
apple pies made with these apples are, in the opinion of many
housekeepers, as good as those made with fresh fruit, and they can be
made in less time and are less expensive.

The only difference between canning apples for pies and salads or
whole is that when wanted for pies the apples should be sliced
immediately after placing in cold slightly salted water.

Canning Quartered Apples for Fruit Salads. Select best-grade culls
of firm and rather tart varieties. Core, pare and quarter. Drop into
basin containing slightly salted cold water. Pack these quartered
pieces tightly in jars. Add a cup of hot thin sirup to each quart.
Place rubber and top in position, partially seal--not tight. Sterilize
twelve minutes in hot-water bath and condensed-steam outfits; ten
minutes in water-seal outfit; six minutes under five pounds of steam
pressure; four minutes in aluminum pressure cooker. Remove jars,
tighten covers, invert to cool and test joints. Store.

ORANGES

Canning Whole Oranges and Other Citrus Fruits. Select windfall or
packing-plant culls. Use no unsound or decayed fruit. Remove skin and
white fiber on surface. Blanch fruit in boiling water one and a half
minutes. Dip quickly in cold water. Pack containers full. Add boiling
hot thin sirup. Place rubber and cap in position and partially
seal--not tight.

Sterilize twelve minutes in hot-water-bath and condensed-steam
outfits; eight minutes in water-seal outfit; six minutes in
steam-pressure outfit under five pounds of steam; four minutes in
aluminum pressure-cooker outfit. Remove jars, tighten covers, invert
to cool and test joints. Wrap glass jars with paper to prevent
bleaching, and store.

Canning Sliced Oranges for Salad Purposes. The oranges may be
divided into their natural sections or sliced with a knife. Pack jars
or containers full. Pour over product hot thin sirup. Place rubber and
cap in position. Partially seal--not tight. Sterilize ten minutes in
hot-water-bath and condensed-steam outfits; six minutes in water-seal
outfit; five minutes in steam-pressure outfit with five pounds of
steam; four minutes in aluminum pressure-cooker outfit under ten
pounds of steam. Remove jars, tighten covers, invert to cool and test
the joints. Wrap jars with paper to prevent bleaching, and store.

PEARS, QUINCES AND RHUBARB

Pears are prepared and canned just as the whole firm apples are, being
blanched a minute and a half, cold-dipped and sterilized for the same
length of time as apples.

Quinces are so very hard they must be blanched like pineapples, but
for a longer time. Six minutes' blanching is usually sufficient for
quinces. The sterilizing period can be determined by looking at the
chart.

If skins are left on rhubarb it keeps its pink color. The hot dip is
not necessary and may be omitted. It removes some of the excessive
acid in the rhubarb which makes it objectionable to some people. Be
very careful not to hot-dip the rhubarb more than one minute, for it
gets mushy. An advantage of the hot dip is that more rhubarb can be
packed in a jar after it has been hot-dipped.

WHAT A BUSHEL OF FRUIT WILL YIELD

A great many women have no conception of how many jars of fruit they
will get from a bushel or half bushel of produce. It is wise to have a
little knowledge along this line, for it aids in planning the winter's
supply of canned goods as well as at marketing time.

From one bushel of the various fruits you will get on the average the
following:

   PRODUCTS, 1 BUSHEL                 PINT JARS    QUART JARS

  Windfall apples                         30         20

  Standard peaches                        25         18

  Pears                                   45         30

  Plums                                   45         30

  Berries                                 50         30

  Windfall oranges--sliced                22         15

  Windfall oranges--whole                 35         22

CANNING WITHOUT SUGAR

Though all instructions indicate that sugar is necessary for the
canning of all kinds of fruits, it is not necessary for their proper
sterilization and preservation. Any fruit may be successfully
sterilized by simply adding boiling water instead of the hot sirup. It
is a well-known fact, however, that most fruits canned in water will
not retain so well their natural flavor, texture and color as fruit
canned in sirup. When the product is to be used for pies, salads, and
so on it is not necessary to can in sirup. When fruits canned in water
are to be used for sauces, the products should be sweetened before
use. In many instances it requires more sugar to sweeten a sauce after
canning than it does when the product is canned in the hot sirup.

However, during the World War we had a good chance to test the fruits
which we canned without sugar, when that commodity was scarce and, in
fact, impossible to get in very large quantities. We used our fruits
just as they were and considered them very good. This all goes to show
that we can easily adjust ourselves to prevailing conditions. In
canning without the sugar sirup, you would follow these directions:

Cull, stem or seed, and clean fruit by placing in a strainer and
pouring water over it until clean. Pack product thoroughly in glass
jars until full; use table knife or tablespoon for packing purposes.
Pour over the fruit boiling water from kettle, place rubbers and caps
in position, partially seal glass jars and place produce in canner.

If using hot-water-bath outfit sterilize from twenty to thirty
minutes. After sterilizing remove packs, seal glass jars, wrap in
paper to prevent bleaching, and store in a dry cool place.

When using a steam-pressure canner instead of the hot-water bath
sterilize for ten minutes with five pounds of steam pressure. Never
allow the pressure to go over ten pounds when you are canning soft
fruits.

WHEN TO CAN

Inexperienced canners may not know when certain fruits are in season
and at their prime for canning. The list below is necessarily subject
to change, as seasons vary from year to year; but in normal years this
table would hold true for the Northern States.

  Apples             September
  Apricots           August
  Blackberries       August
  Cherries           July
  Currants           July
  Gooseberries       July
  Grapes             September
  Huckleberries      July
  Peaches            August-September
  Pears              September
  Pineapple          June
  Plums              August
  Quinces            September
  Raspberries        July
  Rhubarb            All summer
  Strawberries       May-June

For your canning you will need as your guide the charts on the pages
which follow. They are very simple and will tell you how to prepare
all the various fruits, whether or not they are to be blanched, and if
so exactly how many minutes, and how long to cook or sterilize the
products, according to the outfit you are using.

CHART FOR CANNING SOFT FRUITS AND BERRIES

[A] NUMBER OF MINUTES TO BLANCH OR HOT-DIP
[B] IN HOT WATER BATH OUTFIT AT 212°F
[C] IN CONDENSED STEAM OUTFIT
[D] IN WATER-SEAL OUTFIT 214°F
[E] IN STEAM PRESSURE 5 TO 10 POUNDS
[F] IN PRESSURE COOKER 10 POUNDS

                       NUMBER OF MINUTES TO STERILIZE
  KIND OF            | [A]  |[B] |[C] |[D] |[E] |[F] |REMARKS
  FRUIT/PREPARATION  |      |    |    |    |    |    |
  --------------------------------------------------------------------
  APRICOTS: To remove|1 to 2| 16 | 16 | 12 | 10 | 5  |Use
  skins hot-dip and  |      |    |    |    |    |    |medium-thick
  cold-dip. Can be   |      |    |    |    |    |    |sirup
  canned with the    |      |    |    |    |    |    |
  skins. Pits give a |      |    |    |    |    |    |
  good flavor        |      |    |    |    |    |    |
                     |      |    |    |    |    |    |
  BLACKBERRIES: Pick | None | 16 | 16 | 12 | 10 | 5  |Use medium-thin
  over, wash and stem|      |    |    |    |    |    |sirup
                     |      |    |    |    |    |    |
  BLUEBERRIES: Pick  | None | 16 | 16 | 12 | 10 | 5  |Use medium-thin
  over, wash and stem|      |    |    |    |    |    |sirup
                     |      |    |    |    |    |    |
  CHERRIES: Wash,    | None | 16 | 16 | 12 | 10 | 5  |Use medium-thin
  remove stems, and  |      |    |    |    |    |    |sirup if sour;
  remove pits if     |      |    |    |    |    |    |thin sirup if
  desired. If pitted |      |    |    |    |    |    |sweet
  save the juice     |      |    |    |    |    |    |
                     |      |    |    |    |    |    |
  CURRANTS: Wash and | None | 16 | 16 | 12 | 10 | 5  |Use medium-thin
  pick from stems    |      |    |    |    |    |    |sirup
                     |      |    |    |    |    |    |
  CRANBERRIES: Wash  | None | 16 | 16 | 12 | 10 | 5  |Use medium-thin
  and stem           |      |    |    |    |    |    |sirup
                     |      |    |    |    |    |    |
  DEWBERRIES: Wash   | None | 16 | 16 | 12 | 10 | 5  |Use medium-thin
  and stem           |      |    |    |    |    |    |sirup
                     |      |    |    |    |    |    |
  FIGS: Wash and stem| None | 16 | 16 | 12 | 10 | 5  |Figs can be
                     |      |    |    |    |    |    |hot- dipped for
                     |      |    |    |    |    |    |a minute or two
                     |      |    |    |    |    |    |if desired.
                     |      |    |    |    |    |    |Hot-dipping
                     |      |    |    |    |    |    |shrinks the
                     |      |    |    |    |    |    |figs so more
                     |      |    |    |    |    |    |can be packed
                     |      |    |    |    |    |    |in a jar
                     |      |    |    |    |    |    |
  GOOSEBERRIES Wash  | None | 16 | 16 | 12 | 10 | 5  |Use
  and snip off stems |      |    |    |    |    |    |medium-thick
  and blossom ends   |      |    |    |    |    |    |sirup
                     |      |    |    |    |    |    |
  GRAPES Wash and    | None | 16 | 16 | 12 | 10 | 5  |Use medium-thin
  pick from stems    |      |    |    |    |    |    |sirup
                     |      |    |    |    |    |    |
  HUCKLEBERRIES Wash | None | 16 | 16 | 12 | 10 | 5  |Use medium-thin
  and stem           |      |    |    |    |    |    |sirup
                     |      |    |    |    |    |    |
  PEACHES Blanch and | 1-2  | 16 | 16 | 12 |*10 | X  |*Use only 5
  cold-dip, then     |      |    |    |    |    |    |pounds
  remove skins.      |      |    |    |    |    |    |pressure. If
                     |      |    |    |    |    |    |peaches are
                     |      |    |    |    |    |    |canned under
                     |      |    |    |    |    |    |more than 5
                     |      |    |    |    |    |    |pounds of
                     |      |    |    |    |    |    |pressure they
                     |      |    |    |    |    |    |become
                     |      |    |    |    |    |    |flavorless and
                     |      |    |    |    |    |    |
  PLUMS Wash; stones | 1-2  | 16 | 16 | 12 | 10 | 5  |For sweet plums
  may be removed if  |      |    |    |    |    |    |use thin or
  desired.           |      |    |    |    |    |    |medium-thin
                     |      |    |    |    |    |    |sirup; for sour
                     |      |    |    |    |    |    |plums use
                     |      |    |    |    |    |    |medium-thin
                     |      |    |    |    |    |    |sirup
                     |      |    |    |    |    |    |
  RASPBERRIES pick   | None | 16 | 16 | 12 | 10 | 5  |Use medium-thin
  over, wash and stem|      |    |    |    |    |    |sirup
                     |      |    |    |    |    |    |
  RHUBARB Wash, cut  |  1   | 16 | 16 | 12 | 10 | 5  |Be very careful
  into ½ inch pieces.|      |    |    |    |    |    |not to hot-dip
  Use sharp knife    |      |    |    |    |    |    |the rhubarb
                     |      |    |    |    |    |    |more than one
                     |      |    |    |    |    |    |minute, for it
                     |      |    |    |    |    |    |gets mushy
                     |      |    |    |    |    |    |
  STRAWBERRIES Pick  | None | 16 | 16 | 12 | 10 | 5  |Use
  over, wash and hull|      |    |    |    |    |    |medium-thick
                     |      |    |    |    |    |    |sirup
  --------------------------------------------------------------------
  HARD FRUITS        |      |    |    |    |    |    |
  --------------------------------------------------------------------
                     |      |    |    |    |    |    |
  APPLES Pare, core  |1½ to | 20 | 20 | 15 | 10 | 5  |Use thin sirup
  and cut into halves|  2   |    |    |    |    |    |
  or smaller pieces  |      |    |    |    |    |    |
                     |      |    |    |    |    |    |
  PEARS Wash, pare or|  1½  | 20 | 20 | 15 | 10 | 5  |Use thin sirup
  not as desired.    |      |    |    |    |    |    |
  Small pears may be |      |    |    |    |    |    |
  canned whole or    |      |    |    |    |    |    |
  quartered          |      |    |    |    |    |    |
                     |      |    |    |    |    |    |
  PINEAPPLE Cut into |  5   | 30 | 30 | 25 | 25 | 18 |Use thin or
  slices or inch     |      |    |    |    |    |    |medium-thin
  cubes. The cores   |      |    |    |    |    |    |sirup
  can be removed     |      |    |    |    |    |    |
                     |      |    |    |    |    |    |
  QUINCES Remove     |  6   | 40 | 40 | 30 | 25 | 20 |Apples, pears
  skins and cores.   |      |    |    |    |    |    |and quinces
  Cut into convenient|      |    |    |    |    |    |should be
  slices             |      |    |    |    |    |    |dropped into
                     |      |    |    |    |    |    |salt water to
                     |      |    |    |    |    |    |keep fruit from
                     |      |    |    |    |    |    |turning brown.
                     |      |    |    |    |    |    |Use salt in the
                     |      |    |    |    |    |    |proportion of
                     |      |    |    |    |    |    |one
                     |      |    |    |    |    |    |tablespoonful
  WINDFALL APPLES FOR|      |    |    |    |    |    |to one gallon
                     |      |    |    |    |    |    |of water. Use
                     |      |    |    |    |    |    |thin
                     |      |    |    |    |    |    |
  PIE FILLING Cut    | None | 12 | 12 | 10 | 6  | 4  |Can in water
  into halves        |      |    |    |    |    |    |
                     |      |    |    |    |    |    |
  QUARTERED APPLES   | None | 12 | 12 | 10 | 6  | 4  |Can in water
  FOR SALAD          |      |    |    |    |    |    |and save the
                     |      |    |    |    |    |    |sugar for other
                     |      |    |    |    |    |    |purposes
                     |      |    |    |    |    |    |
  CRAB APPLES Pare   | None | 16 | 16 | 8  | 5  | 5  |Can in water or
  and core           |      |    |    |    |    |    |use thin sirup
                     |      |    |    |    |    |    |
  --------------------------------------------------------------------
  CITRUS FRUITS      |      |    |    |    |    |    |
  --------------------------------------------------------------------
  ORANGES, WHOLE     |  1½  | 12 | 12 | 8  | 6  | 4  |Add boiling
  Remove skins and   |      |    |    |    |    |    |thin sirup
  white fiber or     |      |    |    |    |    |    |
  surface, then      |      |    |    |    |    |    |
  blanch             |      |    |    |    |    |    |
                     |      |    |    |    |    |    |
  LEMONS, WHOLE      |  1½  | 12 | 12 | 8  | 6  | 4  |Add boiling
  Remove skins and   |      |    |    |    |    |    |thin sirup
  white fiber or     |      |    |    |    |    |    |
  surface, then      |      |    |    |    |    |    |
  blanch             |      |    |    |    |    |    |
                     |      |    |    |    |    |    |
  GRAPEFRUIT, WHOLE  |  1½  | 12 | 12 | 8  | 6  | 4  |Add boiling
  Remove skins and   |      |    |    |    |    |    |thin sirup
  white fiber or     |      |    |    |    |    |    |
  surface, then      |      |    |    |    |    |    |
  blanch             |      |    |    |    |    |    |
                     |      |    |    |    |    |    |
  ORANGE AND OTHER   | None | 10 | 10 | 6  | 5  | 4  |Use thin sirup
  CITRUS FRUITS,     |      |    |    |    |    |    |
  SLICED Slice with a|      |    |    |    |    |    |
  sharp knife        |      |    |    |    |    |    |
                     |      |    |    |    |    |    |
  FRUITS CANNED IN   |  30  | 30 | 20 | 12 | 10 |    |
  WATER WITHOUT SUGAR|      |    |    |    |    |    |
  SIRUP              |      |    |    |    |    |    |
                     |      |    |    |    |    |    |
  --------------------------------------------------------------------

NOTE.--When cooking products in pint or half-pint jars deduct three or
four minutes from the time given above. When cooking in two-quart jars
add 3 or 4 minutes to time. The estimates given are for quart jars.

CHAPTER IV

VEGETABLES

It is practical to can all vegetables, even such difficult ones as
corn, peas and beans, by the cold-pack method of canning without using
any preservatives, if you will follow all directions, instructions and
the time-table accurately. Vegetable canning is a little more
complicated than fruit canning.

TOMATOES

Every one likes canned tomatoes. In many homes more tomatoes are
canned than any other product. The housewife uses them for soups, for
sauces and for seasoning many meat dishes. Some women say: "I can
preserve everything but tomatoes. They always spoil. What do I do
wrong?" If the following directions are followed tomatoes will not
spoil.

Tomatoes really are the easiest vegetable to can, because the period
of sterilization is short, and many jars may be canned in a day, or if
one is very busy a few jars may be canned daily without the
expenditure of a great deal of time.

The best tomatoes for canning are those of moderate size, smooth and
uniformly ripe. When a tomato ripens unevenly or when it is misshapen,
it is difficult to peel, and the percentage of waste is high. Tomatoes
should not be picked when they are green or partly ripe, for the
flavor will not be so good as when they are allowed to remain upon
the vines until fully ripe. Care should be taken, however, not to
allow them to become overripe before canning.

In no instance should a tomato with a rotten spot be canned, even
though the spot is cut out, for the occasional spoiled jar resulting
from this attempted saving will cost more than the partly spoiled
tomatoes are worth. If the housewife will can only uniformly ripe,
sound tomatoes, saving the small, uneven but sound fruit for tomato
_purée_, she will have a much better-looking pack and greater food
value at the close of the season. Yellow tomatoes may be canned in the
same manner as are the more common red varieties, except that it is
not necessary to remove the cores.

First of all, grade for ripeness, size and quality; this is to insure
a high-grade product. We could, of course, can different sizes and
shades together, but uniform products are more pleasing to the eye and
will sterilize much more evenly. If the products are of the same
ripeness and quality, the entire pack will receive the proper degree
of cooking.

Wash the tomatoes. Have ready a kettle of boiling water. Put the
tomatoes in a wire basket, or lay them on a piece of cheesecloth or a
towel, twist the ends together to form a sack, and let this down into
the kettle. It is a good plan to slip a rubber band round the neck of
this sack to hold the ends in place. The ends should be long enough to
stand up out of the water and so avoid danger of burning the fingers
when removing the product.

Have the water boiling hard. Lower the tomatoes into the boiling
water. This is called scalding the tomatoes. We scald the tomatoes to
loosen the skin. If the tomatoes are very ripe, one minute scalding
will be sufficient. The average length of time for tomatoes, just
perfect for canning, is one and a half minutes. Do not leave the
tomatoes in the hot water until the skins break, as this gives them a
fuzzy appearance.

The scalding kettle always should be covered, to keep in all the heat
possible. Begin to time from the minute the product is immersed in the
boiling water. If you wait until the water comes back to a boil, you
will scald the product too long and have mushy tomatoes.

Lift the tomatoes out of the hot water and plunge them immediately
into cold water, or hold them under the cold-water faucet. The
cold-dip makes them easier to handle, separates the skin from the
pulp, firms the texture, and coagulates the coloring matter so it
stays near the surface, giving them a rich, red color. Then the shock
due to the sudden change from hot to cold and back to hot again seems
to help kill the spores. Do not let the product stand in the cold-dip.
The water becomes lukewarm, softens the product and allows bacteria to
develop.

Take the tomato in the left hand and with a sharp knife cut out the
core. Be careful not to cut into the fleshy portion or seed cells, for
this will scatter the seeds and pulp through the liquid, injuring the
appearance of the product. Cut out the core before removing the skin,
for the skin will protect the pulp and there will be less danger of
breaking the tomato. If the tomatoes are ripe and have been scalded
properly, the skin can be slipped off with the fingers.

The jars, rubbers and tops should be ready. Glass jars should be hot,
so there will be no danger of breakage in setting them in the hot
water, and so they will not cool the water in the cooker below the
boiling point.

Pack the tomatoes whole, pressing and shaking them well down together,
but not using force enough to crush them.

Now we come to a point where tomatoes are different from most
vegetables. Beans, carrots, peas, and so on, have hot water added to
them. But as a large part of the tomato is water, no more is needed.
Another exception where no water is needed is with the "greens
family." So with tomatoes we add no water, but add one teaspoonful of
salt and one teaspoonful of sugar, just for seasoning, to every quart
jar. I think that tomatoes always are improved by the addition of a
little sugar, but this is not necessary and can be omitted, as also
can be the salt.

The salt in canning does not act as a preservative, but as seasoning;
so if for any reason you forget the salt, do not be alarmed. Your
products will keep perfectly without the salt.

THE WAY TO SEAL

The products are in the hot jars now. The jars do not need to be full
in order to keep. If you were canning by the "open-kettle" method, the
air in the partly filled jar would not have been sterilized, and might
contain the bacteria which cause the product to ferment or mold. But
by the cold pack, the air in the can is sterilized while the product
is being sterilized; and if the can is closed immediately after
cooking, a single spoonful may be canned in a two-quart jar and the
product will keep indefinitely.

Place Rubber and Cover on Jar. Fit the rubber. Use good rubbers and
see that they lie flat and fit close up to the can. Put the covers in
place.

Do Not Seal Glass Jars Tight. If using screw-top jars screw each
cover down until it catches, then turn a quarter of a round back; or
screw down with the thumb and little finger, not using force but
stopping when the cover catches.

If using vacuum-seal jars put the cover on and the spring in place.
The spring will give enough to allow the steam to escape.

If using glass-top jars, with the patent wire snap, put the cover in
place, the wire over the top and the clamp up.

The cover on a glass jar must not be tight while processing, because
the air will expand when heated, and if the cover is not loose enough
to allow the steam to escape, the pressure may blow the rubber out or
break the jar.

When canning in tin we cap and tip the cans at once. The tin will
bulge out, but is strong enough to withstand the pressure, and when
the contents cool the can will come back into shape.

The jars are now ready for the canner. Tomatoes sterilized under
boiling water require twenty-two minutes; in condensed-steam cooker,
twenty-two minutes; in water-seal, eighteen minutes; in
steam-pressure, with five pounds, fifteen minutes, and in the pressure
cooker, at ten or fifteen pounds, ten minutes.

If you use the homemade outfit or any water-bath outfit be sure the
water is boiling when the jars of tomatoes are lowered into the
canner. Time lost in bringing the contents to the point of
sterilization softens the tomatoes and results in inferior goods. Use
the ordinary good sense with which you have been endowed in handling
the jars and you will have no breakage. At the end of the sterilizing
period, remove the jars.

In taking canned goods from boiling hot water, care is needed to see
that they are protected from drafts. If necessary close the windows
and doors while lifting the jars out, for a sudden draft might break
them.

Examine rubbers to see that they are in place. Sometimes, if the
covers are screwed down too tight, the pressure of the steam from the
inside causes the rubber to bulge out. Simply loosen the cover a
thread or two, push the rubber back into place and then tighten. In
case the rubber does not seem to fit well or seems to be a poor
rubber, it should be replaced by a new one and the jar returned to the
cooker for five minutes.

The jars should be sealed tight--covers screwed down, clamps put in
place--immediately after they are removed from the cooker.

Invert to test the joint and cool. If the seal is not perfect, correct
the fault, and return the jar to the cooker for five minutes if hot,
ten minutes if jar is cold.

Do not invert vacuum-seal jars. These should be allowed to cool and
then tested by removing the spring or clamp and lifting the jars by
the cover only. Lift the jar only a half inch, holding it over the
table so that, in case the lid does not hold, the jar and contents
will not be damaged. Or, better still, tap round the edge of the
cover with a ruler. An imperfect seal will cause a hollow sound.

Tomato Purée. Small, misshapen, unevenly ripened tomatoes may be
converted into tomato _purée_. The tomatoes should be washed, run
through a colander to remove skins and cores, concentrated by cooking
to about half the original volume, and packed in the jars. Rubbers and
tops should then be placed in position and the product sterilized for
the same length of time as for canned tomatoes. _Purée_ even may be
kept in bottles sealed with sterilized corks and dipped several times
in paraffin.

HOW OTHER VEGETABLES ARE CANNED

All other vegetables are canned exactly like tomatoes, with two
exceptions. Tomatoes are scalded. All other vegetables are blanched.
We scald tomatoes to loosen the skins and to start the flow of the
coloring matter, which is later arrested or coagulated by the
cold-dip.

Blanching is scalding, only for a longer time. Scalding is never for
more than two minutes. Blanching covers from three to thirty minutes.

We blanch beans, peas, corn, cabbage, carrots, beets, turnips, and so
on, for three to ten minutes. We blanch these vegetables to eliminate
any objectionable acids or bitter flavors which may be present, and
thus improve the flavor; to reduce the bulk so we can pack closer; to
start the flow of the coloring matter; to improve the texture of the
vegetables by making them more tender, and to improve the appearance
by helping to make clear the liquid in the jar. Blanching is what
makes for success in the cold-pack method of canning. Blanching is
_very_ important and must be carefully and accurately done.

Let me repeat about blanching: Have the kettle of blanching water
_boiling vigorously, completely immerse_ the product in the boiling
water, cover the kettle _immediately_ and begin to time the product.
Do not stand with the cover in hand and wait for the water to come
back to the boil, for, of course, it stopped boiling for a second when
you lowered into it the cold product. If you cover the kettle the
water will quickly reboil. Do not keep wondering if it is boiling and
take off the cover to see. All these may seem foolish precautions, but
it is necessary to follow directions accurately.

And remember, all things that are scalded or blanched must be followed
immediately by a cold plunge or "cold-dip." The scalding or blanching
is the "hot-dip," and this must be followed by the "cold-dip." You may
be asking, what is the point of this "cold-dip"? It is a very logical
question.

We "cold-dip" a product to harden the pulp under the skin and thus
permit the removal of the skin without injury to the pulp; to
coagulate the coloring matter and make it harder to dissolve during
the sterilization period and to make it easier to handle the products
in packing, and to subject the product to a sudden shock by quick
change in temperature.

STEPS IN CANNING VEGETABLES

If you will follow these steps for all vegetable canning you cannot
help but be successful:

1. Clean jars and test rubbers. If rubbers do not return to normal
shape after stretching, do not use.

2. Prepare material to be canned, according to directions given on
chart.

3. Hot-dip--blanch or scald--the prepared food. This process consists
of immersing the prepared product in boiling water for different
lengths of time, according to the material to be canned. See chart.
Hot-dipping shrinks the product and enables one to pack more material
in a jar.

4. Cold-dip the material. This process consists of plunging the
blanched or scalded food into cold water, which makes it more easily
handled. Be sure the water is cold; the colder the better.

Take the product out immediately and let it drain. _Don't let any food
soak in the cold water._

From this point on, speed is highly important. The blanched vegetables
which are slightly warm must not be allowed to remain out of the jars
a moment longer than is necessary.

Remove skins when required, and as each article is pared cut it into
pieces of proper size and

5. Pack directly into the clean, scalded cans or jars. Pack as solidly
as possible, being careful not to bruise or mash soft products. Pack
the product to within three-eighths of an inch of the top. Lima beans,
navy beans, peas, corn, pumpkin and sweet potatoes swell, so pack them
within only one inch of the top of the jar.

6. Add seasoning. One teaspoonful salt to every quart jar of
vegetables, and an equal amount of sugar to tomatoes, corn and peas if
desired.

7. Add boiling water to within a quarter inch of top to all
vegetables, except tomatoes and greens. Tomatoes contain ninety-four
per cent water, so none should be added. Tomato juice can be used if
desired. Greens are canned in just the water that clings to the
leaves after the cold-dip.

8. Adjust rubber rings and the covers of the jars; partially seal.

9. Sterilize--see time-table on pages following.
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

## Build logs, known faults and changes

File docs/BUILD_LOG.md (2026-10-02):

# Build Log — Offline Survival LLM Device

Every session gets an entry. Mistakes and challenges are the most
valuable content here — never sanitized, never skipped.

Template:

## YYYY-MM-DD — Session title
**Goal:**
**Done:**
**Mistakes/Challenges:**
**Improvements/Decisions:**
**Hardware/Tools used:**
**Next:**

---
(entries begin below)

## 2026-09-15 — Phase 0: repo + logging scaffolding
**Goal:** Stand up the git repo, logging infrastructure, and GitHub remote before any build work (Phase 0 of IMPLEMENTATION_PLAN.md).
**Done:**
- Scaffolding (README, CLAUDE.md, IMPLEMENTATION_PLAN.md, BUILD_PLAN.md, CORPUS_CHECKLIST.md, docs/, corpus/pd + corpus/own, scripts/ with setup.sh, rag_build.py, main.py, verify.py, keypad_serial.ino, .gitignore) already existed on disk; this session put it under version control.
- `git init -b main` in the project folder on the owner's Mac (not the Pi — see Mistakes).
- Verified .gitignore with `git check-ignore -v`: models/, corpus/own/, venv/, index.faiss, chunks.pkl all correctly ignored.
- First commit of scaffolding; created public repo barack-hash/offline-survival-llm via `gh repo create` and pushed.
**Mistakes/Challenges:**
- `git add -A` staged macOS `.DS_Store` files (root and corpus/). The provided .gitignore didn't cover them because the plan assumed work happens on the Pi (Linux). Fix: appended `.DS_Store` to .gitignore and `git rm --cached` the staged copies.
- Environment mismatch: this session runs on the owner's Mac, but Phases 1+ (apt, raspi-config, vcgencmd, llama.cpp build) must run on the Pi 5 itself. Decision: do Phase 0 here where `gh` is already authenticated; the Pi will `git clone` the repo to start Phase 1.
**Improvements/Decisions:**
- Repo created public, as the plan specifies — safe because .gitignore keeps models and copyrighted scans (corpus/own/) local by construction.
**Hardware/Tools used:** Owner's Mac only (git, gh CLI). No Pi or Arduino hardware touched.
**Next:** Phase 1 on the Raspberry Pi 5: clone the repo, record system info in docs/HARDWARE.md, apt full-upgrade, enable SPI, log idle/load temperatures.

## 2026-09-15 — Phase 1: system verification & prep (via SSH from Mac)
**Goal:** Confirm the Pi 5 is healthy and configured before heavy installs: record specs, full OS upgrade, enable SPI, log idle/load temperatures.
**Done:**
- Enabled classic SSH on the Pi (owner ran `raspi-config nonint do_ssh 0` via Raspberry Pi Connect remote shell) and installed the Mac's ed25519 public key; all Phase 1 commands ran over SSH as `yitbarek@raspberrypi.local` (10.0.0.228).
- Recorded specs: Raspberry Pi 5 Model B Rev 1.1, 8GB RAM, 117GB SD (7% used), Debian 13 (trixie).
- `sudo apt update && apt full-upgrade -y` — large upgrade incl. kernel 6.12.47 → 6.18.50; clean reboot onto the new kernel confirmed.
- SPI enabled: `raspi-config nonint do_spi 0`, `get_spi` returns 0 (enabled); `dtparam=spi=on` in config.txt.
- Thermal benchmark (`stress --cpu 4 --timeout 120`):
  | State | Temp | Fan RPM |
  |---|---|---|
  | Idle (fresh boot) | 49.4–50.5°C | ~1150 |
  | Load t+15s | 65.3°C | 2337 |
  | Load plateau (t+75–105s) | 69–70°C | ~3600 |
  | 5s after load | 58.7°C | — |
  `vcgencmd get_throttled` = 0x0 (no throttling, no undervoltage ever).
**Mistakes/Challenges:**
- **Fan not detected at boot.** First readings showed idle temp 70–76°C and NO `cooling_fan` hwmon device; `/proc/device-tree/cooling_fan/status` = `disabled`. Root cause: Pi 5 firmware probes the FAN header only at power-on, and the fan connector was not fully seated when the Pi was first powered. Fix: clean shutdown, owner re-seated the fan connector, power cycle → status `okay`, fan spinning, idle temp dropped ~25°C. Lesson: always verify `cooling_fan/status = okay` after any re-assembly.
- **apt full-upgrade died on a conffile prompt.** `rpi-chromium-mods` hit an interactive prompt for locally-modified `/etc/chromium/master_preferences` under non-interactive stdin: `end of file on stdin at conffile prompt`. Fix: `sudo dpkg --configure -a --force-confold` (keep existing config); `apt-get check` clean afterwards.
- Early network probing from the Mac was misleading: `ping raspberrypi.local` reported "No route to host" while the Pi was actually up (mDNS resolved fine; ICMP blocked/mac local-network permission). Lesson: test the actual port (`nc -z host 22`), not ping.
**Improvements/Decisions:**
- SSH-from-Mac chosen as the working mode (key auth, no passwords); Raspberry Pi Connect kept as fallback/console access.
- Repo not yet cloned on the Pi — docs are maintained in the Mac working copy and pushed. Phase 2 will clone the repo on the Pi.
**Hardware/Tools used:** Raspberry Pi 5 (first hands-on session), active cooler fan (re-seated), owner's Mac as SSH client.
**Next:** Phase 2 — clone repo on the Pi, run scripts/setup.sh (build llama.cpp, download Phi-3 Mini Q4 GGUF), benchmark tokens/sec and RAM.

## 2026-09-15 — Phase 2: LLM engine built, model running, benchmarked
**Goal:** llama.cpp built from source on the Pi, Phi-3 Mini Q4 downloaded, first answer generated, benchmarks recorded.
**Done:**
- Cloned barack-hash/offline-survival-llm to `~/offline-survival-llm` on the Pi.
- `scripts/setup.sh` ran end-to-end: deps installed, llama.cpp built (build b10991-930e2fa59, -j4, ~15 min), Phi-3-mini-4k-instruct-q4.gguf downloaded (2.3GB, no URL 404), venv created with sentence-transformers/faiss-cpu/pypdf/llama-cpp-python/pyserial.
- First on-device answer: bow-drill fire question → coherent, correct 3-step answer.
- Benchmarks (llama-bench, CPU, 4 threads):
  | Test | Result |
  |---|---|
  | pp512 (prompt processing) | 18.69 ± 0.34 t/s |
  | tg128 (generation) | 4.74 ± 0.01 t/s |
  | RAM during inference | 4.4GB used, **3.5GB available** (>3GB criterion met) |
  | Temp during inference | 68.6°C, fan active, no throttling |
- Fixed setup.sh quick-test to pass `-st` (single-turn); committed.
**Mistakes/Challenges:**
- **setup.sh hung forever at the quick test.** Current llama-cli defaults to interactive chat mode; run detached with no stdin it looped printing `> ` prompts. Symptom: log filled with blank prompts, and the log file eventually grew to **3.9GB**, eating SD space. Fix: killed it, trimmed the log, added `-st` to setup.sh. Lesson: never assume CLI flags/behavior are stable in fast-moving projects; run smoke tests with explicit non-interactive flags.
- `-no-cnv` (the old non-interactive flag) is gone in build b10991: `error: invalid argument: -no-cnv`. Current flag is `-st, --single-turn`.
- Self-inflicted: `pgrep -f "llama-cli|setup.sh"` over SSH matches the SSH session's *own* command line, and a `kill` based on it killed my own shell (ssh exit 255, looked like the Pi crashed). Lesson: use `pgrep -x` / `pgrep -fx` for exact matches.
**Improvements/Decisions:**
- Generation is 4.74 t/s — slightly under the 5–10 t/s expectation for Pi 5 + Q4 3.8B. Acceptable for now; potential later tunings (one at a time, per rules): Q4_0 quant with ARM dot-product kernels, `-t 4 --mlock`, or a smaller model if Phase 4 latency feels bad.
**Hardware/Tools used:** Raspberry Pi 5 (all work over SSH). No new physical hardware.
**Next:** Phase 3 — download public-domain corpus texts (FM 21-76 + one more), log them in CORPUS_SOURCES.md, build the RAG index, spot-check retrieval.

## 2026-09-15 — Phase 3: corpus downloaded, RAG index built, retrieval verified
**Goal:** At least 2 public-domain sources in corpus/pd/, indexed with rag_build.py, retrieval spot-checked on fire / water / shelter.
**Done:**
- Downloaded 3 PD texts straight onto the Pi (all as OCR/plain text, verified by reading headers — no 404s; archive.org metadata API used to find exact filenames instead of guessing URLs):
  - fm21-76-survival-manual.txt (559KB) — FM 21-76 US Army Survival Manual
  - first-book-of-farming-1905.txt (403KB) — Goodrich 1905, Project Gutenberg #16900
  - practical-blacksmithing-1889.txt (315KB) — Richardson 1889, archive.org
- All three logged in docs/CORPUS_SOURCES.md with URL/edition/license.
- `rag_build.py`: **1310 chunks** (FM 585, farming 415, blacksmithing 310), index build **2m20s** on the Pi (embedding ~1.9s/batch of 32). index.faiss + chunks.pkl generated, correctly untracked by git.
- Spot-checks (top-3 by L2 distance) — all **PASS**:
  - "start a fire without matches" → FM fire-starting methods + char cloth chunks (dist 0.85–0.94)
  - "purify water for drinking" → FM WATER PURIFICATION + seepage-basin filtration (dist 0.63–0.94)
  - "build a shelter in the wilderness" → FM shelter-site/types + snow shelter (dist 0.62–0.72)
**Mistakes/Challenges:**
- Heredoc-over-SSH with escaped quotes inside an f-string broke (`SyntaxError: unexpected character after line continuation character`). Fix: write the spot-check script to a file and `scp` it — stop fighting three layers of shell quoting.
- Gutenberg search for "blacksmithing" returned nothing; found *Practical Blacksmithing* via archive.org advanced-search API instead.
**Improvements/Decisions:**
- Preferred `_djvu.txt` OCR text over PDFs where available — cleaner input for chunking than pypdf extraction, and 5-10x smaller.
- Corpus files copied back into the Mac working copy so corpus/pd/ is committed (PD texts are allowed in the public repo per .gitignore policy).
- Still missing, needs owner action (licensing — cannot be auto-downloaded): *Where There Is No Doctor* / *Where There Is No Dentist* (FREE, hesperian.org), *The Knowledge* (OWN — buy + scan, goes in corpus/own/, never committed).
**Hardware/Tools used:** Raspberry Pi 5 over SSH. No new physical hardware.
**Next:** Phase 4 — run main.py in keyboard mode, 10-question evaluation with verdicts, confirm critical mode + out-of-corpus refusal.

## 2026-09-16 — Phase 4 (overnight): eval, engine swap, all criteria pass
**Goal:** 10-question evaluation with verdicts; critical mode verified with verbatim sources; out-of-corpus refusal verified; verify.py with ≥5 real cases running clean. Owner asleep — full permission to test and fix.
**Done:**
- Added Hesperian books (owner-supplied PDFs): corpus/free/where-there-is-no-doctor.pdf + where-there-is-no-dentist.pdf. corpus/free/ gitignored (FREE license ≠ PD). Index rebuilt: **2801 chunks** total (Doctor 1150, FM 585, farming 415, dentist 341, blacksmithing 310), 4m53s.
- Built scripts/eval_questions.py (fixed 10-question battery through main.py's exact pipeline) — 3 full runs + diagnostics.
- **Run 1** (Phi-3, n_ctx 2048): 8/10 answered, template artifacts ('[Response]:', duplicated answers), then **crash** on the critical question.
- **Run 2** (n_ctx 4096): critical question produced **complete gibberish** (word salad at temp 0); out-of-corpus rambled but didn't invent.
- Diagnostics: gibberish reproduced with (a) chat template, (b) fresh Phi-3.1 GGUF, (c) the source-built llama-cli binary → NOT the runtime, NOT the file, NOT the prompt format. Root cause: **llama.cpp renders Phi-3's sliding-window attention (window 2047) as garbage past ~2k tokens** — exactly what critical mode's 8-chunk prompts hit.
- **Engine swap: Qwen2.5-3B-Instruct Q4_K_M** (1.8GB, 32k native ctx) + all generation moved to main.generate_answer() using the model's chat template. Same 3.4k-token prompt now answers correctly, quoting "adults: 1 or 2 tablets (300 to 600 mg.)" verbatim from WTIND.
- **Run 3 verdicts (Qwen):** Q1 fire/wet wood GOOD · Q2 water purification GOOD · Q3 cold shelter GOOD · Q4 edible plants GOOD · Q5 wound care GOOD · Q6 infected tooth GOOD · Q7 seed depth VAGUE (right chunks retrieved, model garbles the 1905 experiment's conclusion) · Q8 forged-knife hardening WRONG-TARGET (retrieval, see below) · Q9 aspirin dose **CRITICAL PASS** · Q10 car firmware **DECLINE PASS**.
- End-to-end main.py keyboard-mode test (piped stdin): ⚠ safety-critical banner, all 8 raw chunks printed verbatim, corroboration = 2 sources (no warning, correct), summary quotes exact dose. **Acceptance criterion met.**
- verify.py: 6 real test cases (incl. critical dose + out-of-corpus canary); full run clean, all sane.
- Filed issue #4: retrieval query-phrasing sensitivity — probe showed 'harden a knife I forged' ranks blacksmithing chunks 7-10 (so TOP_K=6 wouldn't fix it), while 'harden and temper steel in a forge' ranks them 1-10. Deferred with concrete options (query expansion, hybrid BM25+vector, better embedder, header-aware chunking).
**Mistakes/Challenges:**
- The model swap ate the night: n_ctx crash → gibberish → 3 rounds of hypothesis elimination (template? GGUF? runtime?) before landing on the SWA/llama.cpp architecture issue. Each wrong hypothesis is logged above because the elimination order is the useful part.
- Ran a diagnostic from /tmp: `ModuleNotFoundError: No module named 'main'` — scripts importing main.py must run with PYTHONPATH=scripts or from the scripts dir.
- Repeated the pgrep self-match mistake from Phase 2 in a watcher (pattern matched the SSH session's own command line) — caught before it burned anything this time.
**Improvements/Decisions:**
- Qwen2.5-3B-Instruct is the device model now; both Phi-3 GGUFs kept in models/ (gitignored) as evidence/fallback. Qwen research license: fine for personal device use.
- Timings (Qwen, Pi 5): normal answers 65–140s, critical (8-chunk) 160s. Prompt processing 22.3 t/s, generation ~3 t/s at long ctx.
- Known limitations logged rather than over-tuned at 1am: Q7 summarization garble, Q8 phrasing-sensitive retrieval (issue #4). One-change-at-a-time discipline held: n_ctx fix → model+template swap → nothing else.
**Hardware/Tools used:** Raspberry Pi 5 over SSH all night. No physical hardware touched.
**Next:** Phase 5a — Arduino keypad: owner wires the 4x4 keypad per keypad_serial.ino pin map, photographs wiring, flashes the sketch; then serial-mode test + multi-tap issue.

## 2026-09-16 — Remote access: Tailscale, so tuning can continue from anywhere
**Goal:** Owner wants to keep tuning/testing the Pi from work (different network) before the wiring phase.
**Done:**
- Installed Tailscale on the Pi (`curl -fsSL https://tailscale.com/install.sh | sh`, `sudo tailscale up`), owner authorized it; Pi is `raspberrypi` / 100.123.242.97 on the tailnet.
- Owner installed the Tailscale macOS app and signed in (brew cask needed an admin password, so this step was theirs).
- Verified SSH end-to-end over Tailscale; added `Host pi` alias to the Mac's ~/.ssh/config → `ssh pi` now works from any network where both machines are signed in.
**Mistakes/Challenges:**
- `brew install --cask tailscale` fails non-interactively (`installer -pkg` needs sudo) — Mac-side GUI installs need the owner.
**Improvements/Decisions:**
- Tailscale over port-forwarding/dynamic-DNS: no SSH exposed to the internet, no router config. Raspberry Pi Connect kept as an independent browser-based backup door.
- Requirement for remote sessions: Pi powered on at home; both devices signed into the tailnet.
**Hardware/Tools used:** None physical.
**Next:** Phase 5a keypad wiring (owner's hands) — or continued remote eval/tuning sessions (issue #4 retrieval robustness is the queued tuning work).

## 2026-09-16 — Issue #4: hybrid BM25+vector retrieval, hit@4 94%→100%
**Goal:** Fix query-phrasing-sensitive retrieval (issue #4) with ONE measured change.
**Done:**
- Built scripts/eval_retrieval.py: 16 queries with required-source labels (the 10-question battery's targets + 6 phrasing variants), runs in seconds with no LLM. This is the retrieval regression suite now.
- **Baseline (vector-only): 15/16 = 94%** — sole miss is the issue #4 case ('harden the edge of a knife I forged' → blacksmithing book absent from top 4).
- **Change: hybrid retrieval in main.py.** BM25 (rank_bm25) over chunk tokens + FAISS vectors, each contributing a top-20 candidate pool, merged by reciprocal rank fusion (RRF k=60). BM25 index builds in ~2 s at startup, cached. rank-bm25 added to setup.sh.
- **After: 16/16 = 100%**, no regressions on the other 15 queries.
- Full 10-question generation battery re-run (run 4): no regressions Q1–6, Q7 improved (now conveys the too-deep-beans caveat), Q10 still declines, Q9 critical still quotes grounded figures. Q8: blacksmithing source now retrieved, **but the 3B model still synthesizes from FM's wooden-knife chunk** — retrieval layer fixed, generation source-selection remains (noted on issue #4).
**Mistakes/Challenges:**
- None new this session; the probe-first discipline (measure whether TOP_K would even help before touching it — it wouldn't) paid off.
**Improvements/Decisions:**
- RRF over score-mixing: rank-based fusion needs no score normalization between L2 distances and BM25 scores.
- Q9 observation: the critical answer alternates between two grounded passages (Green Pages dosage table vs fever chapter) across runs — both correct quotes; the on-device verbatim chunk display is the real safety net.
**Hardware/Tools used:** Pi over Tailscale (`ssh pi`) — first tuning session through the new remote path.
**Next:** Remaining issue #4 scope (generation prefers wrong retrieved chunk): candidate single changes are source-diversity ordering in the prompt, or a rerank step. Or proceed to Phase 5a when owner is home.

## 2026-09-16 — Issue #4 closed: the "generation bug" was a corpus gap
**Goal:** Fix the generation side of issue #4 (model answered the forged-knife question from FM's wooden-knife passage even after retrieval was fixed).
**Done:**
- **Change 1 — subject-match prompt rule** (SUBJECT_MATCH_RULE in main.py, added to both system prompts): tells the model to answer only from passages about the question's actual subject and to say so if none match. Q8-only test: did NOT fix Q8. Full battery (run 5): kept anyway — zero regressions, Q6 (tooth extraction) markedly better, Q10 decline crisper.
- **Diagnosis that mattered:** dumped Q8's retrieved chunks — FM's are stone/bone/wood knife content and the 1889 blacksmithing chunk is about re-entering angles. `grep -ci temper practical-blacksmithing-1889.txt` = 21, mostly anvils/dies. **The corpus never contained usable blade-hardening instructions.** No prompt or retriever can fix a missing book.
- **Change 2 — fill the gap:** added Woodworth, *Hardening, Tempering, Annealing and Forging of Steel* (1903, PD, archive.org OCR text, 382 'temper' mentions). Index rebuilt: **3157 chunks / 6 sources** (Woodworth 356).
- Results: eval_retrieval still **16/16** under a stricter expectation (Woodworth must now surface for both blade queries). Q8 retest: correct bladesmithing answer — heat edge to cherry red, oil-quench the edge then let it down into water, warp-straightening tip. Issue #4 closed.
**Mistakes/Challenges:**
- Spent one change chasing a prompt fix for what was actually missing data. The chunk-dump diagnosis should have come FIRST — 'look at what the model was actually given' is cheaper than any tuning run. Logged as the session's lesson.
- Q9 (aspirin, runs 4-5): the model garbles "adults under 12 years old" when summarizing the fever-chapter table. The quoted figures stay correct and the device shows raw chunks in critical mode, but this is a standing reminder that the summary line is the weakest link — the verbatim display is the safety net.
**Improvements/Decisions:**
- eval_retrieval.py knife/temper cases now expect hardening-tempering-steel-1903.txt (the metric got stricter, intentionally).
- Corpus principle learned: for a reference device, coverage gaps masquerade as model stupidity. When an answer is off-subject, check what was retrievable before tuning anything.
**Hardware/Tools used:** Pi over Tailscale.
**Next:** Phase 5a keypad wiring (owner's hands), or further corpus expansion (knots, celestial navigation, basic chemistry per CORPUS_CHECKLIST).

## 2026-09-16 — Corpus expansion: knots, navigation, chemistry (9 sources, 4310 chunks)
**Goal:** Fill the knots / navigation / chemistry rows of CORPUS_CHECKLIST.md with PD texts.
**Done:**
- Added 3 Project Gutenberg texts (plain UTF-8, no OCR noise):
  - Verrill, *Knots, Splices and Rope Work* 1912 (PG #13510) — 89 chunks
  - Draper, *Lectures in Navigation* (US Navy course) 1917 (PG #27642) — 295 chunks
  - McPherson & Henderson, *An Elementary Study of Chemistry* 1906 (PG #20848) — 769 chunks
- Index rebuilt: **4310 chunks / 9 sources**. All logged in CORPUS_SOURCES.md.
- eval_retrieval.py extended to 22 cases (2 per new source: rope joining/splicing, latitude by sun-stars, compass errors, soap from fat+lye, lime burning): **22/22 = 100%**, no regressions.
- CORPUS_CHECKLIST.md brought up to date: 14 items now checked with what satisfied each.
**Mistakes/Challenges:**
- gutendex.com search API was flaky/slow (two searches returned nothing); archive.org's advancedsearch found the Gutenberg-mirrored navigation text (`lecturesinnaviga27642gut`) which gave the PG id.
- scp brace-expansion `{a,b,c}.txt` failed against the remote path (quotes stopped local expansion) — looped single copies instead.
**Improvements/Decisions:**
- Checklist gaps remaining that are auto-fetchable later: solar/wind primer, food preservation/canning, carpentry/masonry, US military first-aid manual, mechanics primer, electricity primer, fiber/rope-making, radio theory. Herbal medicine deliberately deferred — needs the unverified-folk-knowledge framing decision first.
- *The Knowledge* (Dartnell) remains the owner's OWN-license to-do.
**Hardware/Tools used:** Pi over Tailscale.
**Next:** Phase 5a keypad wiring, or the next corpus batch (first-aid manual + food preservation are highest-value).

## 2026-09-16 — Commit attribution fixed + corpus batch 2 (13 PD sources, 6136 chunks)
**Goal:** (a) Re-attribute all commits from the eiQora company identity to the owner personally; (b) add the remaining auto-fetchable corpus batch: first aid, canning, wind power, carpentry, electricity, radio.
**Done — attribution:**
- All 14 commits were authored `eiQora <yitbarekabegaz@eiqora.com>` — the Mac's *global* git config carried the company identity. Rewrote full history (`git filter-branch --env-filter`) to `Yitbarek Tegene <abegazyitbarek@gmail.com>`, force-pushed (`--force-with-lease` with explicit lease sha), realigned the Pi clone with `git reset --hard origin/main`. Global git config switched to the personal identity; eiQora repos must now set theirs locally.
**Done — corpus batch 2 (all PD, provenance in CORPUS_SOURCES.md):**
- FM 21-11 *First Aid for Soldiers* 1943 (129 chunks) · Gray *Every Step in Canning* 1920 (436) · Powell *Windmills and Wind Motors* 1910 (93) · Fairham *Woodwork Joints* 1921 (250) · Morgan *The Boy Electrician* ©1913 (491; edition year verified in the scan before trusting PD status) · Collins *The Radio Amateur's Hand Book* 1922 (427).
- Index rebuilt: **6136 chunks / 15 files (13 PD + 2 FREE)**. eval_retrieval.py extended to **34 cases: 34/34 = 100%**, no regressions.
- CORPUS_CHECKLIST.md: 20 items checked. Remaining: masonry half of carpentry row, fiber/rope-making, water filtration engineering text, mechanics primer, herbal medicine (deferred pending warning-framing decision), The Knowledge (owner OWN), owner's own build notes.
**Mistakes/Challenges:**
- gutendex.com fully down this session — archive.org advancedsearch + Gutenberg cache URLs used instead; Gutenberg-mirror identifiers (`...NNNNNgut`) are a reliable way to recover PG ids.
- The mid-session `git reset --hard` on the Pi (attribution fix) silently reverted the not-yet-committed 34-case eval_retrieval.py to the 22-case version, so the first suite run after the rebuild tested the wrong file (reported 22/22). Caught because the case count didn't match; re-synced and re-ran → 34/34. Lesson: don't interleave history surgery with uncommitted-file workflows on a second machine.
- `filter-branch` refused to run over unstaged changes (stash → rewrite → pop), and `--force-with-lease` needed an explicit sha because the rewrite had also rewritten the local origin/main ref.
**Improvements/Decisions:**
- The Boy Electrician chosen over post-1929 electricity texts specifically because the 1913 copyright was verifiable inside the scan.
**Hardware/Tools used:** Pi over Tailscale.
**Next:** Phase 5a keypad wiring (owner's hands). Corpus is now broad enough that further additions should be demand-driven (add when an eval question exposes a gap, like the Woodworth case).

## 2026-09-16 — Phase 5a prepared: multi-tap keypad + LCD1602 interim display
**Goal:** Owner asked (a) how a digits-only keypad can type questions, (b) whether the starter-kit display can be used. Prepare everything software-side so wiring day is plug-and-play.
**Done:**
- Kit identified from owner's box photo: **LAFVIN Super Starter Kit for UNO R3** — contains everything Phase 5a needs (UNO R3, 4x4 membrane keypad, LCD1602 parallel + 10K pot, breadboard, jumpers). No purchases needed for 5a; HARDWARE.md updated.
- **keypad_serial.ino rewritten**: old-phone multi-tap text entry (2=abc2 … 9=wxyz9, 1=punctuation, 0=space, *=backspace, A=commit, #=send), 1 s letter timeout, question buffered on the Arduino with live LCD preview, only the finished line sent to the Pi. Removed the rotary-encoder code (kit has none). This supersedes the planned digits-only first version — no reason to ship the crippled input when multi-tap fits in the sketch.
- **LCD1602 as interim display**: Arduino shows incoming serial lines across both LCD rows; main.py's SerialKeypadInput gained display_answer() — answers paged at 32 chars / 3 s so the UNO needs no big buffer (2KB SRAM). Critical answers are prefixed `!CRITICAL! verify vs 2nd source:` on the LCD.
- docs/wiring/phase5a-keypad-lcd.md: full pin map (keypad→D2-D9, LCD 4-bit on D10-D13+A0/A1, pot for contrast), flash steps, typing cheat sheet.
**Mistakes/Challenges:**
- Owner's photo was HEIC and over the read size limit — converted/downscaled with sips first.
**Improvements/Decisions:**
- Multi-tap decoding lives on the Arduino, not the Pi: the Pi's serial protocol stays "one line = one question", so main.py needed no input-side changes and the future e-ink phase only swaps the display half.
- Note for wiring day: this supersedes the "digits+A-D only" limitation the plan expected to log; the multi-tap GitHub issue planned in Phase 5a step 5 is no longer needed.
**Hardware/Tools used:** None physically touched (owner away) — kit contents identified from photo.
**Next:** Wiring day: owner wires per docs/wiring/phase5a-keypad-lcd.md, photographs it, flashes the sketch; then INPUT_MODE="serial" end-to-end test and the first hardware-typed question gets logged verbatim.

## 2026-09-18 — Phase 5a COMPLETE: defective keypad forensics, IR-remote pivot, first hardware question
**Goal:** Wire keypad + LCD, flash, and get the first question asked entirely on device hardware.
**Done:**
- LCD1602 turned out to be the I2C-backpack variant → 4-wire hookup (GND/5V/A4/A5), sketch moved to LiquidCrystal_I2C. Worked first try (address 0x27).
- Toolchain: arduino-cli on the Mac (needed Rosetta 2 — bundled avr-gcc is x86-only), flashing over /dev/cu.usbmodem1101.
- **Keypad forensics** (the night's saga, in order):
  1. First test: phantom 'A' flood + missed presses.
  2. Raw-key diag sketch: ~40 events for 4 presses, mostly 'A'.
  3. Board went totally silent + bootloader 'not in sync' → **power cycle fixed it** (chip was wedged; lesson: power-cycle before suspecting wiring).
  4. Wiring-agnostic pair-scan sketch (drive each of D2-D9 low, watch the rest): pairs **D2-D9 and D4-D6 stream continuously with no key pressed** = keys 'A' and '0' electrically stuck.
  5. Isolation: shorts persist with keypad dangling in air (not table pressure); one-by-one unplug timeline showed shorts follow the keypad wires; all-unplugged = silent (Arduino + jumpers healthy); **only ribbon wires 1+8 reconnected → D2-D9 short returns instantly with no touch. Verdict: membrane internally shorted (lines 1-8, 4-6). Defective from factory.**
- **Pivot: kit's NEC IR remote as input device.** IR receiver (G/R/Y → GND/IOREF/D2, 3 wires). Scanned all 17 buttons (owner pressed sequence; one accidental extra ◀ press was identifiable in the timeline) — codes match the documented LAFVIN/Elegoo NEC map. New scripts/ir_remote_serial.ino: same multi-tap scheme (2=abc...), *=backspace, 0=space, #=send, OK=commit-letter, arrows reserved; NEC repeat frames ignored.
- Standalone proof: owner typed **"fire"** on the remote → arrived verbatim over serial.
- Hiccups on the way: remote's battery pull-tab still in (found via phone-camera IR test), IOREF used as second 5V source (LCD holds the only 5V socket), two Mac serial listeners colliding on the port.
- **MILESTONE:** Arduino moved to the Pi (/dev/ttyACM0), main.py in serial mode. First hardware question: **"fire"** → grounded FM 21-76 answer (tinder/kindling/fuel progression, upwind placement, sawdust/salt-brine reignition), paged on the LCD at 32 chars/3s. On-device perf: prompt 26.5 t/s, generation 5.47 t/s, 82 s total.
- Photos in docs/wiring/ (keypad-era wiring + IR remote). HARDWARE.md updated incl. the defective part.
**Mistakes/Challenges:** all inline above — this session WAS the mistakes. Biggest lessons: (1) a component can be dead from the factory — build the diagnostic before re-wiring in circles; (2) when serial dies AND flashing dies, power-cycle first; (3) `pgrep -f` self-match bit again on the Mac (port cleanup).
**Improvements/Decisions:**
- IR remote is now the primary input (arguably better for the enclosure: sealed pocket, no ribbon passthrough). keypad_serial.ino kept in repo for a future replacement pad.
- Multi-tap GitHub issue from the original plan is moot (implemented from day one).
**Hardware/Tools used:** Arduino UNO R3, LCD1602 (I2C), IR receiver + remote (first use), defective 4x4 membrane keypad (diagnosed), breadboard/jumpers, owner's phone camera as IR detector.
**Next:** Leave device running for daily use; Phase 5b when e-ink arrives; Phase 6 shopping (UPS HAT, 18650s, solar panel). Optional: replacement keypad (issue #6).

## 2026-09-18 — Appliance mode: systemd service, survives power-on unattended
**Goal:** Device must serve its purpose the moment power arrives — no SSH, no manual start.
**Done:**
- scripts/survival-llm.service added to the repo and installed: Restart=always/RestartSec=5 (retries until the Arduino enumerates), TimeoutStartSec=300 for the model load, no network dependencies by design, Nice=-5.
- Killed the old nohup-run main.py, enabled the service, verified `assistant ready` in the journal.
- **Cold-boot test: `sudo reboot` → service auto-started → ready ~60 s after power-on** with zero human involvement.
- Owner's post-reboot question via IR remote: "i am stranded on an island" → full 399-token grounded answer paged on the LCD. Timing measured: prompt 26.5 t/s, generation 5.44 t/s, 127 s total for a maximum-length answer.
**Mistakes/Challenges:**
- First reboot-watcher script had a race (checked the journal before the boot had anything in it) — re-checked manually.
**Improvements/Decisions:**
- Open-ended prompts generate the full 400-token budget (~2 min). Acceptable for now; if field latency ever matters, options are max_tokens reduction or a smaller quant — one change at a time, measured.
- journalctl -u survival-llm is now the device's flight recorder (questions, answers, perf lines all land there).
**Hardware/Tools used:** Pi 5 + full input/display stack (first unattended cold boot of the complete device).
**Next:** Daily-driver period; Phase 5b/6/7 as hardware arrives (issues #1-#3).

## 2026-09-24 — Phase 7 started early: parametric enclosure draft v0.2
**Goal:** Design the enclosure before ordering a 3D print, around the parts chosen in the shopping sessions (Waveshare 4.2" e-ink, M5Stack CardKB, Geekworm X1202 + 4× 18650, Pi 5).
**Done:**
- enclosure/enclosure.scad: fully parametric OpenSCAD model — rear tub (stack guides, M3 insert bosses, intake/exhaust vents, X1202 USB-C + DC-jack cutouts, lanyard tab, grip grooves, rubber-feet pockets, engraved charging + safety text), front bezel (chamfered screen window, keyboard opening with shallow recess, rivet ring, M3 counterbores, alignment lip, engraved label), retainer plate (raised frames clamp screen + keyboard against the bezel, open centres for cables, notch for the CardKB Grove cable).
- Outer size 109.4 × 169.9 × 74.3 mm (+7 mm lanyard tab).
- enclosure/viewer.html: three.js viewer (orbit, explode slider, show/hide parts, ghost electronics) served locally; STLs rendered with OpenSCAD CLI.
- Two iterations: v0.1 (functional shell) → v0.2 after reviewing renders (edge chamfers, grip grooves, larger label, rear engraving, feet pockets).
**Mistakes/Challenges:**
- `brew install --cask openscad` fails: cask disabled 2026-09-01 ("does not pass the macOS Gatekeeper check"). `openscad@snapshot` (2026.09.23) installs and works.
- First viewer render showed the device lying face-up: I rotated the model -90° about X, but OpenSCAD's axes (X width, Y height, Z out of the face) already match three.js's camera frame. Removed the rotation.
- Preview server config had to live at the DoomsDay root `.claude/launch.json`, not inside the repo folder.
- Corrected earlier shopping advice: X1202 needs **unprotected flat-top** 18650s (≤18.5 mm dia, ≤65.3 mm long).
**Improvements/Decisions:**
- Engraved the device's safety rule on the back ("reference aid — not a sole authority for medical dosing, structural or electrical decisions"), matching CLAUDE.md.
- 74 mm depth is driven by the 4-cell X1202 stack (56 mm assumed). Slimming ideas deferred until the real stack is measured.
- Every datasheet-derived size is tagged VERIFY; STLs are explicitly draft until parts are measured with calipers.
**Hardware/Tools used:** None physical. OpenSCAD 2026.09.23 snapshot, three.js 0.160 viewer.
**Next:** When parts arrive: caliper-measure stack height, e-ink module + glass + active area, CardKB thickness, X1202 port positions → update VERIFY params → test-print the bezel only (cheapest fit check) before the full enclosure.

## 2026-09-24 — Enclosure v0.3: real part dimensions + slim stepped profile
**Goal:** Make the enclosure slimmer and size it to the exact screen and keyboard being bought.
**Done:**
- Pulled manufacturer dimensions: Waveshare 4.2" e-Paper Module manual (driver board 103.0 × 78.5 mm, display 84.8 × 63.6 mm, panel 90.1 × 77.0 × 1.18 mm; new units ship V2 with partial refresh), M5Stack store (CardKB v1.1 88.0 × 54.0 × 5.0 mm, I2C 0x5F, $7.95 direct vs $18.99 on the Amazon clone listing).
- CardKB is 4 mm wider and 3.5 mm thinner than v0.2 assumed (84 × 54 × 8.5).
- Re-laid out the enclosure: the Pi/X1202 stack (85 mm tall) sits only behind the screen band; the keyboard section is thin. Depth **74.3 mm → 59.2 mm behind the screen, 11.4 mm at the keyboard.**
- Stack height re-estimated to 48 mm (cells + X1202 + spacers + Pi 5 + cooler; Geekworm's own case is 62.8 mm outside, an upper bound) — still VERIFY.
- Structure changes: screws at the top corners + beside the keyboard; bezel hooks into snap windows along the bottom edge (too thin there for inserts); keyboard held against the bezel by floor rails + 1 mm foam, rails split for the CardKB cable; screen clamped by a slim retainer ring on four bezel posts.
- Viewer: added a Side view (the profile is the point of this revision).
**Mistakes/Challenges:**
- First v0.3 render: the back sloped in one straight line from the stack all the way to the bottom edge, so the keyboard section was nearly full depth. Cause: I built the body with `hull()` of a thick slab and a thin slab — hull is always convex and cannot make the concave "thin, then step up" corner. Fix: body is now a side-profile polygon extruded across the width, intersected with the rounded plan outline. The Side view caught it immediately.
**Improvements/Decisions:**
- Kept the screen landscape (wider text lines) — portrait would save ~5 mm of width but halve line length on a text device.
- Didn't swap the Pi active cooler for a passive heatsink to save height: Phase 1 measured 70 °C at full load *with* the fan; losing it risks throttling during inference.
**Hardware/Tools used:** None physical.
**Next:** Measure the real stack height and screen connector clearance when parts arrive — those two numbers set the final depth.

## 2026-09-24 — Enclosure v0.4: airflow redesign + steampunk styling
**Goal:** Make the enclosure look steampunk and design the airflow so the Pi stays cool inside it.
**Done:**
- **Airflow problem found in v0.3:** the Pi 5 active cooler's fan draws air in through its top, which faced the screen with only ~2.6 mm of clearance — the fan would have been starved and recirculating its own hot air, and the e-paper panel (typically rated to ~50 °C) sat directly over the SoC.
- **Fix: flipped the stack** — Pi + cooler face the back wall, X1202 + 4× 18650 face the screen. Fan now breathes through a porthole intake grille in the back wall (concentric rings + 6 spokes, ~70% open), with a 2 mm fan gap. The battery pack shields the screen from Pi heat and keeps the cells cooler (18650 charging limit ~45 °C).
- Chimney path: cool air in via porthole + low side vents, hot air out via upper side louvers + top-edge vents (all vent bands moved down to the cooler's level at the back). 4 mm domed standoff feet keep the porthole breathing when laid on its back.
- X1202 charge-port height moved to ~29 mm (it's now the front board of the stack) — VERIFY.
- **Steampunk details:** bead frames around screen and keyboard; riveted triangular corner brackets on the screen frame; riveted raised brass nameplates ("OFFLINE SURVIVAL REFERENCE", "FIELD REFERENCE MK I"); framed, riveted steam-vent plates on the side louvers and top vents; rivet line around the back plate; brass gear ring around the porthole as a separate `trim` part for two-colour printing.
- enclosure/render.sh re-renders all parts and writes stl/layout.json; viewer gained Brass trim + Airflow toggles (arrows positioned from the model's own numbers).
- Depth: 61.2 mm behind the screen (+2 mm for the fan gap vs v0.3), 11.4 mm at the keyboard, +4 mm feet.
**Mistakes/Challenges:**
- The v0.3 layout had the thermal problem baked in; I only caught it by asking where the fan actually takes its air from. Lesson for the log: design the air path first, then the shape around it.
- Write tool refused to overwrite enclosure.scad ("modified since read") because an earlier python patch had touched it — re-read, then wrote.
**Improvements/Decisions:**
- Decorative trim as a separate glue-on part so the shell can print in one colour and the brass details in another.
- Assumptions to verify on hardware: fan position on the stack (`cooler_off`), which way the cooler exhausts, and the real stack height.
**Hardware/Tools used:** None physical.
**Next:** When the enclosure is printed: log idle + inference temperatures enclosed vs open-air (Phase 1 baseline: 49 °C idle, 70 °C full load) — that's the acceptance test for this airflow design.

## 2026-09-24 — Enclosure v0.5: copper pipe details
**Goal:** Copper pipe details along both sides (steampunk).
**Done:**
- New printed part `pipes`: one pipe run per side that follows the enclosure's profile — down the thick section at 40 mm depth, a 45° elbow down the sloped step, then along the thin keyboard section. End flanges, elbow collars, 4 riveted pipe clamps per side, a pressure gauge (dial ticks + needle) on the left and a hex-body valve wheel on the right.
- D-profile pipes (flat back against the wall, centreline 0.35 r into the wall) so the part prints flat-back-down without supports and glues on; copper filament intended.
- Placement checked against every side feature: vent plates stop at 23 mm depth (pipe starts at 37.4); DC jack (26.7–35.7 mm deep at y 90.5–99.5) and USB-C (≤33.1 mm deep at y 130–140) clear the pipe and every clamp foot; on the thin section the pipe sits 0.6 mm above the back surface and under the bezel parting line.
- render.sh + viewer updated (pipes grouped with the brass trim toggle).
**Mistakes/Challenges:**
- None this round; the first clamp spacing (every 24 mm from the top) would have put a clamp foot over the DC jack on the right side — caught in the placement check before rendering, clamps moved to y = 146/122/80.
**Improvements/Decisions:**
- Pipes as a separate part (not part of the shell) keeps the shell's walls simple and lets the colour differ.
**Hardware/Tools used:** None physical.
**Next:** Unchanged — measure the real stack, screen connector clearance, fan position and port positions when parts arrive; then test-print the bezel.

## 2026-09-24 — Enclosure v0.6: the pipes become working conduits
**Goal:** Owner: "everything needs to serve a use" — make the copper pipes functional instead of decorative.
**Done:**
- Pipes are now cable conduits: 3/8" OD soft copper tube (7.9 mm bore), buildable from real copper + real 3/8" brass compression elbows/tees, or printed.
- **Left = data line:** USB 2.0 (load new books/manuals from a stick, backups), AUX I2C accessory port (external sensor modules on the same bus as the CardKB), and the gauge's RGB LED.
- **Right = power line:** 6–18 V solar/car DC input (pigtail from the X1202's DC jack) and the power-button wires.
- **Gauge = real status light** (5 mm RGB LED behind a translucent dial; battery level from the X1202 fuel gauge, "thinking" pulse) — faces forward so it's visible while reading. Covers e-ink's weakness at showing activity.
- **Valve wheel = real power button** (6×6 tactile switch in the valve body, wheel is the cap, wired to the Pi 5 J2 header); recessed below the front face so it isn't pressed by accident.
- **Junction box** under the step (behind the thin keyboard section): SOLAR 6-18V / USB / AUX I2C ports on its bottom face, screwed lid with engraved labels, fixed by 2 screws from inside the tub. Protected when held and when lying on its back.
- Lines enter the case through glands in the top face; the loops over the top corners double as roll bars. Top screw bosses moved inboard (x = 22 mm) and the top retainer posts to ±25.5 mm to clear the glands. X1202 DC cutout on the side wall removed (DC now via the junction box); USB-C 5 V 5 A stays direct.
- Model echoes per-side copper tube cut lengths; new parts: fittings, manifold, manifold_lid, gauge_face, valve_cap. docs/wiring/plumbing-conduits.md has the wire-by-wire plan and parts list.
- Size with plumbing ≈ 135 × 189 × 67 mm (from 122 × 177 × 67).
**Mistakes/Challenges:**
- First plumbing draft had the pipe clamps poking ~1 mm into the side wall (clamp radius exceeded the pipe's standoff) and fittings with only a wire bore where the tube needs a socket — both caught reviewing the code before the first render; clamps now clipped to outside the wall, fittings bored to tube OD + 0.15.
- Constraint worked around: USB/DC connectors don't fit a 7.9 mm bore, so the plan uses solderable breakouts soldered after pulling wires through.
**Improvements/Decisions:**
- Real 3/8" copper + brass compression fittings recommended over printed pipes: authentic, far stronger as roll bars, and standard hardware-store parts.
- USB-C charging not extended through a pipe (5 A through an extension is a needless risk).
**Hardware/Tools used:** None physical.
**Next:** Unchanged measurement list, plus: confirm the Pi 5 J2 button behaviour with the X1202 attached, and pick I2C accessory modules whose addresses don't clash.

## 2026-10-02 — Cost-down research: boards, models, enclosure printing
**Goal:** Owner wants to sell the device — find where cost can come down (cheaper boards, Gemma models, voice), and price the enclosure print.
**Done:**
- Three parallel research passes (models on cheap boards, current hardware prices, 3D-print services); results with sources in docs/COSTS.md.
- Measured the v0.6 enclosure STLs: 155 cm³ ≈ 190 g PLA for the full set (rear shell alone 126 g).
- Key findings: Pi prices up 3× since Dec 2025 (Pi 5 8GB $175, 4GB $110, 2GB $65–78); non-Pi boards no cheaper or unavailable in the US; Gemma 4 (2026-04-02) E2B runs ~7 tok/s on Pi 5 in 3.2 GiB but its audio input isn't dependable in llama.cpp yet; Pi 4 and Zero 2 W are dead ends; NPU HATs slower than the Pi 5 CPU for LLMs.
- Tiers: current ≈ $330 core, Pi 5 4GB ≈ $265, lean Pi 5 2GB + 1.5B model ≈ $200–215 (+ plumbing).
- Enclosure: Arlington library PLA $0.05/g ≈ $10/set (local); home A1 ≈ $4–5 filament/set; JLC3DP now carries +40% US duty.
**Mistakes/Challenges:**
- Tried to measure the device's LLM-only RAM to settle the 4GB question; the Pi was unreachable (both LAN and Tailscale timed out) — deferred.
- Research sources disagreed on Pi 5 4GB/8GB prices ($85/$125 Feb-2026 articles vs $110/$175 fetched retailer pages) — used the fetched retailer prices.
**Improvements/Decisions:**
- Biggest lever is RAM tier + model size, not board brand. Cheapest safe path to test first: Pi 5 4GB with the current model if it fits.
**Hardware/Tools used:** None physical.
**Next:** When the Pi is on: measure LLM-only RSS; benchmark Gemma 4 E2B and Qwen2.5-1.5B through the eval battery; bezel fit-test print.

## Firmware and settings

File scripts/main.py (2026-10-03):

"""
main.py — the core loop of the device.

Flow:
  1. Get a question (typed now; from Arduino serial later).
  2. Retrieve the most relevant chunks from the local index (rag_build.py output).
  3. If the question touches a safety-critical category (dosages, structural
     loads, electrical/gas, etc.), switch to strict mode: show the raw source
     text verbatim, require corroboration from more than one source file, and
     run the model at temperature 0 with no room to "fill in" a number.
  4. Ask the local LLM to answer using ONLY those chunks.
  5. Print the answer (swap print_answer() for e-ink code once the screen arrives).

Run:
    python3 main.py
"""

import pickle
import re

import faiss
from rank_bm25 import BM25Okapi
from sentence_transformers import SentenceTransformer
from llama_cpp import Llama

INDEX_PATH = "index.faiss"
CHUNKS_PATH = "chunks.pkl"
# Qwen2.5-3B-Instruct replaced Phi-3 Mini: llama.cpp renders Phi-3's
# sliding-window attention as gibberish beyond ~2047 tokens, which broke
# critical mode's 8-chunk prompts (see BUILD_LOG 2026-09-16). Qwen2.5-3B
# has 32k native context and answered the same prompt correctly.
MODEL_PATH = "models/Qwen2.5-3B-Instruct-Q4_K_M.gguf"
TOP_K = 4  # how many chunks to retrieve per question
CRITICAL_TOP_K = 8  # pull more candidates when checking for corroboration

PLAIN_LANGUAGE_RULES = (
    "Explain this in plain, everyday language, as if speaking to someone with "
    "no technical background and no tools beyond whatever they can find nearby. "
    "Do not use technical, engineering, or scientific terms (e.g. 'conduit', "
    "'exhaust channel', 'thermal mass', 'combustion chamber'). Instead describe "
    "things by what they look like and how to find or make them (e.g. 'a "
    "straight stick about as long as your arm', 'a hollow tube you could blow "
    "through', 'stack rocks into a small wall'). Break the process into small, "
    "concrete, physical actions in the order you'd actually do them, one action "
    "per step. If you must name something with no simple substitute, say the "
    "name once and immediately describe what it looks like or does in the same "
    "sentence."
)

# Retrieval can hand the model passages about a *different* subject than
# the question (e.g. fire-hardening a WOODEN knife when asked about a
# forged steel one — issue #4). The subject-match instruction below makes
# the model filter those out instead of blending them in.
SUBJECT_MATCH_RULE = (
    "The reference text may contain passages about a different subject than "
    "the question — for example a different material, tool, plant, or "
    "ailment than the one asked about. First decide which passages are truly "
    "about the question's subject, and answer ONLY from those. Ignore "
    "passages about a different subject completely; do not mix their steps "
    "or figures into the answer. If none of the passages match the "
    "question's subject, say so plainly. "
)

SYSTEM_PROMPT = (
    "You are an offline reference assistant for survival and rebuilding basic "
    "technology after losing access to modern infrastructure. Answer ONLY using "
    "the reference text provided below. If the reference text doesn't contain "
    "the answer, say so plainly instead of guessing. "
    + SUBJECT_MATCH_RULE + PLAIN_LANGUAGE_RULES
)

CRITICAL_SYSTEM_PROMPT = (
    "You are an offline reference assistant. This question involves a "
    "safety-critical figure (dosage, structural, electrical, or similar). "
    "Do NOT estimate, round, average, or infer any number that is not written "
    "explicitly in the reference text below. If a number isn't stated "
    "verbatim in the text, say 'not stated in available sources' instead of "
    "guessing. Quote the exact figure and cite which source it came from. "
    + SUBJECT_MATCH_RULE +
    "For any surrounding explanation (not the figure itself), still follow "
    "these rules: " + PLAIN_LANGUAGE_RULES
)

# Keywords that trigger strict/critical mode. Extend this list as needed.
CRITICAL_KEYWORDS = [
    "dose", "dosage", "mg", "milligram", "ml ", "overdose",
    "load", "load-bearing", "psi", "pressure", "voltage", "amp", "current",
    "gas", "propane", "carbon monoxide", "explosive", "structural", "beam",
    "weight limit", "rated for",
]


def is_critical(question: str) -> bool:
    q = question.lower()
    return any(kw in q for kw in CRITICAL_KEYWORDS)


# --- Input sources -----------------------------------------------------
# INPUT_MODE = "keyboard": type questions at a regular keyboard/terminal.
# INPUT_MODE = "serial":   read characters from the Arduino keypad over
#                          USB-serial (see keypad_serial.ino). Update
#                          SERIAL_PORT to match your Arduino (check with
#                          `ls /dev/ttyACM*` or `ls /dev/ttyUSB*` on the Pi).
INPUT_MODE = "serial"
SERIAL_PORT = "/dev/ttyACM0"
SERIAL_BAUD = 9600


class KeyboardInput:
    def get_question(self):
        return input("> ")


class SerialKeypadInput:
    """Talks to the Arduino (ir_remote_serial.ino / keypad_serial.ino).

    The Arduino buffers the whole question locally (multi-tap decoding,
    backspace, LCD preview) and sends one finished line per question.
    Arrow keys arrive as control lines: ^U / ^D scroll the answer one LCD
    line, ^L / ^R one full screen. The answer is word-wrapped to 16-char
    lines here and the Pi sends whichever two lines are in view — the
    Arduino's 2 KB of RAM can't hold a whole answer."""

    LCD_COLS = 16
    LCD_ROWS = 2
    SCROLL = {"^U": -1, "^D": 1, "^L": -2, "^R": 2}

    def __init__(self, port, baud):
        import serial  # pyserial, installed by setup.sh
        self.ser = serial.Serial(port, baud, timeout=1)
        self.lines = []
        self.top = 0
        self._buf = b""

    def _read_line(self):
        while b"\n" not in self._buf:
            self._buf += self.ser.read(64) or b""
        line, self._buf = self._buf.split(b"\n", 1)
        return line.decode(errors="ignore").strip()

    def _show(self):
        rows = [(self.lines[i] if i < len(self.lines) else "").ljust(self.LCD_COLS)
                for i in range(self.top, self.top + self.LCD_ROWS)]
        self.ser.write(("".join(rows) + "\n").encode())
        self.ser.flush()

    def get_question(self):
        print("> ", end="", flush=True)
        while True:
            line = self._read_line()
            if line in self.SCROLL:
                if self.lines:
                    last_top = max(len(self.lines) - self.LCD_ROWS, 0)
                    self.top = min(max(self.top + self.SCROLL[line], 0), last_top)
                    self._show()
                continue
            if line:
                print(line)
                return line

    def display_answer(self, text, critical=False):
        import textwrap
        if critical:
            text = "!CRITICAL! verify vs 2nd source. " + text
        self.lines = textwrap.wrap(text, self.LCD_COLS, break_long_words=True) + ["-- end --"]
        self.top = 0
        # drop arrow presses made while the answer was still generating
        self.ser.reset_input_buffer()
        self._buf = b""
        self._show()


def get_input_source():
    if INPUT_MODE == "serial":
        return SerialKeypadInput(SERIAL_PORT, SERIAL_BAUD)
    return KeyboardInput()


def load_index():
    index = faiss.read_index(INDEX_PATH)
    with open(CHUNKS_PATH, "rb") as f:
        chunks = pickle.load(f)
    return index, chunks


# Hybrid retrieval (issue #4): pure vector search missed sources when the
# query's *keywords* mattered more than its overall phrasing ("harden a
# knife I forged" ranked the blacksmithing book 7th-10th). BM25 keyword
# scores fused with vector ranks fix that without any per-query LLM cost.
RRF_K = 60          # standard reciprocal-rank-fusion constant
CANDIDATE_POOL = 20  # candidates taken from each retriever before fusion

_bm25_cache = {}


def _tokenize(text):
    return re.findall(r"[a-z0-9]+", text.lower())


def _get_bm25(chunks):
    """Build (once per corpus) a BM25 index over the chunk texts.
    ~2 s for 2801 chunks on the Pi, cached for the process lifetime."""
    key = id(chunks)
    if key not in _bm25_cache:
        _bm25_cache.clear()
        _bm25_cache[key] = BM25Okapi([_tokenize(c["text"]) for c in chunks])
    return _bm25_cache[key]


def retrieve(question, embedder, index, chunks, k=TOP_K):
    # Dense (semantic) candidates
    q_emb = embedder.encode([question], convert_to_numpy=True)
    _, vec_ids = index.search(q_emb, CANDIDATE_POOL)

    # Sparse (keyword) candidates
    bm25 = _get_bm25(chunks)
    kw_scores = bm25.get_scores(_tokenize(question))
    kw_ids = sorted(range(len(chunks)), key=lambda i: -kw_scores[i])[:CANDIDATE_POOL]

    # Reciprocal rank fusion
    fused = {}
    for rank, i in enumerate(vec_ids[0]):
        if i != -1:
            fused[i] = fused.get(i, 0.0) + 1.0 / (RRF_K + rank + 1)
    for rank, i in enumerate(kw_ids):
        fused[i] = fused.get(i, 0.0) + 1.0 / (RRF_K + rank + 1)

    top = sorted(fused, key=fused.get, reverse=True)[:k]
    return [chunks[i] for i in top]


def build_messages(question, retrieved, critical=False):
    """Chat-format messages. Using the model's own chat template (via
    create_chat_completion) instead of a raw completion prompt — raw
    prompts produced template artifacts and duplicated answers with
    instruct-tuned models in the Phase 4 eval."""
    context = "\n\n".join(
        f"[Source: {r['source']}]\n{r['text']}" for r in retrieved
    )
    system = CRITICAL_SYSTEM_PROMPT if critical else SYSTEM_PROMPT
    return [
        {"role": "system", "content": system},
        {"role": "user", "content": f"REFERENCE TEXT:\n{context}\n\nQUESTION: {question}"},
    ]


def generate_answer(llm, question, retrieved, critical=False, max_tokens=400):
    """Single entry point for generation — main loop, verify.py and
    eval_questions.py all call this so they can never drift apart."""
    messages = build_messages(question, retrieved, critical=critical)
    output = llm.create_chat_completion(
        messages=messages,
        max_tokens=max_tokens,
        temperature=0.0 if critical else 0.3,
    )
    return output["choices"][0]["message"]["content"]


def corroboration_check(retrieved):
    """Returns the set of distinct source files backing this answer.
    Fewer than 2 distinct sources means the figure is uncorroborated."""
    return {r["source"] for r in retrieved}


def print_answer(answer, critical=False, sources=None, raw_chunks=None):
    # Swap this out for e-ink drawing code once the display is wired up.
    print("\n" + "=" * 60)
    if critical:
        print("⚠ SAFETY-CRITICAL QUESTION — verify against a second source before acting.\n")
        if sources and len(sources) < 2:
            print("⚠ Only ONE source in your library backs this — treat with extra caution.\n")
        if raw_chunks:
            print("--- Raw source text (verbatim, for you to check yourself) ---")
            for r in raw_chunks:
                print(f"[{r['source']}]: {r['text']}\n")
            print("--- Model's summary of the above ---")
    print(answer.strip())
    print("=" * 60 + "\n")


def main():
    print("Loading embedding model...")
    embedder = SentenceTransformer("all-MiniLM-L6-v2")

    print("Loading local index...")
    index, chunks = load_index()

    print("Loading LLM (this can take a moment on first load)...")
    # n_ctx=4096: the model is a 4k-context model, and critical mode's
    # 8-chunk retrieval overflows 2048 (crashed with "Requested tokens
    # (3470) exceed context window of 2048" in the Phase 4 eval).
    llm = Llama(model_path=MODEL_PATH, n_ctx=4096, n_threads=4)

    input_source = get_input_source()
    print("\nOffline reference assistant ready. Type a question, or 'quit' to exit.\n")

    while True:
        question = input_source.get_question().strip()
        if question.lower() in ("quit", "exit"):
            break
        if not question:
            continue

        critical = is_critical(question)
        k = CRITICAL_TOP_K if critical else TOP_K
        retrieved = retrieve(question, embedder, index, chunks, k=k)
        answer = generate_answer(llm, question, retrieved, critical=critical)

        sources = corroboration_check(retrieved) if critical else None
        print_answer(answer, critical=critical, sources=sources, raw_chunks=retrieved if critical else None)
        if isinstance(input_source, SerialKeypadInput):
            input_source.display_answer(answer, critical=critical)


if __name__ == "__main__":
    main()

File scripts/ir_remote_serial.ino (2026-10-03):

/*
  ir_remote_serial.ino — IR remote multi-tap text entry + LCD1602 (I2C)

  Replaces the 4x4 membrane keypad, which shipped defective (internal
  shorts on ribbon lines 1-8 and 4-6 — see BUILD_LOG 2026-09-18).
  Input device: the LAFVIN kit's NEC IR remote (arrows/OK + 1-9,*,0,#).

  Typing (old-phone multi-tap, same scheme as the keypad design):
    2=abc2 3=def3 4=ghi4 5=jkl5 6=mno6 7=pqrs7 8=tuv8 9=wxyz9
    1 = 1 . , ? ! '     0 = space
    * = backspace       # = SEND question to the Pi
    OK = commit the letter in progress immediately
    Down/Up = scroll the answer one line, Right/Left = one full screen
              (only when nothing is being typed)
  A letter also commits after LETTER_TIMEOUT_MS or when a different
  button is pressed.

  The full question is buffered here (LCD preview while typing) and one
  finished line + '\n' goes to the Pi on '#'. Answer pages come back
  over serial (paced by main.py) and are shown across both LCD rows.

  Wiring:
    IR receiver (G/R/Y): G->GND, R->5V (or IOREF), Y->D2
    LCD1602 I2C backpack: GND->GND, VCC->5V, SDA->A4, SCL->A5

  Libraries: IRremote (v4+), LiquidCrystal I2C (Frank de Brabander).

  Button codes measured from the actual remote on 2026-09-18
  (NEC protocol, IrReceiver.decodedIRData.command):
*/

#include <IRremote.hpp>
#include <Wire.h>
#include <LiquidCrystal_I2C.h>

const int IR_PIN = 2;
const byte LCD_ADDR = 0x27;   // try 0x3F if the display stays blank
LiquidCrystal_I2C lcd(LCD_ADDR, 16, 2);

// measured NEC command codes -> logical keys
char irToKey(uint8_t cmd) {
  switch (cmd) {
    case 0x16: return '1';
    case 0x19: return '2';
    case 0x0D: return '3';
    case 0x0C: return '4';
    case 0x18: return '5';
    case 0x5E: return '6';
    case 0x08: return '7';
    case 0x1C: return '8';
    case 0x5A: return '9';
    case 0x52: return '0';
    case 0x42: return '*';
    case 0x4A: return '#';
    case 0x40: return 'K';  // OK
    case 0x46: return 'U';  // up
    case 0x15: return 'D';  // down
    case 0x44: return 'L';  // left
    case 0x43: return 'R';  // right
    default:   return 0;
  }
}

// ---------- multi-tap state ----------
const char *TAP_MAP[10] = {
  " ",        // 0 -> space
  "1.,?!'",   // 1 -> digit + punctuation
  "abc2", "def3", "ghi4", "jkl5", "mno6", "pqrs7", "tuv8", "wxyz9"
};
const unsigned long LETTER_TIMEOUT_MS = 1200;

char questionBuf[81];
byte qLen = 0;
char pendingKey = 0;
byte pendingTaps = 0;
unsigned long lastTapMs = 0;

// ---------- incoming answer line ----------
char lineBuf[41];
byte lineLen = 0;

void showTyping() {
  lcd.clear();
  lcd.setCursor(0, 0);
  lcd.print(F("Ask:"));
  char preview = pendingKey ? TAP_MAP[pendingKey - '0'][pendingTaps] : 0;
  byte total = qLen + (preview ? 1 : 0);
  byte start = (total > 16) ? total - 16 : 0;
  lcd.setCursor(0, 1);
  for (byte i = start; i < qLen && i < start + 16; i++) lcd.print(questionBuf[i]);
  if (preview && qLen - start < 16) lcd.print(preview);
}

void commitPending() {
  if (!pendingKey) return;
  if (qLen < sizeof(questionBuf) - 1) {
    questionBuf[qLen++] = TAP_MAP[pendingKey - '0'][pendingTaps];
    questionBuf[qLen] = 0;
  }
  pendingKey = 0;
  pendingTaps = 0;
}

void showAnswerLine(const char *s) {
  lcd.clear();
  lcd.setCursor(0, 0);
  for (byte i = 0; s[i] && i < 16; i++) lcd.print(s[i]);
  lcd.setCursor(0, 1);
  for (byte i = 16; s[i] && i < 32; i++) lcd.print(s[i]);
}

void handleKey(char key) {
  if (key >= '0' && key <= '9') {
    const char *opts = TAP_MAP[key - '0'];
    if (key == pendingKey) {
      pendingTaps = (pendingTaps + 1) % strlen(opts);
    } else {
      commitPending();
      pendingKey = key;
      pendingTaps = 0;
      if (strlen(opts) == 1) commitPending();  // '0' = instant space
    }
    lastTapMs = millis();
  } else if (key == 'U' || key == 'D' || key == 'L' || key == 'R') {
    // arrows scroll the answer on the Pi side; ignored while typing
    if (qLen == 0 && !pendingKey) {
      Serial.print('^');
      Serial.print(key);
      Serial.print('\n');
    }
    return;                            // leave the answer on screen
  } else if (key == 'K') {           // OK: commit letter now
    commitPending();
  } else if (key == '*') {           // backspace
    if (pendingKey) { pendingKey = 0; pendingTaps = 0; }
    else if (qLen > 0) { questionBuf[--qLen] = 0; }
  } else if (key == '#') {           // send to Pi
    commitPending();
    if (qLen > 0) {
      Serial.print(questionBuf);
      Serial.print('\n');
      lcd.clear();
      lcd.print(F("Thinking..."));
      lcd.setCursor(0, 1);
      lcd.print(F("(30-90 sec)"));
      qLen = 0;
      questionBuf[0] = 0;
      return;                        // keep "Thinking" on screen
    }
  }
  showTyping();
}

void setup() {
  Serial.begin(9600);
  IrReceiver.begin(IR_PIN, ENABLE_LED_FEEDBACK);
  lcd.init();
  lcd.backlight();
  lcd.print(F("Survival ref."));
  lcd.setCursor(0, 1);
  lcd.print(F("Type & press #"));
}

void loop() {
  if (pendingKey && millis() - lastTapMs > LETTER_TIMEOUT_MS) {
    commitPending();
    showTyping();
  }

  if (IrReceiver.decode()) {
    bool isRepeat = IrReceiver.decodedIRData.flags & IRDATA_FLAGS_IS_REPEAT;
    uint8_t cmd = IrReceiver.decodedIRData.command;
    IrReceiver.resume();
    if (!isRepeat) {                 // held button = one press
      char key = irToKey(cmd);
      if (key) handleKey(key);
    }
  }

  while (Serial.available()) {
    char c = Serial.read();
    if (c == '\n') {
      lineBuf[lineLen] = 0;
      if (lineLen > 0) showAnswerLine(lineBuf);
      lineLen = 0;
    } else if (lineLen < sizeof(lineBuf) - 1) {
      lineBuf[lineLen++] = c;
    }
  }
}

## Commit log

2026-09-16 phase1: system verified — OS upgraded, SPI on, fan fixed, thermals logged
    Idle 49-50C, load plateau 70C at 3600rpm, throttled=0x0. Fan was
    disabled at boot (unseated connector) — root cause + fix in BUILD_LOG.
2026-09-16 phase2: llama.cpp built, Phi-3 Mini running — pp 18.7 t/s, tg 4.7 t/s
    setup.sh quick test now uses -st: current llama-cli defaults to
    interactive chat mode and hangs when run detached (log grew to 3.9GB).
    Full failure analysis in BUILD_LOG.
2026-09-16 phase3: index FM 21-76 + farming 1905 + blacksmithing 1889 — 1310 chunks
    Retrieval spot-checks pass on fire/water/shelter. Sources logged in
    CORPUS_SOURCES.md. Index built on-Pi in 2m20s.
2026-09-16 corpus: add Hesperian doctor/dentist books as FREE-licensed, local-only
    corpus/free/ gitignored — freely distributed by Hesperian for use, but
    not public domain, so not redistributed via this public repo.
2026-09-16 phase4: add eval_questions.py — fixed 10-question evaluation battery
    [eval_questions.py]
2026-09-16 phase4 fix: n_ctx 2048→4096 — critical mode's 8 chunks overflowed context
    Eval run 1 crashed on the critical question: 'Requested tokens (3470)
    exceed context window of 2048'. Model is 4k; use it.
    [eval_questions.py, main.py, verify.py]
2026-09-16 phase4: switch engine to Qwen2.5-3B-Instruct + chat-template generation
    Root cause of critical-mode gibberish: llama.cpp renders Phi-3's
    sliding-window attention as garbage past ~2047 tokens — reproduced with
    both the original and Phi-3.1 GGUFs, in llama-cpp-python AND llama-cli,
    raw prompt AND chat template. Qwen2.5-3B (32k ctx) answers the same
    3.4k-token prompt correctly, quoting the aspirin dose verbatim.
    All generation now goes through main.generate_answer() using the
    model's own chat template (fixes run-1 template artifacts too).
    [eval_questions.py, main.py, verify.py]
2026-09-16 phase4: verify.py — 6 real test cases incl. critical-mode dose + out-of-corpus canary
2026-09-16 phase4 complete: eval logged, critical mode verified, verify.py clean
    Full overnight session log in BUILD_LOG: 3 eval runs, Phi-3 SWA root
    cause, Qwen2.5-3B swap, end-to-end critical-mode verification, 6-case
    verify.py run. Retrieval robustness deferred as issue #4.
2026-09-16 log: Tailscale remote access set up — ssh pi works from any network
2026-09-16 issue #4: hybrid BM25+vector retrieval with RRF — hit@4 94%→100%
    Adds eval_retrieval.py (16-query retrieval regression suite) and
    rank-bm25 to setup.sh. Full generation battery re-run: no regressions,
    knife-forge query now retrieves the blacksmithing book.
    [eval_retrieval.py, main.py]
2026-09-16 issue #4 closed: subject-match prompt rule + Woodworth 1903 fills corpus gap
    The forged-knife failure was a missing book, not a model flaw: no source
    contained blade-hardening instructions. Corpus now 3157 chunks/6 sources;
    eval_retrieval 16/16 under stricter expectations; Q8 answers with real
    bladesmithing (cherry red, oil-quench edge, water).
    [eval_retrieval.py, main.py]
2026-09-16 corpus: add knots 1912, navigation 1917, chemistry 1906 — 4310 chunks/9 sources
    eval_retrieval extended to 22 cases, 100% hit@4, no regressions.
    CORPUS_CHECKLIST updated: 14 items done.
2026-09-16 phase5a prep: multi-tap keypad entry + LCD1602 answer display
    keypad_serial.ino: phone-style multi-tap, on-Arduino question buffer
    with LCD preview, answer pages shown on the 16x2. main.py: paced
    32-char answer paging over serial, critical-mode warning prefix.
    Wiring guide in docs/wiring/phase5a-keypad-lcd.md. Kit identified as
    LAFVIN UNO R3 kit — no purchases needed for 5a.
2026-09-17 phase5a: LCD is the I2C variant — 4-wire hookup, LiquidCrystal_I2C
    Owner's kit LCD has an I2C backpack (GND/VCC/SDA/SCL); drops the pot,
    resistor, and 16-pin breadboard mounting from the wiring.
2026-09-18 phase5a: IR remote replaces defective keypad; device runs in serial mode
    Membrane keypad shipped with internal shorts (ribbon lines 1-8, 4-6
    permanently closed = stuck A/0 keys) — diagnosed via pair-scan sketch.
    Pivoted to the kit's NEC IR remote: same multi-tap scheme, codes
    measured from hardware. Standalone test: 'fire' typed on remote,
    received verbatim over serial.
    [ir_remote_serial.ino, main.py]
2026-09-18 phase5a COMPLETE: first hardware question answered on-device
    'fire' asked via IR remote multi-tap, answered from FM 21-76, paged on
    LCD. Full keypad-failure forensics + IR pivot logged; wiring photos in
    docs/wiring/; defective keypad recorded in HARDWARE.md (issue #5).
2026-09-19 phase5a: systemd service — device serves from power-on
    Restart=always retries until the Arduino enumerates; no network deps.
2026-09-19 log: appliance mode verified — cold boot to ready in ~60s, unattended
2026-09-24 phase7: parametric enclosure draft v0.2 + 3D viewer (not print-ready)
    OpenSCAD model: rear tub, front bezel, retainer plate; ghost parts for
    the Pi 5/X1202 stack, 4.2in e-ink and CardKB. Datasheet dimensions are
    tagged VERIFY pending caliper measurements of the real parts.
    [bezel.stl, enclosure.scad, ghost_eink.stl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]
2026-09-24 phase7: enclosure v0.3 — manufacturer dimensions, stepped slim profile
    59 mm deep behind the screen (was 74.3), 11.4 mm at the keyboard. E-ink
    and CardKB sizes from Waveshare/M5Stack specs; stack height still VERIFY.
    [bezel.stl, enclosure.scad, ghost_eink.stl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]
2026-09-24 phase7: enclosure v0.4 — flipped stack + porthole intake, steampunk details
    Pi cooler now breathes through a back porthole instead of facing the
    screen with 2.6 mm clearance; batteries shield the e-paper panel.
    Bead frames, riveted nameplates, framed louvers, brass gear trim part.
    Viewer: Airflow overlay driven by the model's layout.json.
    [bezel.stl, enclosure.scad, ghost_eink.stl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]
2026-09-24 phase7: enclosure v0.5 — copper pipe runs with gauge and valve wheel
    Flat-backed glue-on part following the side profile; placed clear of
    vents and X1202 charge ports.
    [enclosure.scad, pipes.stl]
2026-09-24 phase7: enclosure v0.6 — pipes become working conduits
    Left data line (USB, AUX I2C, status-light gauge), right power line
    (6-18V solar input, valve-wheel power button), junction box under the
    step. 3/8in copper + brass compression fittings; wiring plan in
    docs/wiring/plumbing-conduits.md.
    [bezel.stl, enclosure.scad, fittings.stl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]
2026-10-02 docs: cost analysis — hardware tiers, models on cheaper Pis, print pricing
2026-10-03 remote: arrow keys scroll answers on the LCD
    Down/Up = one line, Right/Left = one screen, '-- end --' marks the
    bottom. Pi keeps the word-wrapped answer and sends the two lines in
    view (the UNO's 2 KB RAM can't hold an answer). Replaces 3 s auto-paging.
    [ir_remote_serial.ino, main.py]
2026-10-03 eval: eval_models.py — per-model shoot-out with TTFT, tok/s, peak RAM
    Same pipeline as the device; adds refusal and dosage cases.

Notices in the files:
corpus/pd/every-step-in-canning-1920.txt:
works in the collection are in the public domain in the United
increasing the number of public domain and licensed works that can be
